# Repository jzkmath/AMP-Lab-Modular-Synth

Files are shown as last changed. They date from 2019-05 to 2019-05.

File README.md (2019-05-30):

# AMP Lab Modular Synth
This is a fully modular eurorack synthesizer project, where I design all the circuits myself, or do designs based off of existing modules.

All PCBs will be designed in KiCAD so that the entire project can be made open source and used by anyone interested. 

## Important Links:
[AMP Lab Project Page](https://sites.google.com/a/vt.edu/amp_lab/projects/modular-eurorack-synth)

[YuSynth](http://yusynth.net/Modular/modular.html) - Basis for some of the designs

[Moog Werkstatt](https://www.moogmusic.com/products/werkstatt-01) - Basis for some of the designs

## VCO
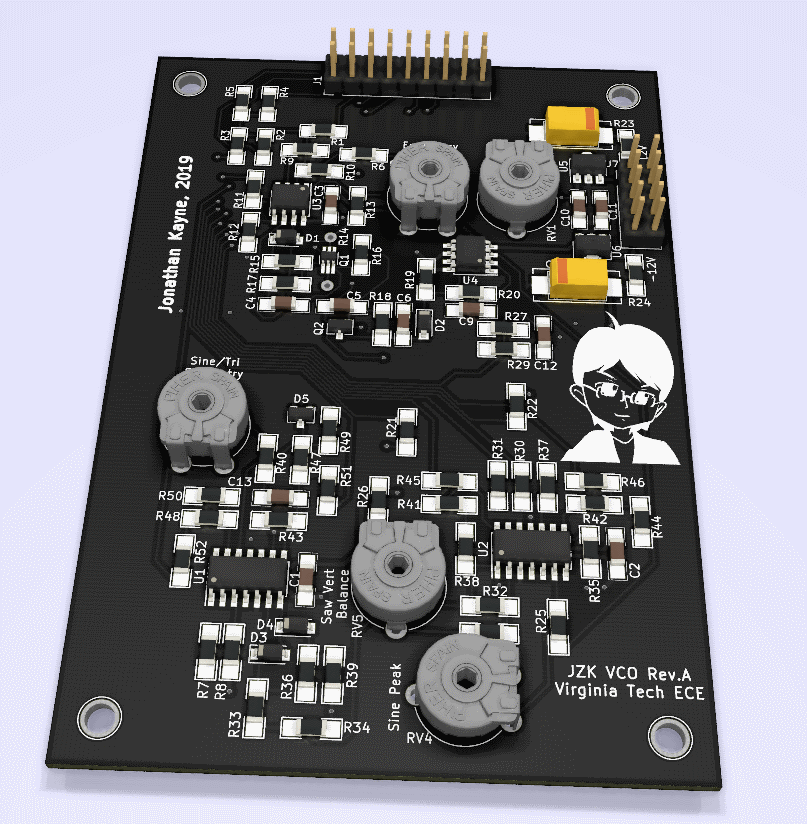
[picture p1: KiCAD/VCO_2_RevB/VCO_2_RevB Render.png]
VCO Render

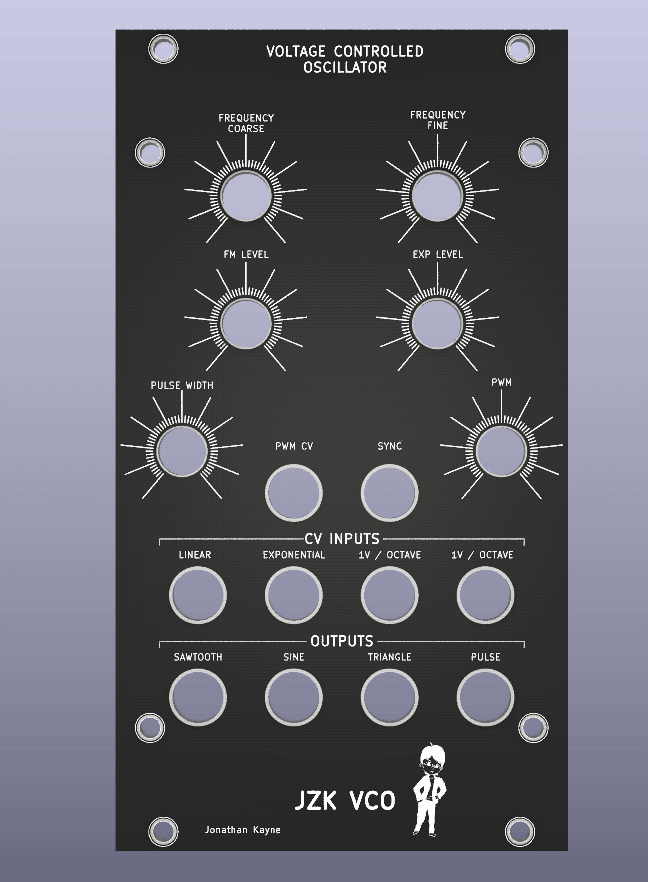
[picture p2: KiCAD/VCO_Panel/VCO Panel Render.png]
VCO Panel


## VCF
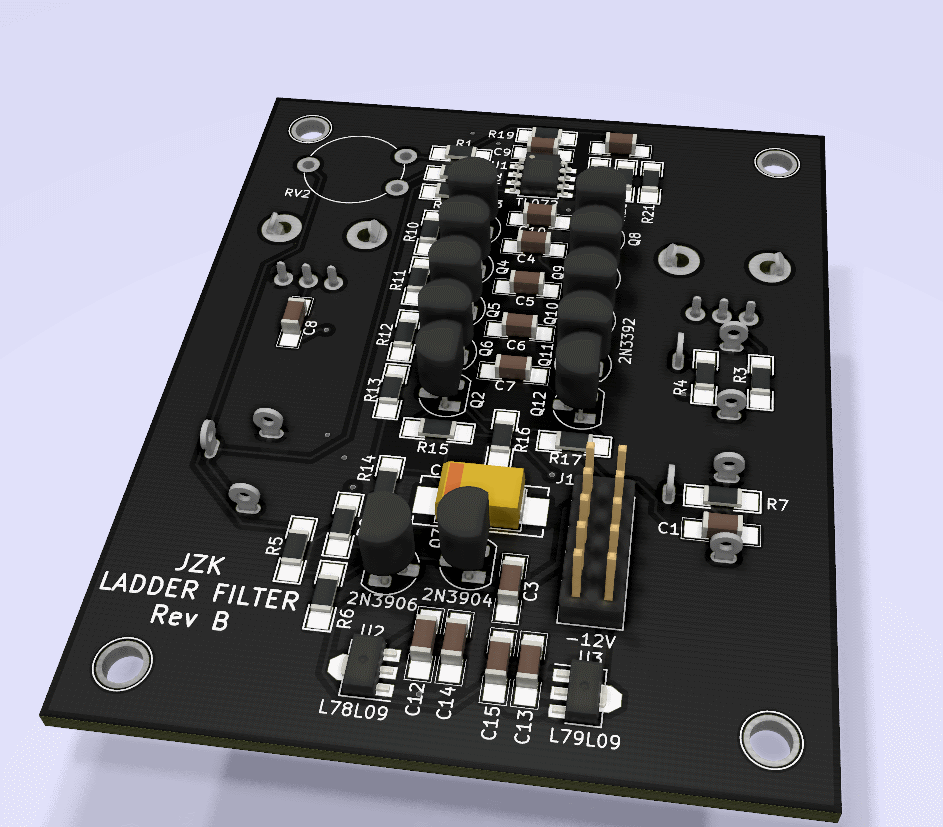
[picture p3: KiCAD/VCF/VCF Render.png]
VCF Render

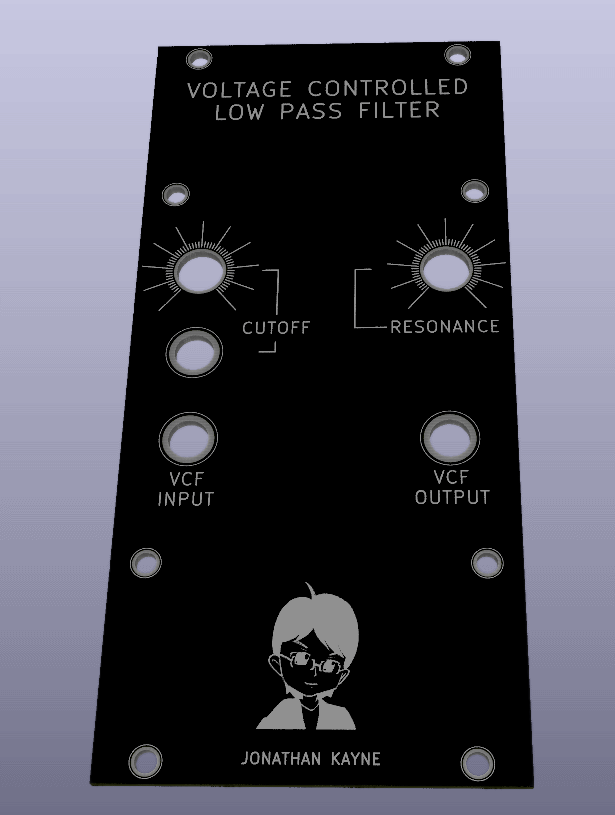
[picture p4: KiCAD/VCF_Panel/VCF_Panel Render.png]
VCF Panel


## EG
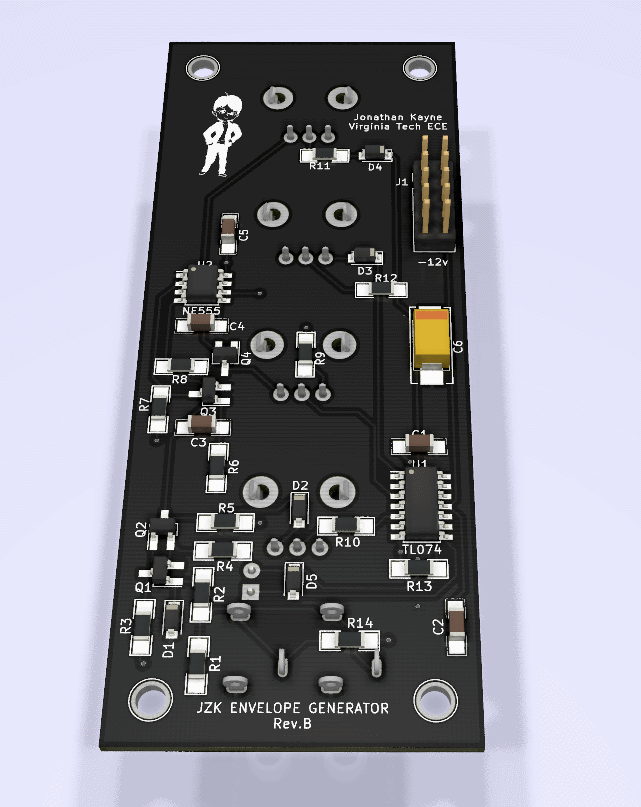
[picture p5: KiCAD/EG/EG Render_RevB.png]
EG Render

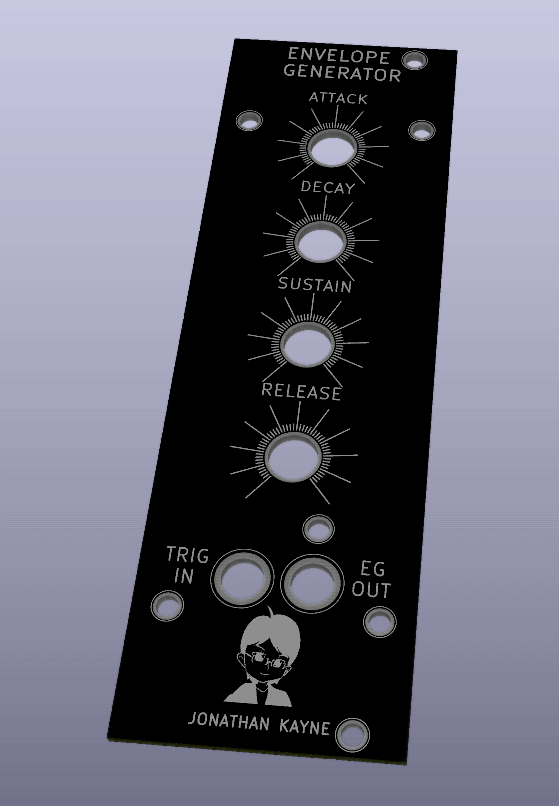
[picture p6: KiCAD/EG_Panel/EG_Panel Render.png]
EG Panel


## VCA
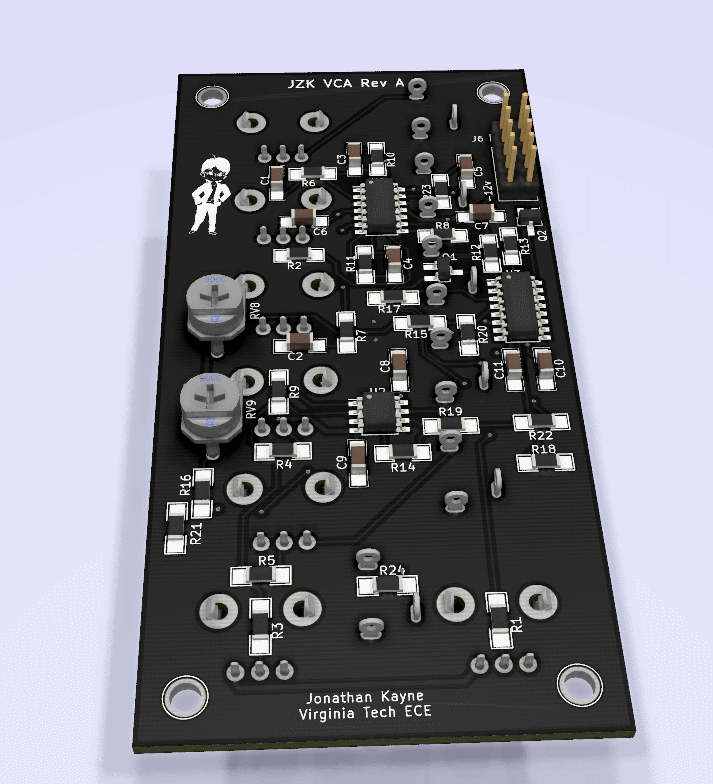
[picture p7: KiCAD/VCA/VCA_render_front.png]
VCA Render

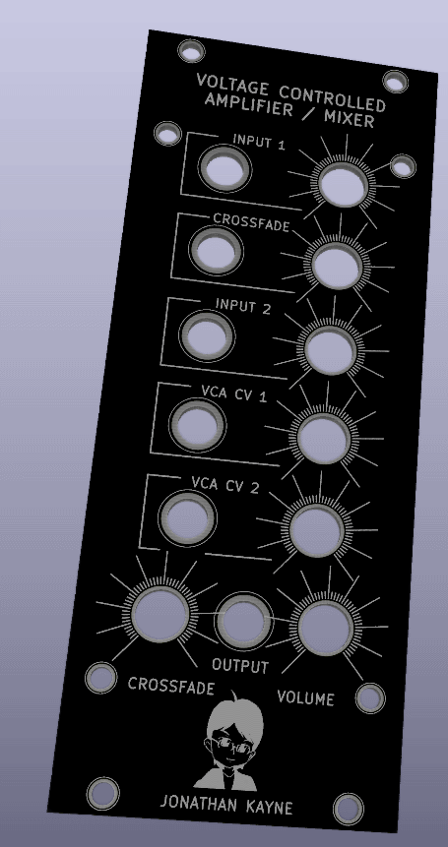
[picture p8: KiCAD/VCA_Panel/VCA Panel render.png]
VCA Panel


## MIDI Controller
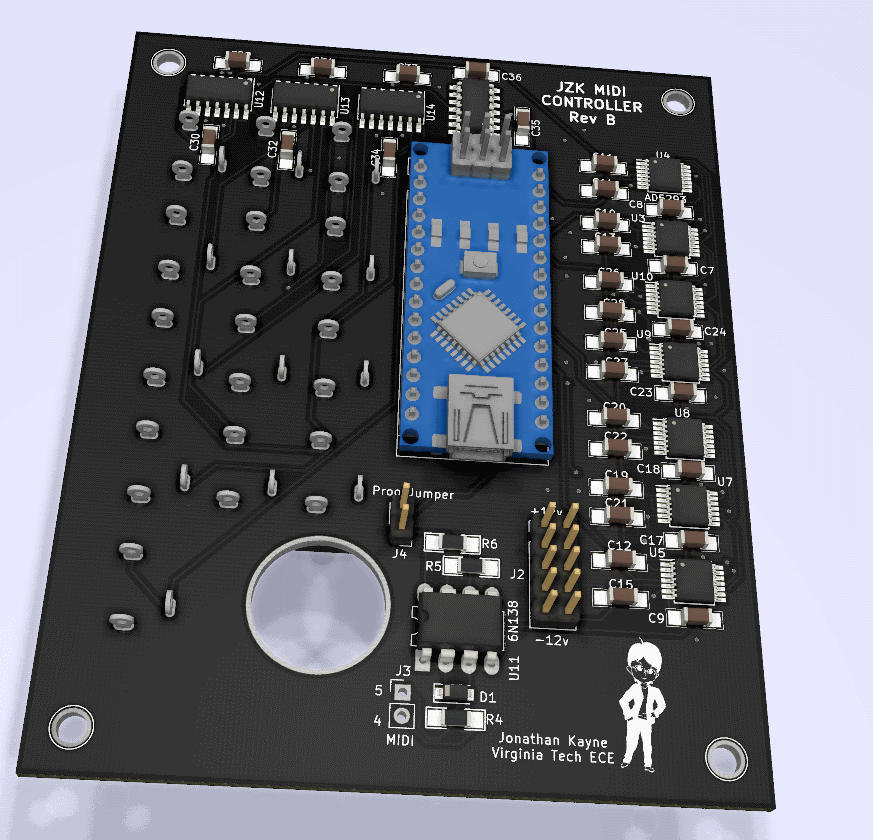
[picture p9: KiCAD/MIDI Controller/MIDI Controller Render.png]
MIDI Render

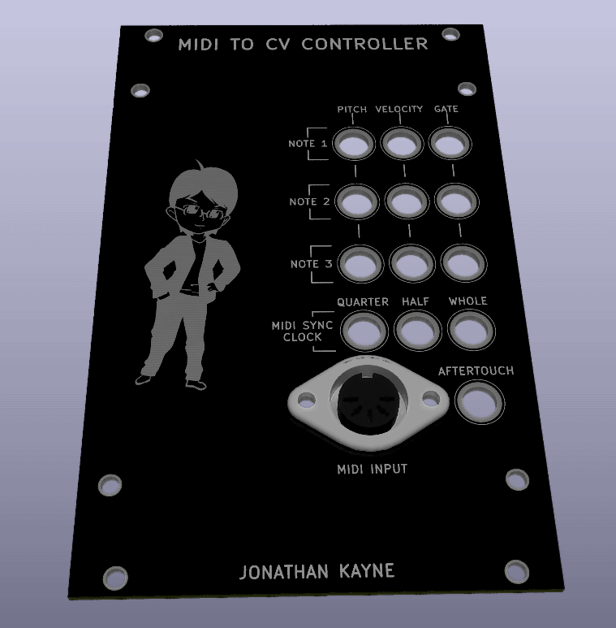
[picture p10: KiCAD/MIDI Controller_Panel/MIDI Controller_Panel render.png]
MIDI Panel


## Power Supply
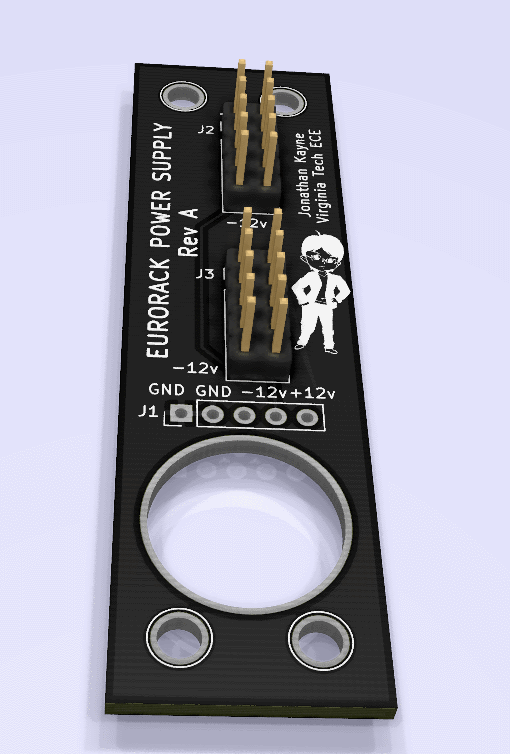
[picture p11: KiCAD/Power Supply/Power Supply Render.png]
PSU Render

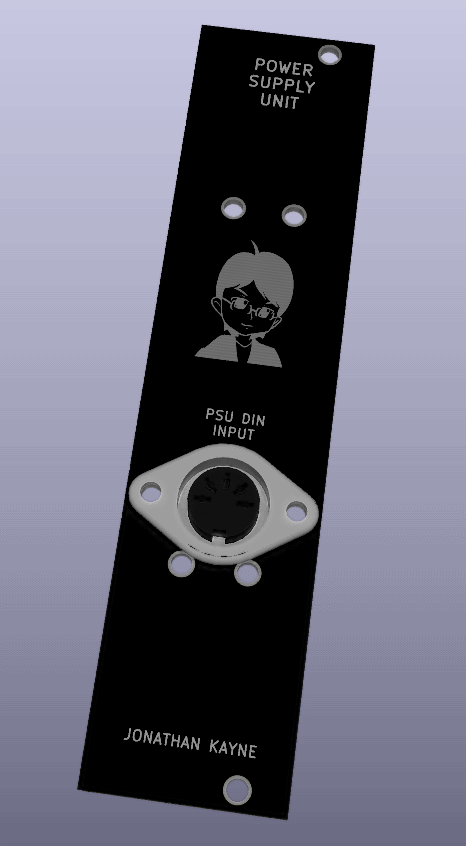
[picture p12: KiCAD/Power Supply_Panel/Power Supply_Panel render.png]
PSU Panel


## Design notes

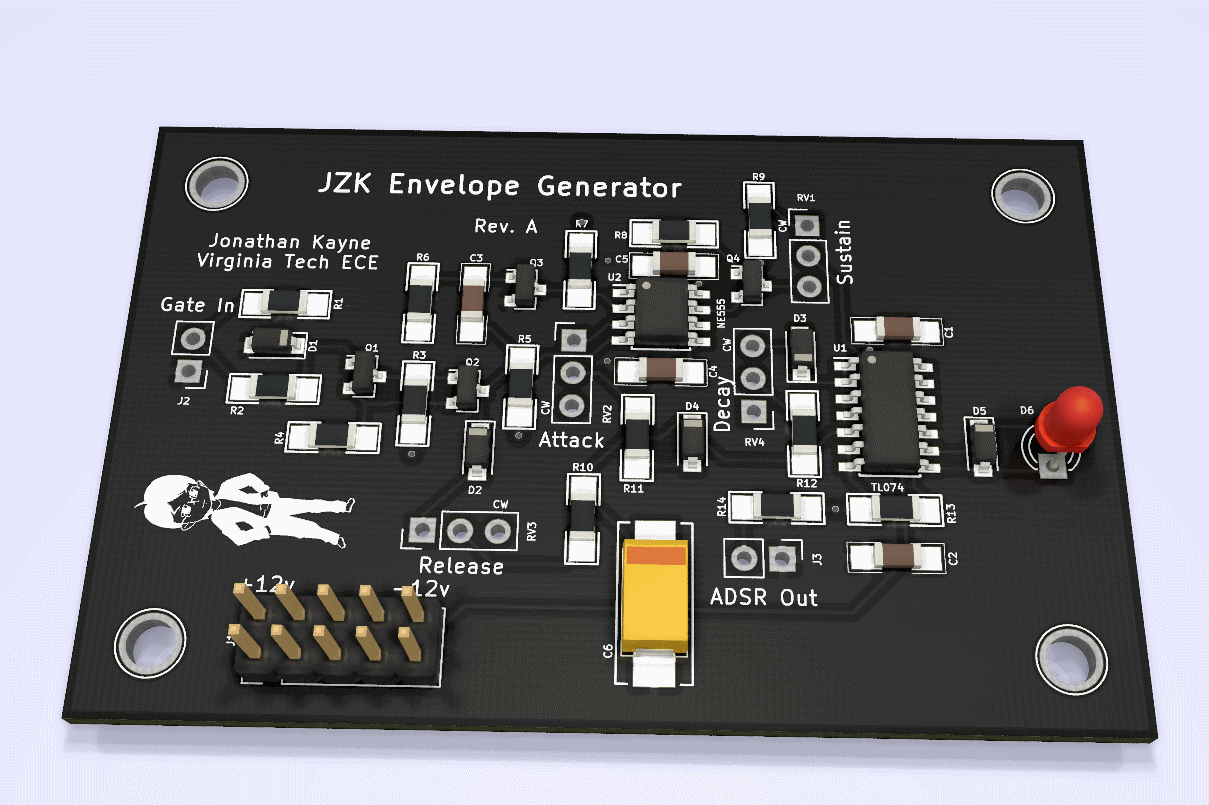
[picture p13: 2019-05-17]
KiCAD/EG/EG Render.png

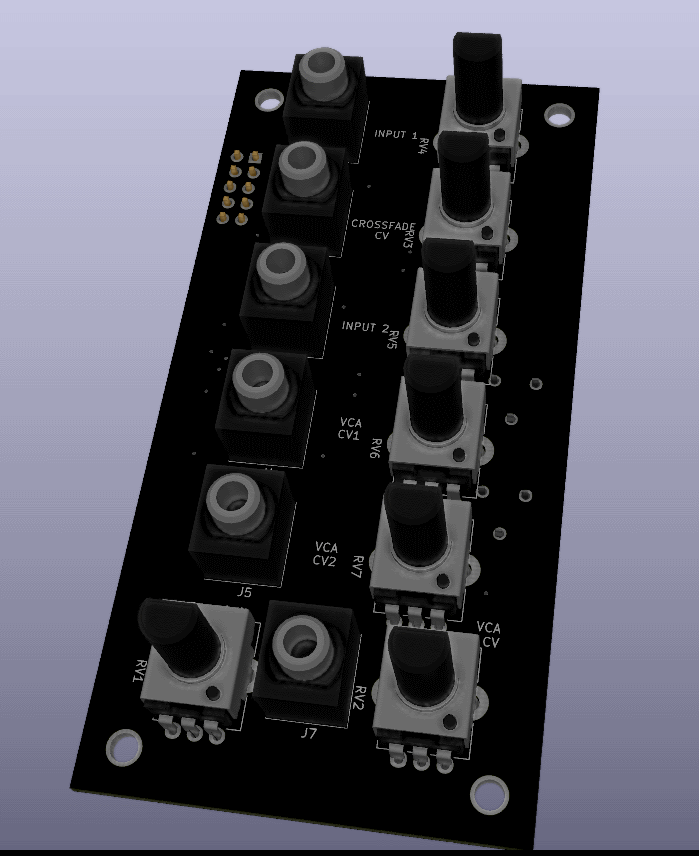
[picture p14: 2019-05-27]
KiCAD/VCA/VCA_render_back.png

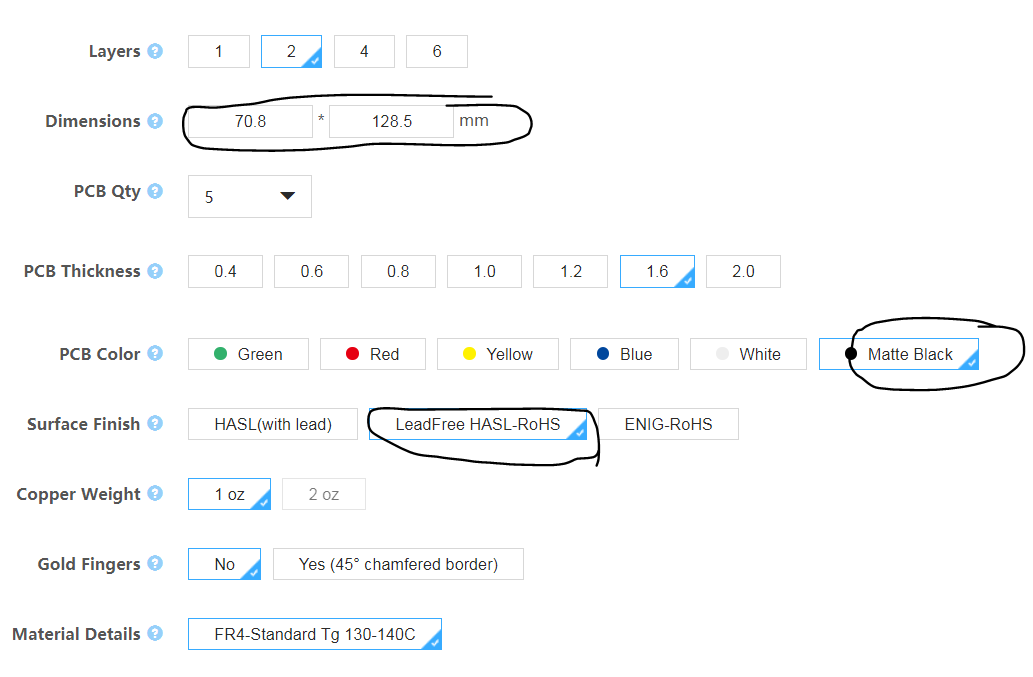
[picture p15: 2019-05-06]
KiCAD/VCO_Panel/Gerber/PCB Quote.PNG

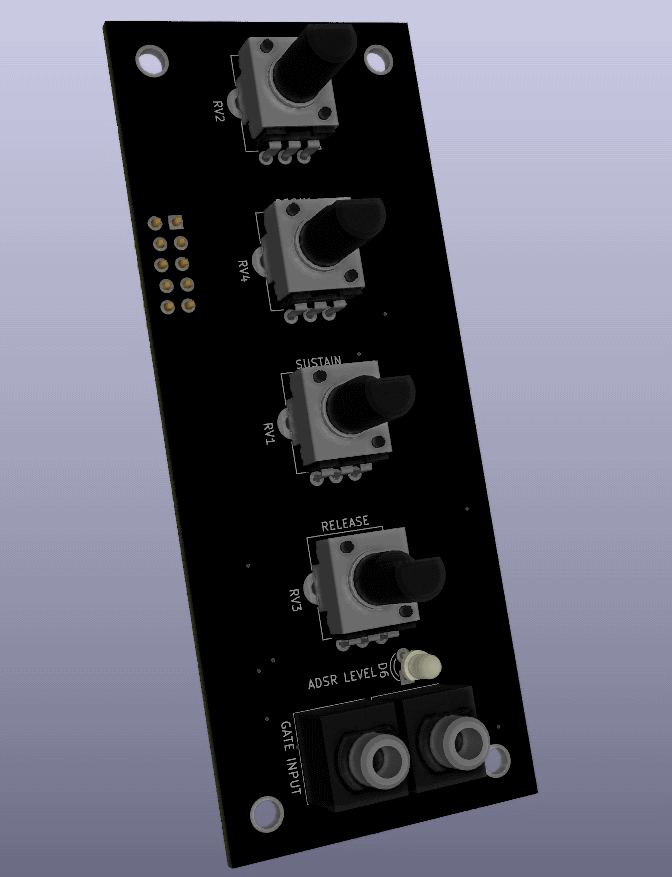
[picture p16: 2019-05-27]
KiCAD/EG/EG Render_RevB_Bottom.png

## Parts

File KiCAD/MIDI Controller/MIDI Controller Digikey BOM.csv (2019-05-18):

Manufacturer Part Number | Manufacturer | Digi-Key Part Number | Customer Reference | Reference Designator | Packaging | Part Status | Quantity | Unit Price | Extended Price | Quantity Available | Mfg Std Lead Time | Description | RoHS Status | Lead Free Status | REACH Status | US Tariff Status
AWSCR-16.00MTD-T | Abracon LLC | 535-9362-1-ND |  |  | Cut Tape (CT) | Active | 5 | 0.41000 | $2.05 | 19006 | 12 Weeks | CER RES 16.0000MHZ 22PF SMD | RoHS Compliant | Contains lead | REACH Affected | Tariff Applied
ATMEGA328P-AUR | Microchip Technology | ATMEGA328P-AURCT-ND |  |  | Cut Tape (CT) | Active | 1 | 2.14000 | $2.14 | 43519 | 7 Weeks | IC MCU 8BIT 32KB FLASH 32TQFP | RoHS Compliant | Lead free | REACH Unaffected
VJ1206Y104KXACW1BC | Vishay Vitramon | 720-1540-1-ND |  |  | Cut Tape (CT) | Active | 30 | 0.23700 | $7.11 | 3905 | 14 Weeks | CAP CER 0.1UF 50V X7R 1206 | RoHS Compliant | Lead free | Not Available | Tariff Eligible
4832.2211 | Schurter Inc. | 486-3418-ND |  |  | Bulk | Active | 13 | 1.50000 | $19.50 | 144 | 23 Weeks | CONN JACK MONO 3.5MM PNL MNT | RoHS Compliant | Lead free | REACH Unaffected
67997-410HLF | Amphenol ICC (FCI) | 609-3243-ND |  |  | Bag | Active | 1 | 0.28000 | $0.28 | 45630 | 7 Weeks | CONN HEADER VERT 10POS 2.54MM | RoHS Compliant | Lead free | Not Available | Tariff Applied
TL074CDR | Texas Instruments | 296-1283-1-ND |  |  | Cut Tape (CT) | Active | 5 | 0.60000 | $3.00 | 70322 | 12 Weeks | IC OPAMP JFET 3MHZ 14SOIC | RoHS Compliant | Lead free | REACH Unaffected
RC1206JR-071KL | Yageo | 311-1.0KERCT-ND |  |  | Cut Tape (CT) | Active | 5 | 0.10000 | $0.50 | 4162550 | 16 Weeks | RES SMD 1K OHM 5% 1/4W 1206 | RoHS Compliant | Lead free | REACH Unaffected | Tariff Applied
CRGCQ1206J4K7 | TE Connectivity Passive Product | A130181CT-ND |  |  | Cut Tape (CT) | Active | 5 | 0.10000 | $0.50 | 101159 | 28 Weeks | CRGCQ 1206 4K7 5% | RoHS Compliant | Lead free | Not Available
RC1206FR-07220RL | Yageo | 311-220FRCT-ND |  |  | Cut Tape (CT) | Active | 5 | 0.10000 | $0.50 | 912819 | 16 Weeks | RES SMD 220 OHM 1% 1/4W 1206 | RoHS Compliant | Lead free | REACH Unaffected | Tariff Eligible
C1206C105K4RACTU | KEMET | 399-1254-1-ND |  |  | Cut Tape (CT) | Active | 10 | 0.15600 | $1.56 | 286401 | 27 Weeks | CAP CER 1UF 16V X7R 1206 | RoHS Compliant | Lead free | REACH Unaffected
C1206C475Z4VACTU | KEMET | 399-1262-1-ND |  |  | Cut Tape (CT) | Active | 5 | 0.27000 | $1.35 | 127000 | 24 Weeks | CAP CER 4.7UF 16V Y5V 1206 | RoHS Compliant | Lead free | REACH Unaffected
1N914 | ON Semiconductor | 1N914FS-ND |  |  | Bulk | Active | 1 | 0.10000 | $0.10 | 48089 | 17 Weeks | DIODE GEN PURP 100V 200MA DO35 | RoHS Compliant | Lead free | REACH Unaffected | Tariff Applied
2040002-1 | TE Connectivity AMP Connectors | A108263CT-ND |  |  | Cut Tape (CT) | Active | 1 | 2.40000 | $2.40 | 8506 | 5 Weeks | CONN RCPT USB2.0 MICRO B SMD R/A | RoHS Compliant | Lead free | Not Available | Tariff Applied
FT232RL-REEL | FTDI, Future Technology Devices International Ltd | 768-1007-1-ND |  |  | Cut Tape (CT) | Active | 1 | 4.50000 | $4.50 | 126000 | 10 Weeks | IC USB FS SERIAL UART 28-SSOP | RoHS Compliant | Lead free | REACH Unaffected
AD5293BRUZ-100-RL7 | Analog Devices Inc. | AD5293BRUZ-100-RL7CT-ND |  |  | Cut Tape (CT) | Active | 10 | 6.21800 | $62.18 | 1884 | 7 Weeks | IC DGTL POT 1024POS 100K 14TSSOP | RoHS Compliant | Lead free | REACH Unaffected
LM1117MP-5.0/NOPB | Texas Instruments | LM1117MP-5.0/NOPBCT-ND |  |  | Cut Tape (CT) | Active | 5 | 1.14000 | $5.70 | 25028 | 6 Weeks | IC REG LINEAR 5V 800MA SOT223 | RoHS Compliant | Lead free | REACH Unaffected
6N138 | Lite-On Inc. | 160-1795-ND |  |  | Tube | Active | 1 | 0.81000 | $0.81 | 4094 | 10 Weeks | OPTOISO 5KV DARL W/BASE 8DIP | RoHS Compliant | Lead free | Not Available
61300211121 | Wurth Electronics Inc. | 732-5315-ND |  |  | Bag | Active | 1 | 0.13000 | $0.13 | 125946 | 14 Weeks | CONN HEADER VERT 2POS 2.54MM | RoHS Compliant | Lead free | REACH Unaffected
QPC02SXGN-RC | Sullins Connector Solutions | S9337-ND |  |  | Bag | Active | 1 | 0.10000 | $0.10 | 389104 | 5 Weeks | CONN JUMPER SHORTING .100" GOLD | RoHS Compliant | Lead free | REACH Unaffected
SD-50SN | CUI Inc. | CP-1250-ND |  |  | Bag | Active | 1 | 3.17000 | $3.17 | 3868 | 11 Weeks | CONN RCPT FMALE DIN 5POS SOLDER | RoHS Compliant | Lead free | Not Available | Tariff Applied

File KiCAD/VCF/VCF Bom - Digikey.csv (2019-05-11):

Manufacturer Part Number | Manufacturer | Digi-Key Part Number | Customer Reference | Reference Designator | Packaging | Part Status | Quantity | Unit Price | Extended Price | Quantity Available | Mfg Std Lead Time | Description | RoHS Status | Lead Free Status | REACH Status | US Tariff Status
T491X107M025AT | KEMET | 399-9749-1-ND |  |  | Cut Tape (CT) | Active | 5 | 2.71000 | $13.55 | 33073 | 12 Weeks | CAP TANT 100UF 20% 25V 2917 | RoHS Compliant | Lead free | REACH Unaffected
2N3392 | Central Semiconductor Corp | 2N3392CS-ND |  |  | Bulk | Active | 10 | 0.66800 | $6.68 | 5219 | 20 Weeks | TRANS NPN 25V TO-92 | RoHS Compliant | Lead free | REACH Unaffected | Tariff Applied
TL072CDR | Texas Instruments | 296-1282-1-ND |  |  | Cut Tape (CT) | Active | 5 | 0.62000 | $3.10 | 60071 | 6 Weeks | IC OPAMP JFET 3MHZ 8SOIC | RoHS Compliant | Lead free | REACH Unaffected
CL31B104KBCNNNC | Samsung Electro-Mechanics | 1276-1017-1-ND |  |  | Cut Tape (CT) | Active | 10 | 0.08800 | $0.88 | 21218 | Not Available | CAP CER 0.1UF 50V X7R 1206 | RoHS Compliant | Lead free | REACH Unaffected
67997-410HLF | Amphenol ICC (FCI) | 609-3243-ND |  |  | Bag | Active | 1 | 0.28000 | $0.28 | 46149 | 7 Weeks | CONN HEADER VERT 10POS 2.54MM | RoHS Compliant | Lead free | Not Available | Tariff Applied
4832.2211 | Schurter Inc. | 486-3418-ND |  |  | Bulk | Active | 3 | 1.50000 | $4.50 | 244 | 23 Weeks | CONN JACK MONO 3.5MM PNL MNT | RoHS Compliant | Lead free | REACH Unaffected
CRGCQ1206F100K | TE Connectivity Passive Product | A129834CT-ND |  |  | Cut Tape (CT) | Active | 5 | 0.10000 | $0.50 | 105746 | 28 Weeks | CRGCQ 1206 100K 1% | RoHS Compliant | Lead free | Not Available
PT10MV10-103A2020-S | Amphenol Piher Sensing Systems | 1993-1104-ND |  |  | Bulk | Active | 1 | 0.46000 | $0.46 | 6282 | 6 Weeks | POT 10K OHM LINEAR | RoHS Compliant | Lead free | Not Available
P160KNP-0EC15B25K | TT Electronics/BI | 987-1726-ND |  |  | Tray | Active | 2 | 0.79000 | $1.58 | 663 | 10 Weeks | POT 25K OHM 1/5W PLASTIC LINEAR | RoHS Compliant | Lead free | REACH Unaffected | Tariff Eligible
RMCF1206JT33K0 | Stackpole Electronics Inc | RMCF1206JT33K0CT-ND |  |  | Cut Tape (CT) | Active | 5 | 0.10000 | $0.50 | 49098 | 17 Weeks | RES 33K OHM 5% 1/4W 1206 | RoHS Compliant | Lead free | REACH Unaffected | Tariff Applied
RNCP1206FTD4K99 | Stackpole Electronics Inc | RNCP1206FTD4K99CT-ND |  |  | Cut Tape (CT) | Active | 5 | 0.10000 | $0.50 | 87951 | 18 Weeks | RES 4.99K OHM 1% 1/2W 1206 | RoHS Compliant | Lead free | REACH Unaffected
RNCP1206FTD68K1 | Stackpole Electronics Inc | RNCP1206FTD68K1CT-ND |  |  | Cut Tape (CT) | Active | 5 | 0.10000 | $0.50 | 135983 | 18 Weeks | RES 68.1K OHM 1% 1/2W 1206 | RoHS Compliant | Lead free | REACH Unaffected
RNCP1206FTD1K00 | Stackpole Electronics Inc | RNCP1206FTD1K00CT-ND |  |  | Cut Tape (CT) | Active | 10 | 0.09300 | $0.93 | 650800 | 18 Weeks | RES 1K OHM 1% 1/2W 1206 | RoHS Compliant | Lead free | REACH Unaffected
CRGCQ1206F12K | TE Connectivity Passive Product | A129823CT-ND |  |  | Cut Tape (CT) | Active | 5 | 0.10000 | $0.50 | 30562 | 28 Weeks | CRGCQ 1206 12K 1% | RoHS Compliant | Lead free | Not Available
RC1206FR-072K74L | Yageo | 311-2.74KFRCT-ND |  |  | Cut Tape (CT) | Active | 5 | 0.10000 | $0.50 | 97937 | 16 Weeks | RES SMD 2.74K OHM 1% 1/4W 1206 | RoHS Compliant | Lead free | REACH Unaffected | Tariff Applied
RNCP1206FTD100R | Stackpole Electronics Inc | RNCP1206FTD100RCT-ND |  |  | Cut Tape (CT) | Active | 5 | 0.10000 | $0.50 | 824311 | 18 Weeks | RES 100 OHM 1% 1/2W 1206 | RoHS Compliant | Lead free | REACH Unaffected
RNCP1206FTD6K81 | Stackpole Electronics Inc | RNCP1206FTD6K81CT-ND |  |  | Cut Tape (CT) | Active | 5 | 0.10000 | $0.50 | 15785 | 18 Weeks | RES 6.81K OHM 1% 1/2W 1206 | RoHS Compliant | Lead free | REACH Unaffected
CL31B225KAHNNNE | Samsung Electro-Mechanics | 1276-1072-1-ND |  |  | Cut Tape (CT) | Active | 5 | 0.22000 | $1.10 | 419041 | Not Available | CAP CER 2.2UF 25V X7R 1206 | RoHS Compliant | Lead free | REACH Unaffected

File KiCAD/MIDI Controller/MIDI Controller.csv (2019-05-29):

Source: | C:\Users\Jonathan Kayne\Documents\KiCAD\Modular Synth\MIDI Controller\MIDI Controller.sch
Date: | 05/26/19 18:08:59
Tool: | Eeschema (5.1.0)-1
Generator: | C:\Program Files\KiCad\bin\scripting\plugins/bom_csv_grouped_by_value.py
Component Count: | 62
Individual Components:
Item | Qty | Reference(s) | Value | LibPart | Footprint | Datasheet | Digikey Link | Digikey PN | Field4 | Field5 | Field6 | Field7 | Field8 | Field9 | Unit Price
 |  | A1 | Arduino_Nano_v3.x | MCU_Module:Arduino_Nano_v3.x | Module:Arduino_Nano | http://www.mouser.com/pdfdocs/Gravitech_Arduino_Nano3_0.pdf | https://smile.amazon.com/dp/B00NLAMS9C | B00NLAMS9C |  |  |  |  |  |  | 8.99
 |  | C7 | 1uF | Device:C | Synth:C_1206 | ~ | https://www.digikey.com/short/p4nrpn | 399-1254-1-ND |  |  |  |  |  |  | 0.23
 |  | C8 | 1uF | Device:C | Synth:C_1206 | ~ | https://www.digikey.com/short/p4nrpn | 399-1254-1-ND |  |  |  |  |  |  | 0.23
 |  | C9 | 1uF | Device:C | Synth:C_1206 | ~ | https://www.digikey.com/short/p4nrpn | 399-1254-1-ND |  |  |  |  |  |  | 0.23
 |  | C10 | 0.1uF | Device:C | Synth:C_1206 | ~ | https://www.digikey.com/short/p4nr3m | 720-1540-1-ND |  |  |  |  |  |  | 0.237
 |  | C11 | 0.1uF | Device:C | Synth:C_1206 | ~ | https://www.digikey.com/short/p4nr3m | 720-1540-1-ND |  |  |  |  |  |  | 0.237
 |  | C12 | 0.1uF | Device:C | Synth:C_1206 | ~ | https://www.digikey.com/short/p4nr3m | 720-1540-1-ND |  |  |  |  |  |  | 0.237
 |  | C13 | 0.1uF | Device:C | Synth:C_1206 | ~ | https://www.digikey.com/short/p4nr3m | 720-1540-1-ND |  |  |  |  |  |  | 0.237
 |  | C14 | 0.1uF | Device:C | Synth:C_1206 | ~ | https://www.digikey.com/short/p4nr3m | 720-1540-1-ND |  |  |  |  |  |  | 0.237
 |  | C15 | 0.1uF | Device:C | Synth:C_1206 | ~ | https://www.digikey.com/short/p4nr3m | 720-1540-1-ND |  |  |  |  |  |  | 0.237
 |  | C17 | 1uF | Device:C | Synth:C_1206 | ~ | https://www.digikey.com/short/p4nrpn | 399-1254-1-ND |  |  |  |  |  |  | 0.23
 |  | C18 | 1uF | Device:C | Synth:C_1206 | ~ | https://www.digikey.com/short/p4nrpn | 399-1254-1-ND |  |  |  |  |  |  | 0.23
 |  | C19 | 0.1uF | Device:C | Synth:C_1206 | ~ | https://www.digikey.com/short/p4nr3m | 720-1540-1-ND |  |  |  |  |  |  | 0.237
 |  | C20 | 0.1uF | Device:C | Synth:C_1206 | ~ | https://www.digikey.com/short/p4nr3m | 720-1540-1-ND |  |  |  |  |  |  | 0.237
 |  | C21 | 0.1uF | Device:C | Synth:C_1206 | ~ | https://www.digikey.com/short/p4nr3m | 720-1540-1-ND |  |  |  |  |  |  | 0.237
 |  | C22 | 0.1uF | Device:C | Synth:C_1206 | ~ | https://www.digikey.com/short/p4nr3m | 720-1540-1-ND |  |  |  |  |  |  | 0.237
 |  | C23 | 1uF | Device:C | Synth:C_1206 | ~ | https://www.digikey.com/short/p4nrpn | 399-1254-1-ND |  |  |  |  |  |  | 0.23
 |  | C24 | 1uF | Device:C | Synth:C_1206 | ~ | https://www.digikey.com/short/p4nrpn | 399-1254-1-ND |  |  |  |  |  |  | 0.23
 |  | C25 | 0.1uF | Device:C | Synth:C_1206 | ~ | https://www.digikey.com/short/p4nr3m | 720-1540-1-ND |  |  |  |  |  |  | 0.237
 |  | C26 | 0.1uF | Device:C | Synth:C_1206 | ~ | https://www.digikey.com/short/p4nr3m | 720-1540-1-ND |  |  |  |  |  |  | 0.237
 |  | C27 | 0.1uF | Device:C | Synth:C_1206 | ~ | https://www.digikey.com/short/p4nr3m | 720-1540-1-ND |  |  |  |  |  |  | 0.237
 |  | C28 | 0.1uF | Device:C | Synth:C_1206 | ~ | https://www.digikey.com/short/p4nr3m | 720-1540-1-ND |  |  |  |  |  |  | 0.237
 |  | C29 | 0.1uF | Device:C | Synth:C_1206 | ~ | https://www.digikey.com/short/p4nr3m | 720-1540-1-ND |  |  |  |  |  |  | 0.237
 |  | C30 | 0.1uF | Device:C | Synth:C_1206 | ~ | https://www.digikey.com/short/p4nr3m | 720-1540-1-ND |  |  |  |  |  |  | 0.237
 |  | C31 | 0.1uF | Device:C | Synth:C_1206 | ~ | https://www.digikey.com/short/p4nr3m | 720-1540-1-ND |  |  |  |  |  |  | 0.237
 |  | C32 | 0.1uF | Device:C | Synth:C_1206 | ~ | https://www.digikey.com/short/p4nr3m | 720-1540-1-ND |  |  |  |  |  |  | 0.237
 |  | C33 | 0.1uF | Device:C | Synth:C_1206 | ~ | https://www.digikey.com/short/p4nr3m | 720-1540-1-ND |  |  |  |  |  |  | 0.237
 |  | C34 | 0.1uF | Device:C | Synth:C_1206 | ~ | https://www.digikey.com/short/p4nr3m | 720-1540-1-ND |  |  |  |  |  |  | 0.237
 |  | C35 | 0.1uF | Device:C | Synth:C_1206 | ~ | https://www.digikey.com/short/p4nr3m | 720-1540-1-ND |  |  |  |  |  |  | 0.237
 |  | C36 | 0.1uF | Device:C | Synth:C_1206 | ~ | https://www.digikey.com/short/p4nr3m | 720-1540-1-ND |  |  |  |  |  |  | 0.237
 |  | D1 | 1N4148W | Device:D | Synth:D_SOD-123 | ~ | https://www.digikey.com/short/p4nrz9 | 1N4148WTPMSCT-ND |  |  |  |  |  |  | 0.131
 |  | J2 | Power | Connector_Generic:Conn_02x05_Odd_Even | Synth:PinHeader_2x05_P2.54mm_Vertical_Zigzag | ~ | https://www.digikey.com/short/p4nr84 | 609-3243-ND |  |  |  |  |  |  | 0.27
 |  | J3 | MIDI | Connector:DIN-5_180degree | Connector_PinHeader_2.54mm:PinHeader_1x02_P2.54mm_Vertical | http://www.mouser.com/ds/2/18/40_c091_abd_e-75918.pdf | https://www.digikey.com/short/p4nrpz | CP-1250-ND |  |  |  |  |  |  | 2.99
 |  | J4 | Prog Jumper | Connector_Generic:Conn_01x02 | Connector_PinHeader_2.54mm:PinHeader_1x02_P2.54mm_Vertical | ~ | https://www.digikey.com/short/p4nrjv | 732-5315-ND |  |  |  |  |  |  | 0.13
 |  | J5 | 4832 | Synth:MJ-3502 | Synth:Schurter_4832_Jack | https://www.digikey.com/product-detail/en/cui-inc/MJ-3502/CP-3502MJ-ND/281321 | https://www.digikey.com/short/p4nrqw | 486-3418-ND | CP-3502MJ-ND | None | MJ-3502 | https://www.cui.com/product/interconnect/connectors/audio-connectors/jacks/mj-3502 | 3.5 mm, Mono, Right Angle, Through Hole, Threaded Bushing, Audio Jack Connector | CUI Inc. | 1.50
 |  | J6 | 4832 | Synth:MJ-3502 | Synth:Schurter_4832_Jack | https://www.digikey.com/product-detail/en/cui-inc/MJ-3502/CP-3502MJ-ND/281321 | https://www.digikey.com/short/p4nrqw | 486-3418-ND | CP-3502MJ-ND | None | MJ-3502 | https://www.cui.com/product/interconnect/connectors/audio-connectors/jacks/mj-3502 | 3.5 mm, Mono, Right Angle, Through Hole, Threaded Bushing, Audio Jack Connector | CUI Inc. | 1.50
 |  | J7 | 4832 | Synth:MJ-3502 | Synth:Schurter_4832_Jack | https://www.digikey.com/product-detail/en/cui-inc/MJ-3502/CP-3502MJ-ND/281321 | https://www.digikey.com/short/p4nrqw | 486-3418-ND | CP-3502MJ-ND | None | MJ-3502 | https://www.cui.com/product/interconnect/connectors/audio-connectors/jacks/mj-3502 | 3.5 mm, Mono, Right Angle, Through Hole, Threaded Bushing, Audio Jack Connector | CUI Inc. | 1.50
 |  | J8 | 4832 | Synth:MJ-3502 | Synth:Schurter_4832_Jack | https://www.digikey.com/product-detail/en/cui-inc/MJ-3502/CP-3502MJ-ND/281321 | https://www.digikey.com/short/p4nrqw | 486-3418-ND | CP-3502MJ-ND | None | MJ-3502 | https://www.cui.com/product/interconnect/connectors/audio-connectors/jacks/mj-3502 | 3.5 mm, Mono, Right Angle, Through Hole, Threaded Bushing, Audio Jack Connector | CUI Inc. | 1.50
 |  | J9 | 4832 | Synth:MJ-3502 | Synth:Schurter_4832_Jack | https://www.digikey.com/product-detail/en/cui-inc/MJ-3502/CP-3502MJ-ND/281321 | https://www.digikey.com/short/p4nrqw | 486-3418-ND | CP-3502MJ-ND | None | MJ-3502 | https://www.cui.com/product/interconnect/connectors/audio-connectors/jacks/mj-3502 | 3.5 mm, Mono, Right Angle, Through Hole, Threaded Bushing, Audio Jack Connector | CUI Inc. | 1.50
 |  | J10 | 4832 | Synth:MJ-3502 | Synth:Schurter_4832_Jack | https://www.digikey.com/product-detail/en/cui-inc/MJ-3502/CP-3502MJ-ND/281321 | https://www.digikey.com/short/p4nrqw | 486-3418-ND | CP-3502MJ-ND | None | MJ-3502 | https://www.cui.com/product/interconnect/connectors/audio-connectors/jacks/mj-3502 | 3.5 mm, Mono, Right Angle, Through Hole, Threaded Bushing, Audio Jack Connector | CUI Inc. | 1.50
 |  | J11 | 4832 | Synth:MJ-3502 | Synth:Schurter_4832_Jack | https://www.digikey.com/product-detail/en/cui-inc/MJ-3502/CP-3502MJ-ND/281321 | https://www.digikey.com/short/p4nrqw | 486-3418-ND | CP-3502MJ-ND | None | MJ-3502 | https://www.cui.com/product/interconnect/connectors/audio-connectors/jacks/mj-3502 | 3.5 mm, Mono, Right Angle, Through Hole, Threaded Bushing, Audio Jack Connector | CUI Inc. | 1.50
 |  | J12 | 4832 | Synth:MJ-3502 | Synth:Schurter_4832_Jack | https://www.digikey.com/product-detail/en/cui-inc/MJ-3502/CP-3502MJ-ND/281321 | https://www.digikey.com/short/p4nrqw | 486-3418-ND | CP-3502MJ-ND | None | MJ-3502 | https://www.cui.com/product/interconnect/connectors/audio-connectors/jacks/mj-3502 | 3.5 mm, Mono, Right Angle, Through Hole, Threaded Bushing, Audio Jack Connector | CUI Inc. | 1.50
 |  | J13 | 4832 | Synth:MJ-3502 | Synth:Schurter_4832_Jack | https://www.digikey.com/product-detail/en/cui-inc/MJ-3502/CP-3502MJ-ND/281321 | https://www.digikey.com/short/p4nrqw | 486-3418-ND | CP-3502MJ-ND | None | MJ-3502 | https://www.cui.com/product/interconnect/connectors/audio-connectors/jacks/mj-3502 | 3.5 mm, Mono, Right Angle, Through Hole, Threaded Bushing, Audio Jack Connector | CUI Inc. | 1.50
 |  | J14 | 4832 | Synth:MJ-3502 | Synth:Schurter_4832_Jack | https://www.digikey.com/product-detail/en/cui-inc/MJ-3502/CP-3502MJ-ND/281321 | https://www.digikey.com/short/p4nrqw | 486-3418-ND | CP-3502MJ-ND | None | MJ-3502 | https://www.cui.com/product/interconnect/connectors/audio-connectors/jacks/mj-3502 | 3.5 mm, Mono, Right Angle, Through Hole, Threaded Bushing, Audio Jack Connector | CUI Inc. | 1.50
 |  | J15 | 4832 | Synth:MJ-3502 | Synth:Schurter_4832_Jack | https://www.digikey.com/product-detail/en/cui-inc/MJ-3502/CP-3502MJ-ND/281321 | https://www.digikey.com/short/p4nrqw | 486-3418-ND | CP-3502MJ-ND | None | MJ-3502 | https://www.cui.com/product/interconnect/connectors/audio-connectors/jacks/mj-3502 | 3.5 mm, Mono, Right Angle, Through Hole, Threaded Bushing, Audio Jack Connector | CUI Inc. | 1.50
 |  | J16 | 4832 | Synth:MJ-3502 | Synth:Schurter_4832_Jack | https://www.digikey.com/product-detail/en/cui-inc/MJ-3502/CP-3502MJ-ND/281321 | https://www.digikey.com/short/p4nrqw | 486-3418-ND | CP-3502MJ-ND | None | MJ-3502 | https://www.cui.com/product/interconnect/connectors/audio-connectors/jacks/mj-3502 | 3.5 mm, Mono, Right Angle, Through Hole, Threaded Bushing, Audio Jack Connector | CUI Inc. | 1.50
 |  | J17 | 4832 | Synth:MJ-3502 | Synth:Schurter_4832_Jack | https://www.digikey.com/product-detail/en/cui-inc/MJ-3502/CP-3502MJ-ND/281321 | https://www.digikey.com/short/p4nrqw | 486-3418-ND | CP-3502MJ-ND | None | MJ-3502 | https://www.cui.com/product/interconnect/connectors/audio-connectors/jacks/mj-3502 | 3.5 mm, Mono, Right Angle, Through Hole, Threaded Bushing, Audio Jack Connector | CUI Inc. | 1.50
 |  | R4 | 220 | Device:R | Synth:R_1206 | ~ | https://www.digikey.com/short/p4nrjp | 311-220FRCT-ND |  |  |  |  |  |  | 0.10
 |  | R5 | 4.7k | Device:R | Synth:R_1206 | ~ | https://www.digikey.com/short/p4nr81 | A130181CT-ND |  |  |  |  |  |  | 0.10
 |  | R6 | 220 | Device:R | Synth:R_1206 | ~ | https://www.digikey.com/short/p4nrjp | 311-220FRCT-ND |  |  |  |  |  |  | 0.10
 |  | U3 | AD5293 | Potentiometer_Digital:AD5293 | Package_SO:TSSOP-14_4.4x5mm_P0.65mm | https://www.analog.com/media/en/technical-documentation/data-sheets/AD5293.pdf | https://www.digikey.com/short/pzd8zr | AD5293BRUZ-100-RL7CT-ND |  |  |  |  |  |  | 6.88
 |  | U4 | AD5293 | Potentiometer_Digital:AD5293 | Package_SO:TSSOP-14_4.4x5mm_P0.65mm | https://www.analog.com/media/en/technical-documentation/data-sheets/AD5293.pdf | https://www.digikey.com/short/pzd8zr | AD5293BRUZ-100-RL7CT-ND |  |  |  |  |  |  | 6.88
 |  | U5 | AD5293 | Potentiometer_Digital:AD5293 | Package_SO:TSSOP-14_4.4x5mm_P0.65mm | https://www.analog.com/media/en/technical-documentation/data-sheets/AD5293.pdf | https://www.digikey.com/short/pzd8zr | AD5293BRUZ-100-RL7CT-ND |  |  |  |  |  |  | 6.88
 |  | U7 | AD5293 | Potentiometer_Digital:AD5293 | Package_SO:TSSOP-14_4.4x5mm_P0.65mm | https://www.analog.com/media/en/technical-documentation/data-sheets/AD5293.pdf | https://www.digikey.com/short/pzd8zr | AD5293BRUZ-100-RL7CT-ND |  |  |  |  |  |  | 6.88
 |  | U8 | AD5293 | Potentiometer_Digital:AD5293 | Package_SO:TSSOP-14_4.4x5mm_P0.65mm | https://www.analog.com/media/en/technical-documentation/data-sheets/AD5293.pdf | https://www.digikey.com/short/pzd8zr | AD5293BRUZ-100-RL7CT-ND |  |  |  |  |  |  | 6.88
 |  | U9 | AD5293 | Potentiometer_Digital:AD5293 | Package_SO:TSSOP-14_4.4x5mm_P0.65mm | https://www.analog.com/media/en/technical-documentation/data-sheets/AD5293.pdf | https://www.digikey.com/short/pzd8zr | AD5293BRUZ-100-RL7CT-ND |  |  |  |  |  |  | 6.88
 |  | U10 | AD5293 | Potentiometer_Digital:AD5293 | Package_SO:TSSOP-14_4.4x5mm_P0.65mm | https://www.analog.com/media/en/technical-documentation/data-sheets/AD5293.pdf | https://www.digikey.com/short/pzd8zr | AD5293BRUZ-100-RL7CT-ND |  |  |  |  |  |  | 6.88
 |  | U11 | 6N138 | Isolator:6N138 | Package_DIP:DIP-8_W7.62mm_LongPads | http://www.onsemi.com/pub/Collateral/HCPL2731-D.pdf | https://www.digikey.com/short/p4nrj5 | 160-1795-ND |  |  |  |  |  |  | 0.81
 |  | U12 | TL074 | Amplifier_Operational:TL074 | Package_SO:SOIC-14_3.9x8.7mm_P1.27mm | http://www.ti.com/lit/ds/symlink/tl071.pdf | https://www.digikey.com/short/p4nr82 | 296-1283-1-ND |  |  |  |  |  |  | 0.60
 |  | U13 | TL074 | Amplifier_Operational:TL074 | Package_SO:SOIC-14_3.9x8.7mm_P1.27mm | http://www.ti.com/lit/ds/symlink/tl071.pdf | https://www.digikey.com/short/p4nr82 | 296-1283-1-ND |  |  |  |  |  |  | 0.60
 |  | U14 | TL074 | Amplifier_Operational:TL074 | Package_SO:SOIC-14_3.9x8.7mm_P1.27mm | http://www.ti.com/lit/ds/symlink/tl071.pdf | https://www.digikey.com/short/p4nr82 | 296-1283-1-ND |  |  |  |  |  |  | 0.60
 |  | U15 | TL074 | Amplifier_Operational:TL074 | Package_SO:SOIC-14_3.9x8.7mm_P1.27mm | http://www.ti.com/lit/ds/symlink/tl071.pdf | https://www.digikey.com/short/p4nr82 | 296-1283-1-ND |  |  |  |  |  |  | 0.60
Collated Components:
Item | Qty | Reference(s) | Value | LibPart | Footprint | Datasheet | Digikey Link | Digikey PN | Field4 | Field5 | Field6 | Field7 | Field8 | Field9 | Unit Price
1 | 1 | A1 | Arduino_Nano_v3.x | MCU_Module:Arduino_Nano_v3.x | Module:Arduino_Nano | http://www.mouser.com/pdfdocs/Gravitech_Arduino_Nano3_0.pdf | https://smile.amazon.com/dp/B00NLAMS9C | B00NLAMS9C |  |  |  |  |  |  | 8.99
2 | 7 | C7, C8, C9, C17, C18, C23, C24 | 1uF | Device:C | Synth:C_1206 | ~ | https://www.digikey.com/short/p4nrpn | 399-1254-1-ND |  |  |  |  |  |  | 0.23
3 | 22 | C10, C11, C12, C13, C14, C15, C19, C20, C21, C22, C25, C26, C27, C28, C29, C30, C31, C32, C33, C34, C35, C36 | 0.1uF | Device:C | Synth:C_1206 | ~ | https://www.digikey.com/short/p4nr3m | 720-1540-1-ND |  |  |  |  |  |  | 0.237
4 | 1 | D1 | 1N4148W | Device:D | Synth:D_SOD-123 | ~ | https://www.digikey.com/short/p4nrz9 | 1N4148WTPMSCT-ND |  |  |  |  |  |  | 0.131
5 | 1 | J2 | Power | Connector_Generic:Conn_02x05_Odd_Even | Synth:PinHeader_2x05_P2.54mm_Vertical_Zigzag | ~ | https://www.digikey.com/short/p4nr84 | 609-3243-ND |  |  |  |  |  |  | 0.27
6 | 1 | J3 | MIDI | Connector:DIN-5_180degree | Connector_PinHeader_2.54mm:PinHeader_1x02_P2.54mm_Vertical | http://www.mouser.com/ds/2/18/40_c091_abd_e-75918.pdf | https://www.digikey.com/short/p4nrpz | CP-1250-ND |  |  |  |  |  |  | 2.99
7 | 1 | J4 | Prog Jumper | Connector_Generic:Conn_01x02 | Connector_PinHeader_2.54mm:PinHeader_1x02_P2.54mm_Vertical | ~ | https://www.digikey.com/short/p4nrjv | 732-5315-ND |  |  |  |  |  |  | 0.13
8 | 13 | J5, J6, J7, J8, J9, J10, J11, J12, J13, J14, J15, J16, J17 | 4832 | Synth:MJ-3502 | Synth:Schurter_4832_Jack | https://www.digikey.com/product-detail/en/cui-inc/MJ-3502/CP-3502MJ-ND/281321 | https://www.digikey.com/short/p4nrqw | 486-3418-ND | CP-3502MJ-ND | None | MJ-3502 | https://www.cui.com/product/interconnect/connectors/audio-connectors/jacks/mj-3502 | 3.5 mm, Mono, Right Angle, Through Hole, Threaded Bushing, Audio Jack Connector | CUI Inc. | 1.50
9 | 2 | R4, R6 | 220 | Device:R | Synth:R_1206 | ~ | https://www.digikey.com/short/p4nrjp | 311-220FRCT-ND |  |  |  |  |  |  | 0.10
10 | 1 | R5 | 4.7k | Device:R | Synth:R_1206 | ~ | https://www.digikey.com/short/p4nr81 | A130181CT-ND |  |  |  |  |  |  | 0.10
11 | 7 | U3, U4, U5, U7, U8, U9, U10 | AD5293 | Potentiometer_Digital:AD5293 | Package_SO:TSSOP-14_4.4x5mm_P0.65mm | https://www.analog.com/media/en/technical-documentation/data-sheets/AD5293.pdf | https://www.digikey.com/short/pzd8zr | AD5293BRUZ-100-RL7CT-ND |  |  |  |  |  |  | 6.88
12 | 1 | U11 | 6N138 | Isolator:6N138 | Package_DIP:DIP-8_W7.62mm_LongPads | http://www.onsemi.com/pub/Collateral/HCPL2731-D.pdf | https://www.digikey.com/short/p4nrj5 | 160-1795-ND |  |  |  |  |  |  | 0.81
13 | 4 | U12, U13, U14, U15 | TL074 | Amplifier_Operational:TL074 | Package_SO:SOIC-14_3.9x8.7mm_P1.27mm | http://www.ti.com/lit/ds/symlink/tl071.pdf | https://www.digikey.com/short/p4nr82 | 296-1283-1-ND |  |  |  |  |  |  | 0.60

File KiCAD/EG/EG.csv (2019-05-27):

Source: | C:\Users\Jonathan Kayne\Documents\KiCAD\Modular Synth\EG\EG.sch
Date: | 05/26/19 18:08:24
Tool: | Eeschema (5.1.0)-1
Generator: | C:\Program Files\KiCad\bin\scripting\plugins/bom_csv_grouped_by_value.py
Component Count: | 43
Individual Components:
Item | Qty | Reference(s) | Value | LibPart | Footprint | Datasheet | Digikey Link | Digikey PN | Field4 | Field5 | Field6 | Field7 | Field8 | Field9 | Unit Price
 |  | C1 | 0.1uF | Device:C | Synth:C_1206 | ~ | https://www.digikey.com/short/p4nr3m | 720-1540-1-ND |  |  |  |  |  |  | 0.237
 |  | C2 | 0.1uF | Device:C | Synth:C_1206 | ~ | https://www.digikey.com/short/p4nr3m | 720-1540-1-ND |  |  |  |  |  |  | 0.237
 |  | C3 | 10nF | Device:C | Synth:C_1206 | ~ | https://www.digikey.com/short/p4nf4h | 311-1174-1-ND |  |  |  |  |  |  | 0.25
 |  | C4 | 10nF | Device:C | Synth:C_1206 | ~ | https://www.digikey.com/short/p4nf4h | 311-1174-1-ND |  |  |  |  |  |  | 0.25
 |  | C5 | 0.1uF | Device:C | Synth:C_1206 | ~ | https://www.digikey.com/short/p4nr3m | 720-1540-1-ND |  |  |  |  |  |  | 0.237
 |  | C6 | 10uF | Device:CP1 | Synth:CP_Tantalum_7343 | ~ | https://www.digikey.com/short/p4nf4z | 718-1046-1-ND |  |  |  |  |  |  | 0.70
 |  | CN1 | M3_Screw | Synth:M3_Screw | Synth:M3_Screw_Hole |  | N/A | N/A |  |  |  |  |  |  | 0.00
 |  | CN2 | M3_Screw | Synth:M3_Screw | Synth:M3_Screw_Hole |  | N/A | N/A |  |  |  |  |  |  | 0.00
 |  | CN3 | M3_Screw | Synth:M3_Screw | Synth:M3_Screw_Hole |  | N/A | N/A |  |  |  |  |  |  | 0.00
 |  | CN4 | M3_Screw | Synth:M3_Screw | Synth:M3_Screw_Hole |  | N/A | N/A |  |  |  |  |  |  | 0.00
 |  | D1 | 1N4148W | Diode:1N4148W | Synth:D_SOD-123 | https://www.vishay.com/docs/85748/1n4148w.pdf | https://www.digikey.com/short/p4nrm2 | 1N4148WTPMSCT-ND |  |  |  |  |  |  | 0.14
 |  | D2 | 1N4148W | Diode:1N4148W | Synth:D_SOD-123 | https://www.vishay.com/docs/85748/1n4148w.pdf | https://www.digikey.com/short/p4nrm2 | 1N4148WTPMSCT-ND |  |  |  |  |  |  | 0.14
 |  | D3 | 1N4148W | Diode:1N4148W | Synth:D_SOD-123 | https://www.vishay.com/docs/85748/1n4148w.pdf | https://www.digikey.com/short/p4nrm2 | 1N4148WTPMSCT-ND |  |  |  |  |  |  | 0.14
 |  | D4 | 1N4148W | Diode:1N4148W | Synth:D_SOD-123 | https://www.vishay.com/docs/85748/1n4148w.pdf | https://www.digikey.com/short/p4nrm2 | 1N4148WTPMSCT-ND |  |  |  |  |  |  | 0.14
 |  | D5 | 1N4148W | Diode:1N4148W | Synth:D_SOD-123 | https://www.vishay.com/docs/85748/1n4148w.pdf | https://www.digikey.com/short/p4nrm2 | 1N4148WTPMSCT-ND |  |  |  |  |  |  | 0.14
 |  | D6 | LED | Device:LED | Synth:LED_D3.0mm_Clear | ~ | N/A | N/A |  |  |  |  |  |  | 0.00
 |  | J1 | Power | Connector_Generic:Conn_02x05_Odd_Even | Synth:PinHeader_2x05_P2.54mm_Vertical_Zigzag | ~ | https://www.digikey.com/short/p4nr5h | 609-3243-ND |  |  |  |  |  |  | 0.27
 |  | J2 | 4832 | Synth:MJ-3502 | Synth:Schurter_4832_Jack | https://www.digikey.com/product-detail/en/cui-inc/MJ-3502/CP-3502MJ-ND/281321 | https://www.digikey.com/short/p4nr1r | 486-3418-ND | CP-3502MJ-ND | None | MJ-3502 | https://www.cui.com/product/interconnect/connectors/audio-connectors/jacks/mj-3502 | 3.5 mm, Mono, Right Angle, Through Hole, Threaded Bushing, Audio Jack Connector | CUI Inc. | 1.50
 |  | J3 | 4832 | Synth:MJ-3502 | Synth:Schurter_4832_Jack | https://www.digikey.com/product-detail/en/cui-inc/MJ-3502/CP-3502MJ-ND/281321 | https://www.digikey.com/short/p4nr1r | 486-3418-ND | CP-3502MJ-ND | None | MJ-3502 | https://www.cui.com/product/interconnect/connectors/audio-connectors/jacks/mj-3502 | 3.5 mm, Mono, Right Angle, Through Hole, Threaded Bushing, Audio Jack Connector | CUI Inc. | 1.50
 |  | Q1 | BC847 | Transistor_BJT:BC847 | TO_SOT_Packages_SMD:SOT-23_Handsoldering | http://www.infineon.com/dgdl/Infineon-BC847SERIES_BC848SERIES_BC849SERIES_BC850SERIES-DS-v01_01-en.pdf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 | https://www.digikey.com/short/p4nf4c | BC847CLT1GOSCT-ND |  |  |  |  |  |  | 0.14
 |  | Q2 | BC847 | Transistor_BJT:BC847 | TO_SOT_Packages_SMD:SOT-23_Handsoldering | http://www.infineon.com/dgdl/Infineon-BC847SERIES_BC848SERIES_BC849SERIES_BC850SERIES-DS-v01_01-en.pdf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 | https://www.digikey.com/short/p4nf4c | BC847CLT1GOSCT-ND |  |  |  |  |  |  | 0.14
 |  | Q3 | BC847 | Transistor_BJT:BC847 | TO_SOT_Packages_SMD:SOT-23_Handsoldering | http://www.infineon.com/dgdl/Infineon-BC847SERIES_BC848SERIES_BC849SERIES_BC850SERIES-DS-v01_01-en.pdf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 | https://www.digikey.com/short/p4nf4c | BC847CLT1GOSCT-ND |  |  |  |  |  |  | 0.14
 |  | Q4 | 2N7002 | Transistor_FET:2N7002 | TO_SOT_Packages_SMD:SOT-23_Handsoldering | https://www.fairchildsemi.com/datasheets/2N/2N7002.pdf | https://www.digikey.com/short/p4nf48 | 2N7002NCT-ND |  |  |  |  |  |  | 0.39
 |  | R1 | 1.2M | Device:R | Synth:R_1206 | ~ | https://www.digikey.com/short/p4nf4f | 311-1.20MFRCT-ND |  |  |  |  |  |  | 0.10
 |  | R2 | 1M | Device:R | Synth:R_1206 | ~ | https://www.digikey.com/short/p4nrn7 | RMCF1206JT1M00CT-ND |  |  |  |  |  |  | 0.10
 |  | R3 | 22k | Device:R | Synth:R_1206 | ~ | https://www.digikey.com/short/p4nr22 | A130554CT-ND |  |  |  |  |  |  | 0.33
 |  | R4 | 10 | Device:R | Synth:R_1206 | ~ | https://www.digikey.com/short/p4nrn9 | P10ALCT-ND |  |  |  |  |  |  | 0.17
 |  | R5 | 22k | Device:R | Synth:R_1206 | ~ | https://www.digikey.com/short/p4nr22 | A130554CT-ND |  |  |  |  |  |  | 0.33
 |  | R6 | 22k | Device:R | Synth:R_1206 | ~ | https://www.digikey.com/short/p4nr22 | A130554CT-ND |  |  |  |  |  |  | 0.33
 |  | R7 | 22k | Device:R | Synth:R_1206 | ~ | https://www.digikey.com/short/p4nr22 | A130554CT-ND |  |  |  |  |  |  | 0.33
 |  | R8 | 1M | Device:R | Synth:R_1206 | ~ | https://www.digikey.com/short/p4nrn7 | RMCF1206JT1M00CT-ND |  |  |  |  |  |  | 0.10
 |  | R9 | 4.7k | Device:R | Synth:R_1206 | ~ | https://www.digikey.com/short/p4nr81 | A130181CT-ND |  |  |  |  |  |  | 0.10
 |  | R10 | 100 | Device:R | Synth:R_1206 | ~ | https://www.digikey.com/short/p4nf40 | RNCP1206FTD100RCT-ND |  |  |  |  |  |  | 0.10
 |  | R11 | 100 | Device:R | Synth:R_1206 | ~ | https://www.digikey.com/short/p4nf40 | RNCP1206FTD100RCT-ND |  |  |  |  |  |  | 0.10
 |  | R12 | 100 | Device:R | Synth:R_1206 | ~ | https://www.digikey.com/short/p4nf40 | RNCP1206FTD100RCT-ND |  |  |  |  |  |  | 0.10
 |  | R13 | 1k | Device:R | Synth:R_1206 | ~ | https://www.digikey.com/short/p4nrdz | 311-1.0KERCT-ND |  |  |  |  |  |  | 0.10
 |  | R14 | 1k | Device:R | Synth:R_1206 | ~ | https://www.digikey.com/short/p4nrdz | 311-1.0KERCT-ND |  |  |  |  |  |  | 0.10
 |  | RV1 | 25k | Device:R_POT | Synth:Potentiometer_Bourns_PTV09A-1_Single_Vertical | ~ | https://www.digikey.com/short/p4nfq1 | PTV09A-4020F-B203-ND |  |  |  |  |  |  | 0.83
 |  | RV2 | 1M Log | Device:R_POT | Synth:Potentiometer_Bourns_PTV09A-1_Single_Vertical | ~ | https://www.digikey.com/short/p4nfhw | PTV09A-4020F-A504-ND |  |  |  |  |  |  | 0.83
 |  | RV3 | 1M Log | Device:R_POT | Synth:Potentiometer_Bourns_PTV09A-1_Single_Vertical | ~ | https://www.digikey.com/short/p4nfhw | PTV09A-4020F-A504-ND |  |  |  |  |  |  | 0.83
 |  | RV4 | 1M Log | Device:R_POT | Synth:Potentiometer_Bourns_PTV09A-1_Single_Vertical | ~ | https://www.digikey.com/short/p4nfhw | PTV09A-4020F-A504-ND |  |  |  |  |  |  | 0.83
 |  | U1 | TL074 | Amplifier_Operational:TL074 | Package_SO:SOIC-14_3.9x8.7mm_P1.27mm | http://www.ti.com/lit/ds/symlink/tl071.pdf | https://www.digikey.com/short/p4nrh2 | 296-1283-1-ND |  |  |  |  |  |  | 0.60
 |  | U2 | NE555 | Timer:NE555 | Package_SO:SOIC-8_3.9x4.9mm_P1.27mm | http://www.ti.com/lit/ds/symlink/ne555.pdf | https://www.digikey.com/short/p4nfzd | 296-6501-1-ND |  |  |  |  |  |  | 0.48
Collated Components:
Item | Qty | Reference(s) | Value | LibPart | Footprint | Datasheet | Digikey Link | Digikey PN | Field4 | Field5 | Field6 | Field7 | Field8 | Field9 | Unit Price
1 | 3 | C1, C2, C5 | 0.1uF | Device:C | Synth:C_1206 | ~ | https://www.digikey.com/short/p4nr3m | 720-1540-1-ND |  |  |  |  |  |  | 0.237
2 | 2 | C3, C4 | 10nF | Device:C | Synth:C_1206 | ~ | https://www.digikey.com/short/p4nf4h | 311-1174-1-ND |  |  |  |  |  |  | 0.25
3 | 1 | C6 | 10uF | Device:CP1 | Synth:CP_Tantalum_7343 | ~ | https://www.digikey.com/short/p4nf4z | 718-1046-1-ND |  |  |  |  |  |  | 0.70
4 | 4 | CN1, CN2, CN3, CN4 | M3_Screw | Synth:M3_Screw | Synth:M3_Screw_Hole |  | N/A | N/A |  |  |  |  |  |  | 0.00
5 | 5 | D1, D2, D3, D4, D5 | 1N4148W | Diode:1N4148W | Synth:D_SOD-123 | https://www.vishay.com/docs/85748/1n4148w.pdf | https://www.digikey.com/short/p4nrm2 | 1N4148WTPMSCT-ND |  |  |  |  |  |  | 0.14
6 | 1 | D6 | LED | Device:LED | Synth:LED_D3.0mm_Clear | ~ | N/A | N/A |  |  |  |  |  |  | 0.00
7 | 1 | J1 | Power | Connector_Generic:Conn_02x05_Odd_Even | Synth:PinHeader_2x05_P2.54mm_Vertical_Zigzag | ~ | https://www.digikey.com/short/p4nr5h | 609-3243-ND |  |  |  |  |  |  | 0.27
8 | 2 | J2, J3 | 4832 | Synth:MJ-3502 | Synth:Schurter_4832_Jack | https://www.digikey.com/product-detail/en/cui-inc/MJ-3502/CP-3502MJ-ND/281321 | https://www.digikey.com/short/p4nr1r | 486-3418-ND | CP-3502MJ-ND | None | MJ-3502 | https://www.cui.com/product/interconnect/connectors/audio-connectors/jacks/mj-3502 | 3.5 mm, Mono, Right Angle, Through Hole, Threaded Bushing, Audio Jack Connector | CUI Inc. | 1.50
9 | 3 | Q1, Q2, Q3 | BC847 | Transistor_BJT:BC847 | TO_SOT_Packages_SMD:SOT-23_Handsoldering | http://www.infineon.com/dgdl/Infineon-BC847SERIES_BC848SERIES_BC849SERIES_BC850SERIES-DS-v01_01-en.pdf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 | https://www.digikey.com/short/p4nf4c | BC847CLT1GOSCT-ND |  |  |  |  |  |  | 0.14
10 | 1 | Q4 | 2N7002 | Transistor_FET:2N7002 | TO_SOT_Packages_SMD:SOT-23_Handsoldering | https://www.fairchildsemi.com/datasheets/2N/2N7002.pdf | https://www.digikey.com/short/p4nf48 | 2N7002NCT-ND |  |  |  |  |  |  | 0.39
11 | 1 | R1 | 1.2M | Device:R | Synth:R_1206 | ~ | https://www.digikey.com/short/p4nf4f | 311-1.20MFRCT-ND |  |  |  |  |  |  | 0.10
12 | 2 | R2, R8 | 1M | Device:R | Synth:R_1206 | ~ | https://www.digikey.com/short/p4nrn7 | RMCF1206JT1M00CT-ND |  |  |  |  |  |  | 0.10
13 | 4 | R3, R5, R6, R7 | 22k | Device:R | Synth:R_1206 | ~ | https://www.digikey.com/short/p4nr22 | A130554CT-ND |  |  |  |  |  |  | 0.33
14 | 1 | R4 | 10 | Device:R | Synth:R_1206 | ~ | https://www.digikey.com/short/p4nrn9 | P10ALCT-ND |  |  |  |  |  |  | 0.17
15 | 1 | R9 | 4.7k | Device:R | Synth:R_1206 | ~ | https://www.digikey.com/short/p4nr81 | A130181CT-ND |  |  |  |  |  |  | 0.10
16 | 3 | R10, R11, R12 | 100 | Device:R | Synth:R_1206 | ~ | https://www.digikey.com/short/p4nf40 | RNCP1206FTD100RCT-ND |  |  |  |  |  |  | 0.10
17 | 2 | R13, R14 | 1k | Device:R | Synth:R_1206 | ~ | https://www.digikey.com/short/p4nrdz | 311-1.0KERCT-ND |  |  |  |  |  |  | 0.10
18 | 1 | RV1 | 25k | Device:R_POT | Synth:Potentiometer_Bourns_PTV09A-1_Single_Vertical | ~ | https://www.digikey.com/short/p4nfq1 | PTV09A-4020F-B203-ND |  |  |  |  |  |  | 0.83
19 | 3 | RV2, RV3, RV4 | 1M Log | Device:R_POT | Synth:Potentiometer_Bourns_PTV09A-1_Single_Vertical | ~ | https://www.digikey.com/short/p4nfhw | PTV09A-4020F-A504-ND |  |  |  |  |  |  | 0.83
20 | 1 | U1 | TL074 | Amplifier_Operational:TL074 | Package_SO:SOIC-14_3.9x8.7mm_P1.27mm | http://www.ti.com/lit/ds/symlink/tl071.pdf | https://www.digikey.com/short/p4nrh2 | 296-1283-1-ND |  |  |  |  |  |  | 0.60
21 | 1 | U2 | NE555 | Timer:NE555 | Package_SO:SOIC-8_3.9x4.9mm_P1.27mm | http://www.ti.com/lit/ds/symlink/ne555.pdf | https://www.digikey.com/short/p4nfzd | 296-6501-1-ND |  |  |  |  |  |  | 0.48

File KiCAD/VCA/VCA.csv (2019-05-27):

Source: | C:\Users\Jonathan Kayne\Documents\KiCAD\Modular Synth\VCA\VCA.sch
Date: | 5/27/2019 4:07:56 PM
Tool: | Eeschema (5.1.0)-1
Generator: | C:\Program Files\KiCad\bin\scripting\plugins/bom_csv_grouped_by_value.py
Component Count: | 60
Individual Components:
Item | Qty | Reference(s) | Value | LibPart | Footprint | Datasheet | Digikey Link | Digikey PN | Unit Price
 |  | C1 | 0.22uF | Device:C | Synth:C_1206 | ~ | https://www.digikey.com/short/p4d2tf | 445-2283-1-ND | 0.28
 |  | C2 | 0.22uF | Device:C | Synth:C_1206 | ~ | https://www.digikey.com/short/p4d2tf | 445-2283-1-ND | 0.28
 |  | C3 | 10pF | Device:C | Synth:C_1206 | ~ | https://www.digikey.com/short/p4nrfm | 311-1150-1-ND | 0.23
 |  | C4 | 10pF | Device:C | Synth:C_1206 | ~ | https://www.digikey.com/short/p4nrfm | 311-1150-1-ND | 0.23
 |  | C5 | 10pF | Device:C | Synth:C_1206 | ~ | https://www.digikey.com/short/p4nrfm | 311-1150-1-ND | 0.23
 |  | C6 | 0.1uF | Device:C | Synth:C_1206 | ~ | https://www.digikey.com/short/p4nr3m | 720-1540-1-ND | 0.237
 |  | C7 | 0.1uF | Device:C | Synth:C_1206 | ~ | https://www.digikey.com/short/p4nr3m | 720-1540-1-ND | 0.237
 |  | C8 | 0.1uF | Device:C | Synth:C_1206 | ~ | https://www.digikey.com/short/p4nr3m | 720-1540-1-ND | 0.237
 |  | C9 | 0.1uF | Device:C | Synth:C_1206 | ~ | https://www.digikey.com/short/p4nr3m | 720-1540-1-ND | 0.237
 |  | C10 | 0.1uF | Device:C | Synth:C_1206 | ~ | https://www.digikey.com/short/p4nr3m | 720-1540-1-ND | 0.237
 |  | C11 | 0.1uF | Device:C | Synth:C_1206 | ~ | https://www.digikey.com/short/p4nr3m | 720-1540-1-ND | 0.237
 |  | CN1 | M3_Screw | Synth:M3_Screw | Synth:M3_Screw_Hole |  | N/A | N/A | 0.00
 |  | CN2 | M3_Screw | Synth:M3_Screw | Synth:M3_Screw_Hole |  | N/A | N/A | 0.00
 |  | CN3 | M3_Screw | Synth:M3_Screw | Synth:M3_Screw_Hole |  | N/A | N/A | 0.00
 |  | CN4 | M3_Screw | Synth:M3_Screw | Synth:M3_Screw_Hole |  | N/A | N/A | 0.00
 |  | J1 | Schurter_4832_Jack | Synth:Schurter_4832_Jack | Synth:Schurter_4832_Jack | https://us.schurter.com/bundles/snceschurter/epim/_ProdPool_/newDS/en/typ_4832.2211.pdf | https://www.digikey.com/short/p4drjq | 486-3418-ND | 1.50
 |  | J2 | Schurter_4832_Jack | Synth:Schurter_4832_Jack | Synth:Schurter_4832_Jack | https://us.schurter.com/bundles/snceschurter/epim/_ProdPool_/newDS/en/typ_4832.2211.pdf | https://www.digikey.com/short/p4drjq | 486-3418-ND | 1.50
 |  | J3 | Schurter_4832_Jack | Synth:Schurter_4832_Jack | Synth:Schurter_4832_Jack | https://us.schurter.com/bundles/snceschurter/epim/_ProdPool_/newDS/en/typ_4832.2211.pdf | https://www.digikey.com/short/p4drjq | 486-3418-ND | 1.50
 |  | J4 | Schurter_4832_Jack | Synth:Schurter_4832_Jack | Synth:Schurter_4832_Jack | https://us.schurter.com/bundles/snceschurter/epim/_ProdPool_/newDS/en/typ_4832.2211.pdf | https://www.digikey.com/short/p4drjq | 486-3418-ND | 1.50
 |  | J5 | Schurter_4832_Jack | Synth:Schurter_4832_Jack | Synth:Schurter_4832_Jack | https://us.schurter.com/bundles/snceschurter/epim/_ProdPool_/newDS/en/typ_4832.2211.pdf | https://www.digikey.com/short/p4drjq | 486-3418-ND | 1.50
 |  | J6 | Power | Connector_Generic:Conn_02x05_Odd_Even | Synth:PinHeader_2x05_P2.54mm_Vertical_Zigzag | ~ | https://www.digikey.com/short/p4nr5h | 609-3243-ND | 0.27
 |  | J7 | Schurter_4832_Jack | Synth:Schurter_4832_Jack | Synth:Schurter_4832_Jack | https://us.schurter.com/bundles/snceschurter/epim/_ProdPool_/newDS/en/typ_4832.2211.pdf | https://www.digikey.com/short/p4drjq | 486-3418-ND | 1.50
 |  | Q1 | MMBT3906 | Transistor_BJT:MMBT3906 | TO_SOT_Packages_SMD:SOT-23_Handsoldering | https://www.fairchildsemi.com/datasheets/2N/2N3906.pdf | https://www.digikey.com/short/p4d2t1 | MMBT3906LT1GOSCT-ND | 0.15
 |  | Q2 | MMBT3906 | Transistor_BJT:MMBT3906 | TO_SOT_Packages_SMD:SOT-23_Handsoldering | https://www.fairchildsemi.com/datasheets/2N/2N3906.pdf | https://www.digikey.com/short/p4d2t1 | MMBT3906LT1GOSCT-ND | 0.15
 |  | R1 | 270k | Device:R | Synth:R_1206 | ~ | https://www.digikey.com/short/p4d23b | A129839CT-ND | 0.10
 |  | R2 | 100k | Device:R | Synth:R_1206 | ~ | https://www.digikey.com/short/p4nr28 | A129834CT-ND | 0.07
 |  | R3 | 330k | Device:R | Synth:R_1206 | ~ | https://www.digikey.com/short/p4d23d | P330KBCCT-ND | 0.66
 |  | R4 | 100k | Device:R | Synth:R_1206 | ~ | https://www.digikey.com/short/p4nr28 | A129834CT-ND | 0.07
 |  | R5 | 100k | Device:R | Synth:R_1206 | ~ | https://www.digikey.com/short/p4nr28 | A129834CT-ND | 0.07
 |  | R6 | 100k | Device:R | Synth:R_1206 | ~ | https://www.digikey.com/short/p4nr28 | A129834CT-ND | 0.07
 |  | R7 | 100k | Device:R | Synth:R_1206 | ~ | https://www.digikey.com/short/p4nr28 | A129834CT-ND | 0.07
 |  | R8 | 4.7k | Device:R | Synth:R_1206 | ~ | https://www.digikey.com/short/p4nr81 | A130181CT-ND | 0.10
 |  | R9 | 270k | Device:R | Synth:R_1206 | ~ | https://www.digikey.com/short/p4d23b | A129839CT-ND | 0.10
 |  | R10 | 100k | Device:R | Synth:R_1206 | ~ | https://www.digikey.com/short/p4nr28 | A129834CT-ND | 0.07
 |  | R11 | 100k | Device:R | Synth:R_1206 | ~ | https://www.digikey.com/short/p4nr28 | A129834CT-ND | 0.07
 |  | R12 | 100k | Device:R | Synth:R_1206 | ~ | https://www.digikey.com/short/p4nr28 | A129834CT-ND | 0.07
 |  | R13 | 100k | Device:R | Synth:R_1206 | ~ | https://www.digikey.com/short/p4nr28 | A129834CT-ND | 0.07
 |  | R14 | 10k | Device:R | Synth:R_1206 | ~ | https://www.digikey.com/short/p4nrn3 | RMCF1206JT10K0CT-ND | 0.1
 |  | R15 | 100k | Device:R | Synth:R_1206 | ~ | https://www.digikey.com/short/p4nr28 | A129834CT-ND | 0.07
 |  | R16 | 100k | Device:R | Synth:R_1206 | ~ | https://www.digikey.com/short/p4nr28 | A129834CT-ND | 0.07
 |  | R17 | 220 | Device:R | Synth:R_1206 | ~ | https://www.digikey.com/short/p4nrjp | 311-220FRCT-ND | 0.1
 |  | R18 | 220 | Device:R | Synth:R_1206 | ~ | https://www.digikey.com/short/p4nrjp | 311-220FRCT-ND | 0.1
 |  | R19 | 10k | Device:R | Synth:R_1206 | ~ | https://www.digikey.com/short/p4nrn3 | RMCF1206JT10K0CT-ND | 0.1
 |  | R20 | 220 | Device:R | Synth:R_1206 | ~ | https://www.digikey.com/short/p4nrjp | 311-220FRCT-ND | 0.1
 |  | R21 | 220 | Device:R | Synth:R_1206 | ~ | https://www.digikey.com/short/p4nrjp | 311-220FRCT-ND | 0.1
 |  | R22 | 22k | Device:R | Synth:R_1206 | ~ | https://www.digikey.com/short/p4nr22 | A130554CT-ND | 0.33
 |  | R23 | 100k | Device:R | Synth:R_1206 | ~ | https://www.digikey.com/short/p4nr28 | A129834CT-ND | 0.07
 |  | R24 | 1k | Device:R | Synth:R_1206 | ~ | https://www.digikey.com/short/p4nrdz | 311-1.0KERCT-ND | 0.10
 |  | RV1 | 100k | Device:R_POT | Synth:Potentiometer_Bourns_PTV09A-1_Single_Vertical | ~ | https://www.digikey.com/short/p4d2q4 | PTV09A-4020F-B104-ND | 0.83
 |  | RV2 | 100k | Device:R_POT | Synth:Potentiometer_Bourns_PTV09A-1_Single_Vertical | ~ | https://www.digikey.com/short/p4d2q4 | PTV09A-4020F-B104-ND | 0.83
 |  | RV3 | 100k | Device:R_POT | Synth:Potentiometer_Bourns_PTV09A-1_Single_Vertical | ~ | https://www.digikey.com/short/p4d2q4 | PTV09A-4020F-B104-ND | 0.83
 |  | RV4 | 100k | Device:R_POT | Synth:Potentiometer_Bourns_PTV09A-1_Single_Vertical | ~ | https://www.digikey.com/short/p4d2q4 | PTV09A-4020F-B104-ND | 0.83
 |  | RV5 | 100k | Device:R_POT | Synth:Potentiometer_Bourns_PTV09A-1_Single_Vertical | ~ | https://www.digikey.com/short/p4d2q4 | PTV09A-4020F-B104-ND | 0.83
 |  | RV6 | 100k | Device:R_POT | Synth:Potentiometer_Bourns_PTV09A-1_Single_Vertical | ~ | https://www.digikey.com/short/p4d2q4 | PTV09A-4020F-B104-ND | 0.83
 |  | RV7 | 100k | Device:R_POT | Synth:Potentiometer_Bourns_PTV09A-1_Single_Vertical | ~ | https://www.digikey.com/short/p4d2q4 | PTV09A-4020F-B104-ND | 0.83
 |  | RV8 | 100k | Device:R_POT | Synth:Trimpot_Bourns_3306F | ~ | https://www.digikey.com/short/p4dnq9 | 3306F-104-ND | 0.43
 |  | RV9 | 100k | Device:R_POT | Synth:Trimpot_Bourns_3306F | ~ | https://www.digikey.com/short/p4dnq9 | 3306F-104-ND | 0.43
 |  | U1 | TL074 | Amplifier_Operational:TL074 | Package_SO:SOIC-14_3.9x8.7mm_P1.27mm | http://www.ti.com/lit/ds/symlink/tl071.pdf | https://www.digikey.com/short/p4nrh2 | 296-1283-1-ND | 0.60
 |  | U2 | TL072 | Amplifier_Operational:TL072 | Package_SO:SOIC-8_3.9x4.9mm_P1.27mm | http://www.ti.com/lit/ds/symlink/tl071.pdf | https://www.digikey.com/short/p4nf7q | 296-1282-1-ND | 0.62
 |  | U3 | LM13700 | Amplifier_Operational:LM13700 | Package_SO:SOIC-16_3.9x9.9mm_P1.27mm | http://www.ti.com/lit/ds/symlink/lm13700.pdf | https://www.digikey.com/short/p4dfdn | LM13700MX/NOPBCT-ND | 1.20
Collated Components:
Item | Qty | Reference(s) | Value | LibPart | Footprint | Datasheet | Digikey Link | Digikey PN | Unit Price
1 | 2 | C1, C2 | 0.22uF | Device:C | Synth:C_1206 | ~ | https://www.digikey.com/short/p4d2tf | 445-2283-1-ND | 0.28
2 | 3 | C3, C4, C5 | 10pF | Device:C | Synth:C_1206 | ~ | https://www.digikey.com/short/p4nrfm | 311-1150-1-ND | 0.23
3 | 6 | C6, C7, C8, C9, C10, C11 | 0.1uF | Device:C | Synth:C_1206 | ~ | https://www.digikey.com/short/p4nr3m | 720-1540-1-ND | 0.237
4 | 4 | CN1, CN2, CN3, CN4 | M3_Screw | Synth:M3_Screw | Synth:M3_Screw_Hole |  | N/A | N/A | 0.00
5 | 6 | J1, J2, J3, J4, J5, J7 | Schurter_4832_Jack | Synth:Schurter_4832_Jack | Synth:Schurter_4832_Jack | https://us.schurter.com/bundles/snceschurter/epim/_ProdPool_/newDS/en/typ_4832.2211.pdf | https://www.digikey.com/short/p4drjq | 486-3418-ND | 1.50
6 | 1 | J6 | Power | Connector_Generic:Conn_02x05_Odd_Even | Synth:PinHeader_2x05_P2.54mm_Vertical_Zigzag | ~ | https://www.digikey.com/short/p4nr5h | 609-3243-ND | 0.27
7 | 2 | Q1, Q2 | MMBT3906 | Transistor_BJT:MMBT3906 | TO_SOT_Packages_SMD:SOT-23_Handsoldering | https://www.fairchildsemi.com/datasheets/2N/2N3906.pdf | https://www.digikey.com/short/p4d2t1 | MMBT3906LT1GOSCT-ND | 0.15
8 | 2 | R1, R9 | 270k | Device:R | Synth:R_1206 | ~ | https://www.digikey.com/short/p4d23b | A129839CT-ND | 0.10
9 | 12 | R2, R4, R5, R6, R7, R10, R11, R12, R13, R15, R16, R23 | 100k | Device:R | Synth:R_1206 | ~ | https://www.digikey.com/short/p4nr28 | A129834CT-ND | 0.07
10 | 1 | R3 | 330k | Device:R | Synth:R_1206 | ~ | https://www.digikey.com/short/p4d23d | P330KBCCT-ND | 0.66
11 | 1 | R8 | 4.7k | Device:R | Synth:R_1206 | ~ | https://www.digikey.com/short/p4nr81 | A130181CT-ND | 0.10
12 | 2 | R14, R19 | 10k | Device:R | Synth:R_1206 | ~ | https://www.digikey.com/short/p4nrn3 | RMCF1206JT10K0CT-ND | 0.1
13 | 4 | R17, R18, R20, R21 | 220 | Device:R | Synth:R_1206 | ~ | https://www.digikey.com/short/p4nrjp | 311-220FRCT-ND | 0.1
14 | 1 | R22 | 22k | Device:R | Synth:R_1206 | ~ | https://www.digikey.com/short/p4nr22 | A130554CT-ND | 0.33
15 | 1 | R24 | 1k | Device:R | Synth:R_1206 | ~ | https://www.digikey.com/short/p4nrdz | 311-1.0KERCT-ND | 0.10
16 | 7 | RV1, RV2, RV3, RV4, RV5, RV6, RV7 | 100k | Device:R_POT | Synth:Potentiometer_Bourns_PTV09A-1_Single_Vertical | ~ | https://www.digikey.com/short/p4d2q4 | PTV09A-4020F-B104-ND | 0.83
17 | 2 | RV8, RV9 | 100k | Device:R_POT | Synth:Trimpot_Bourns_3306F | ~ | https://www.digikey.com/short/p4dnq9 | 3306F-104-ND | 0.43
18 | 1 | U1 | TL074 | Amplifier_Operational:TL074 | Package_SO:SOIC-14_3.9x8.7mm_P1.27mm | http://www.ti.com/lit/ds/symlink/tl071.pdf | https://www.digikey.com/short/p4nrh2 | 296-1283-1-ND | 0.60
19 | 1 | U2 | TL072 | Amplifier_Operational:TL072 | Package_SO:SOIC-8_3.9x4.9mm_P1.27mm | http://www.ti.com/lit/ds/symlink/tl071.pdf | https://www.digikey.com/short/p4nf7q | 296-1282-1-ND | 0.62
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

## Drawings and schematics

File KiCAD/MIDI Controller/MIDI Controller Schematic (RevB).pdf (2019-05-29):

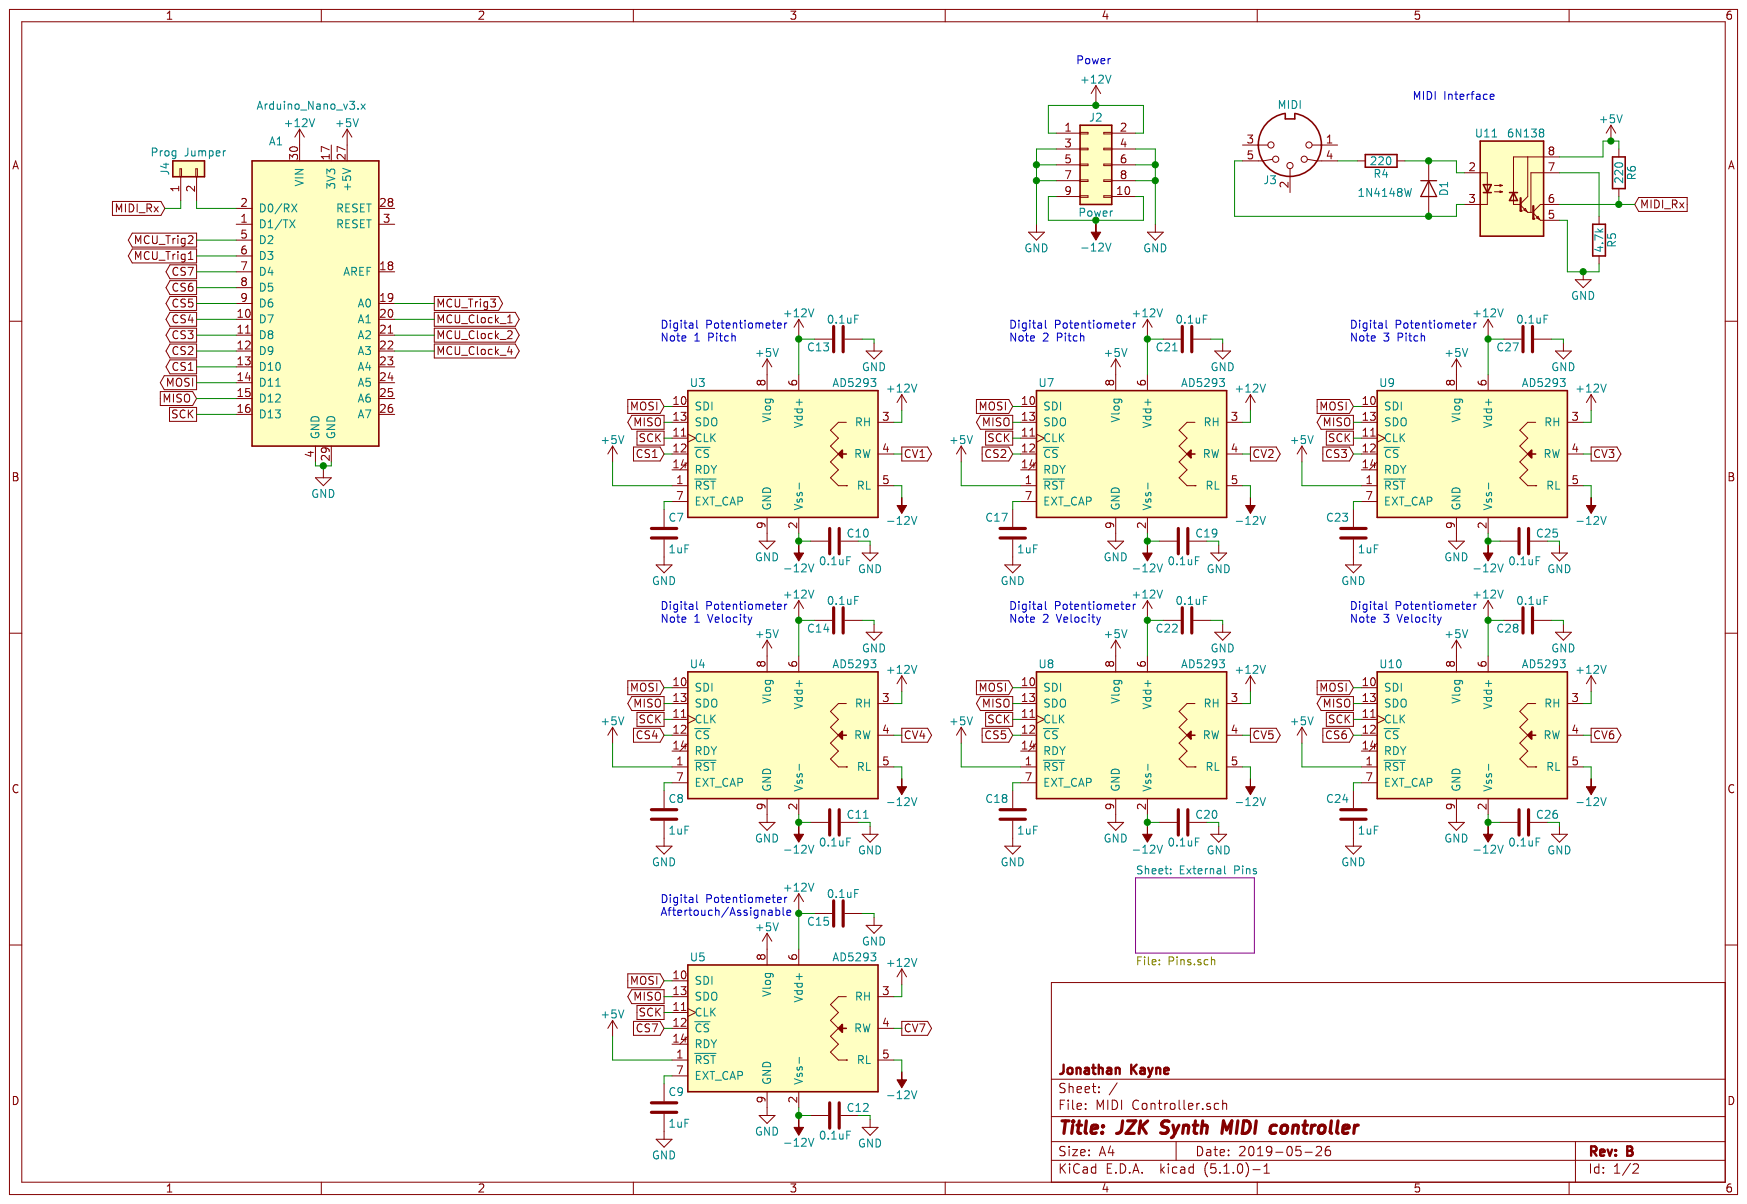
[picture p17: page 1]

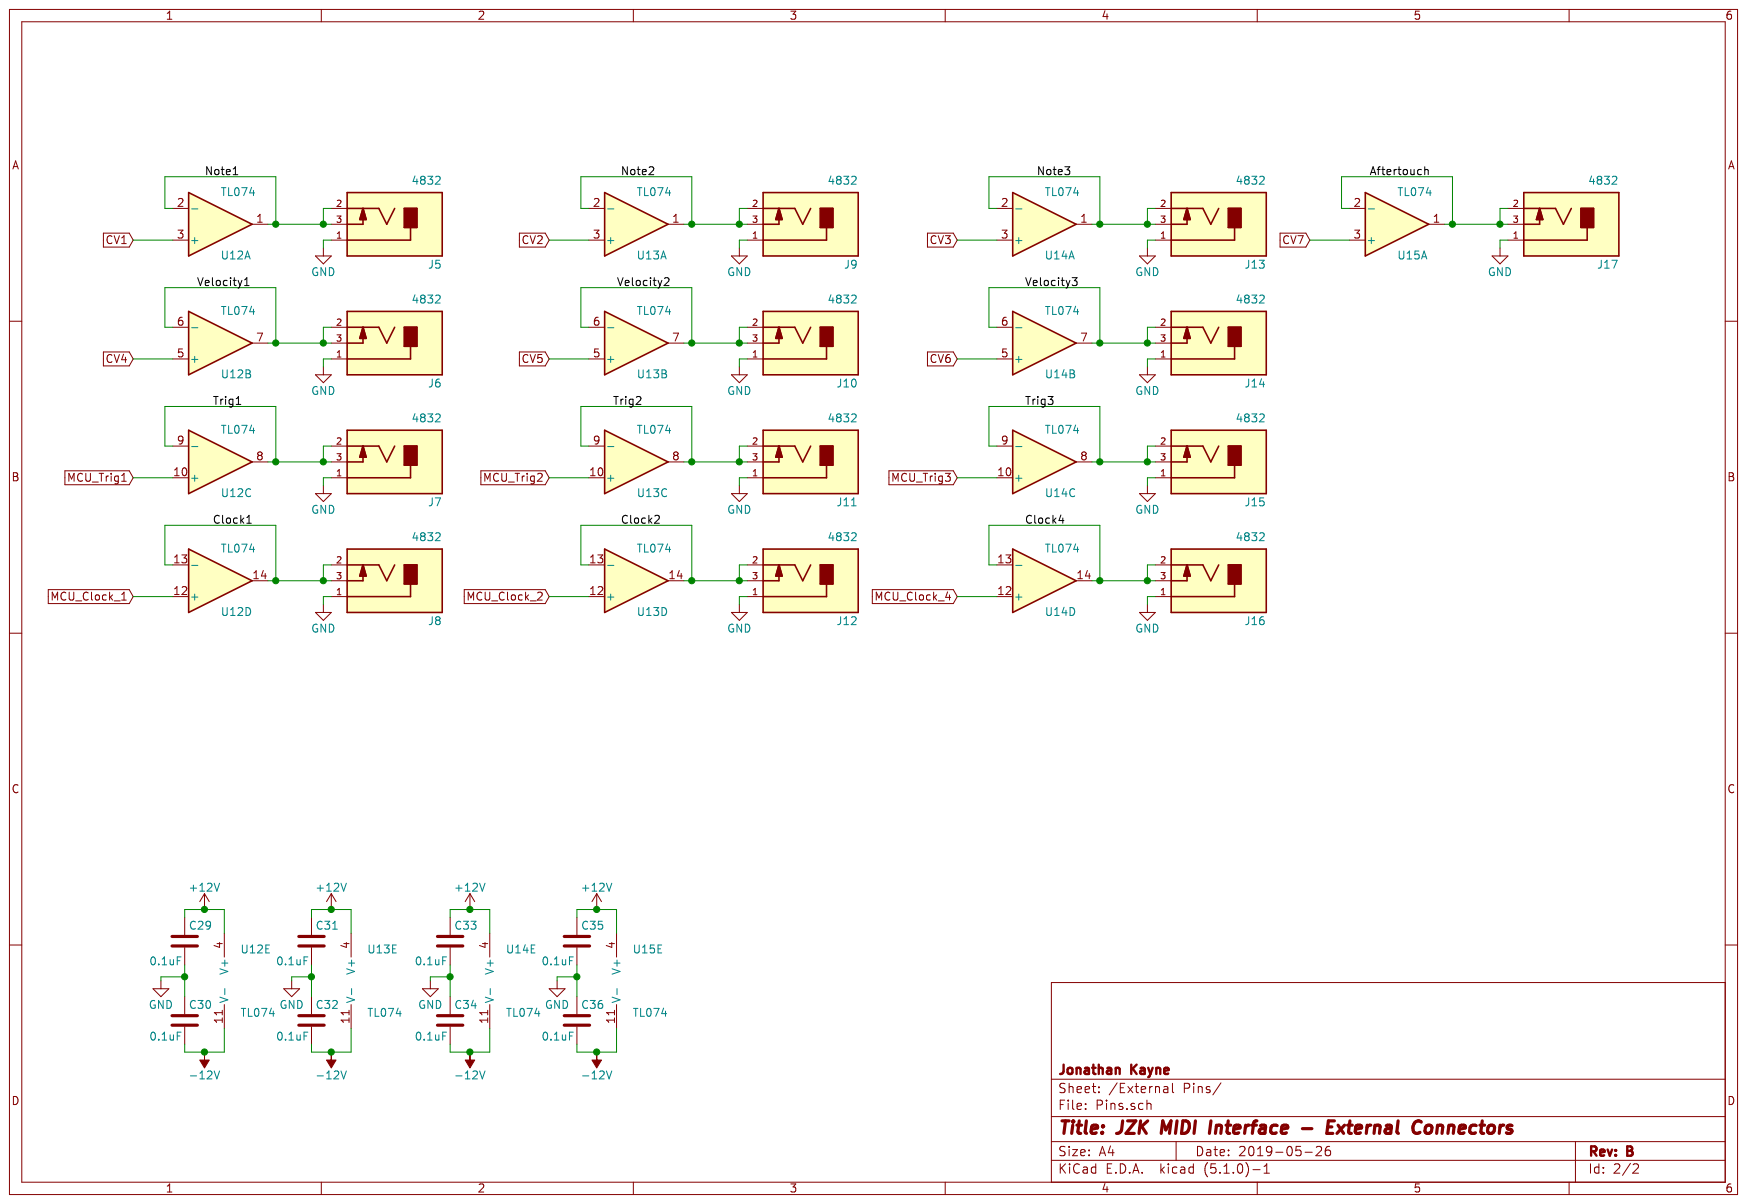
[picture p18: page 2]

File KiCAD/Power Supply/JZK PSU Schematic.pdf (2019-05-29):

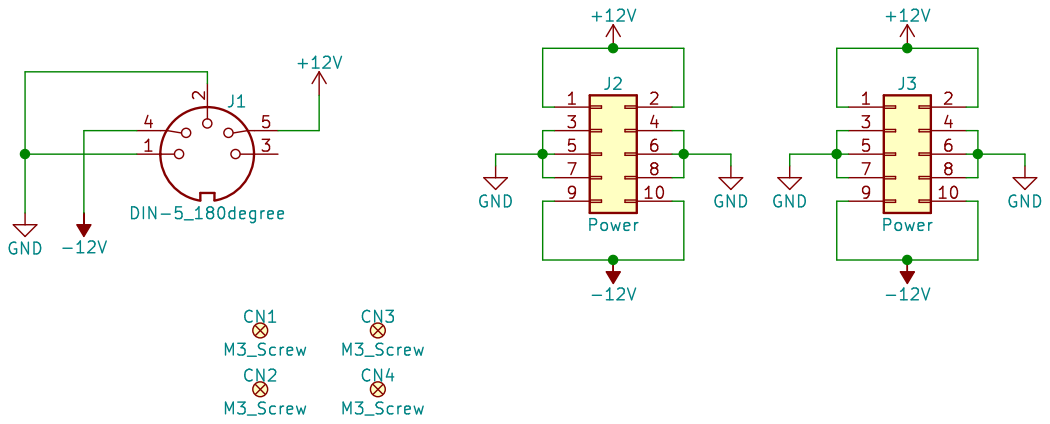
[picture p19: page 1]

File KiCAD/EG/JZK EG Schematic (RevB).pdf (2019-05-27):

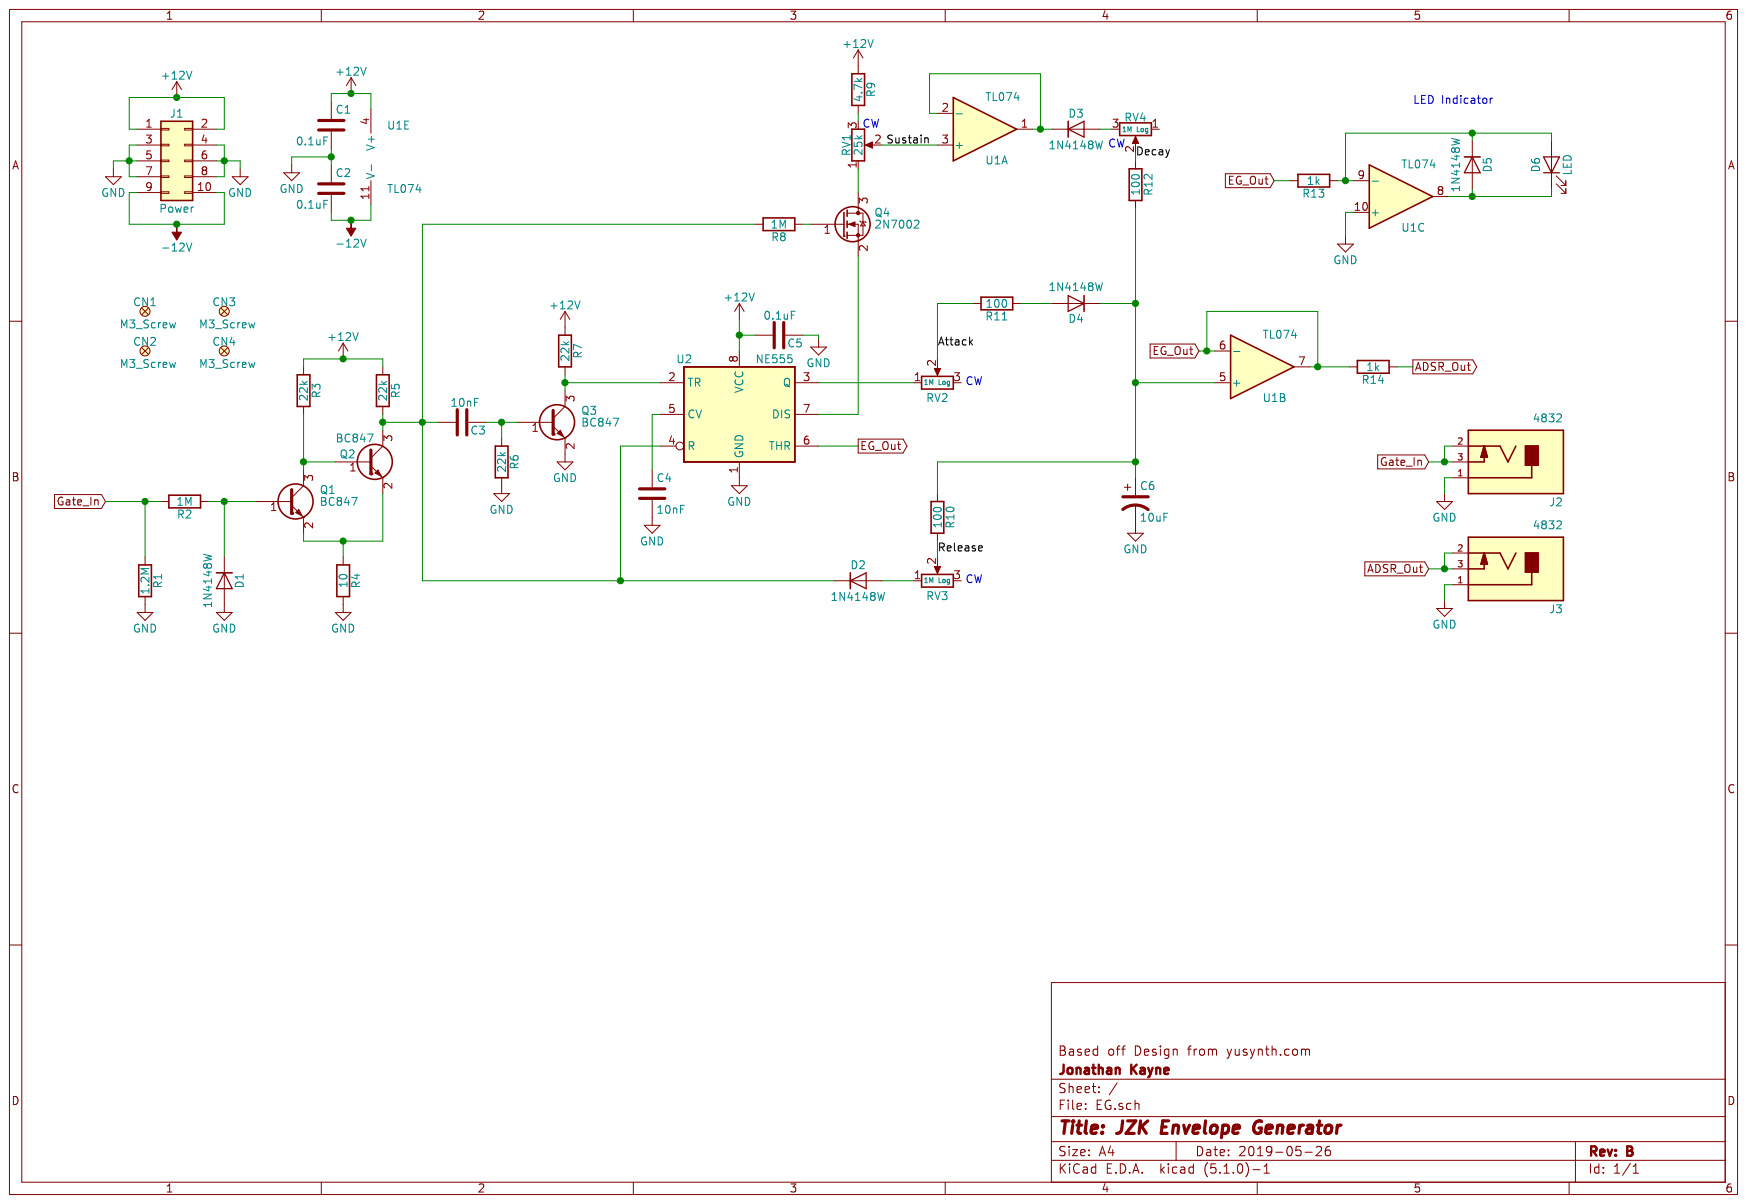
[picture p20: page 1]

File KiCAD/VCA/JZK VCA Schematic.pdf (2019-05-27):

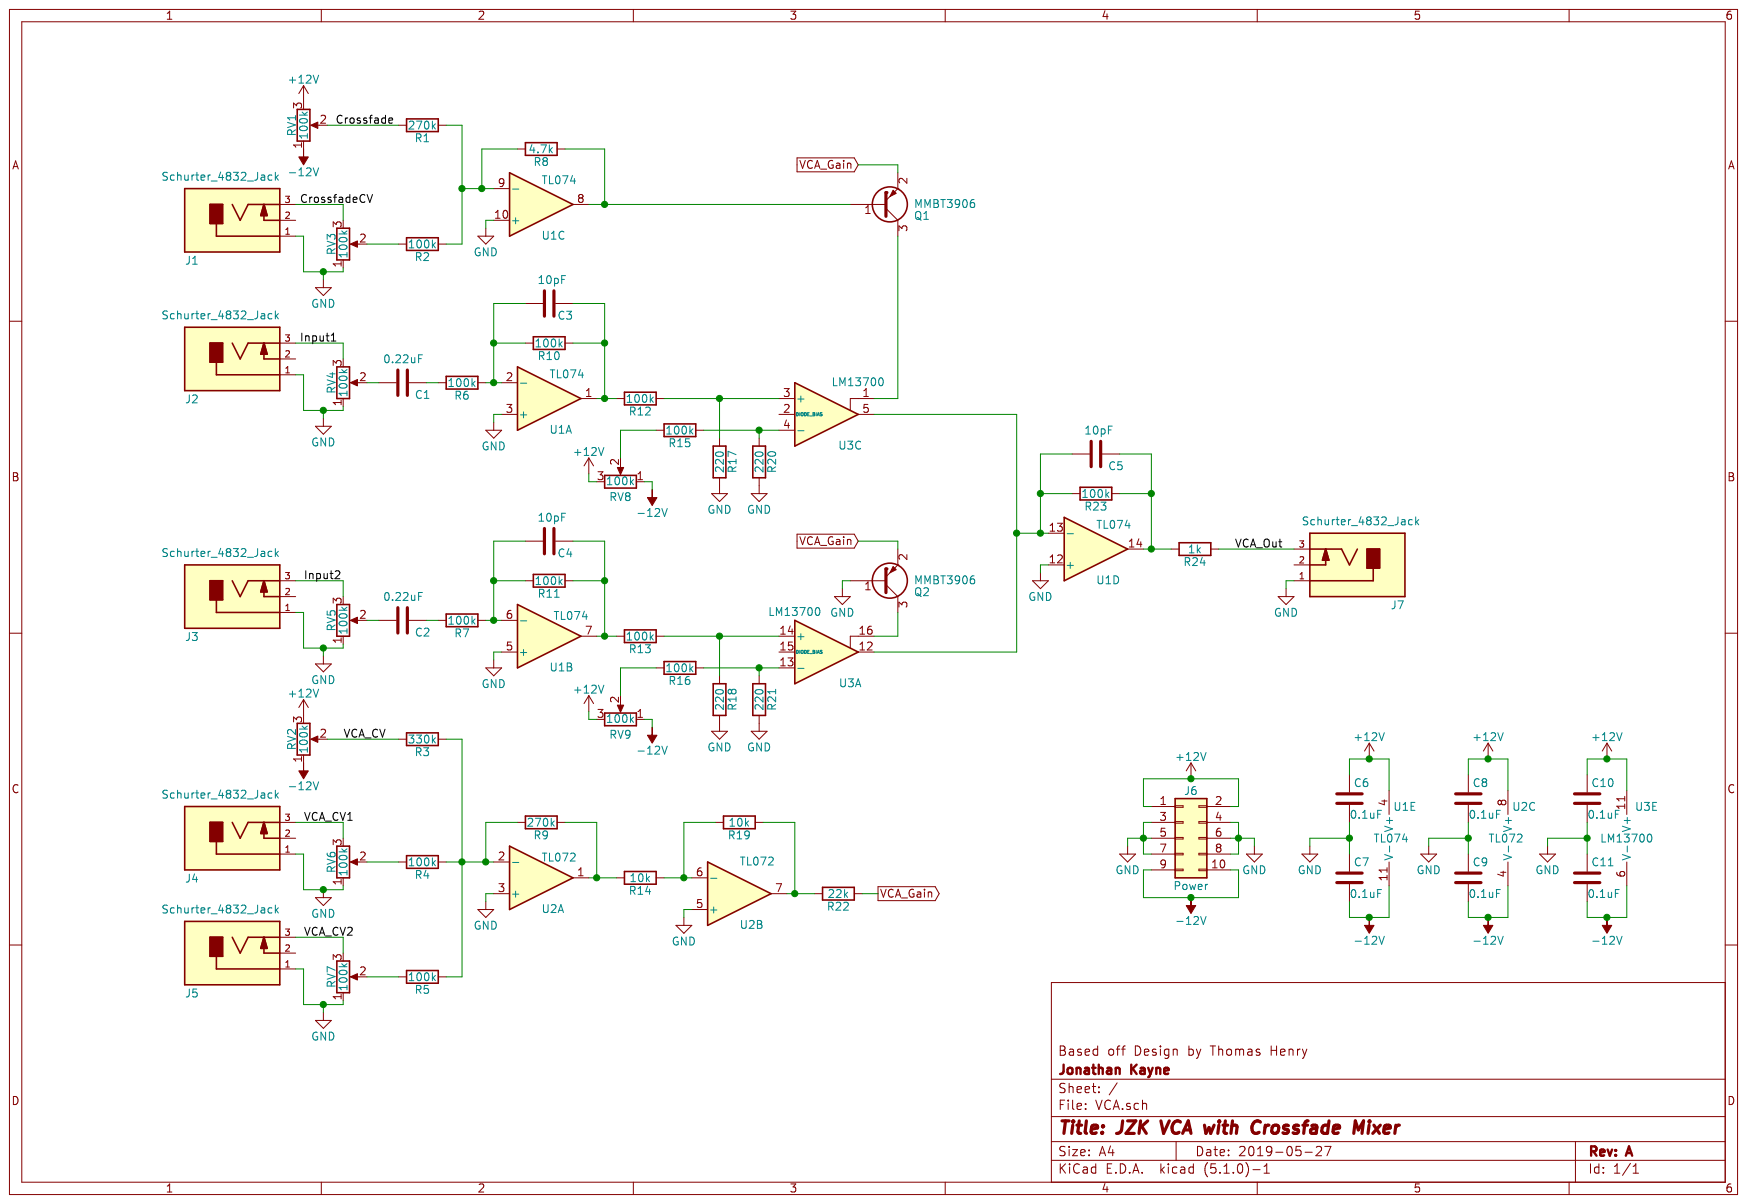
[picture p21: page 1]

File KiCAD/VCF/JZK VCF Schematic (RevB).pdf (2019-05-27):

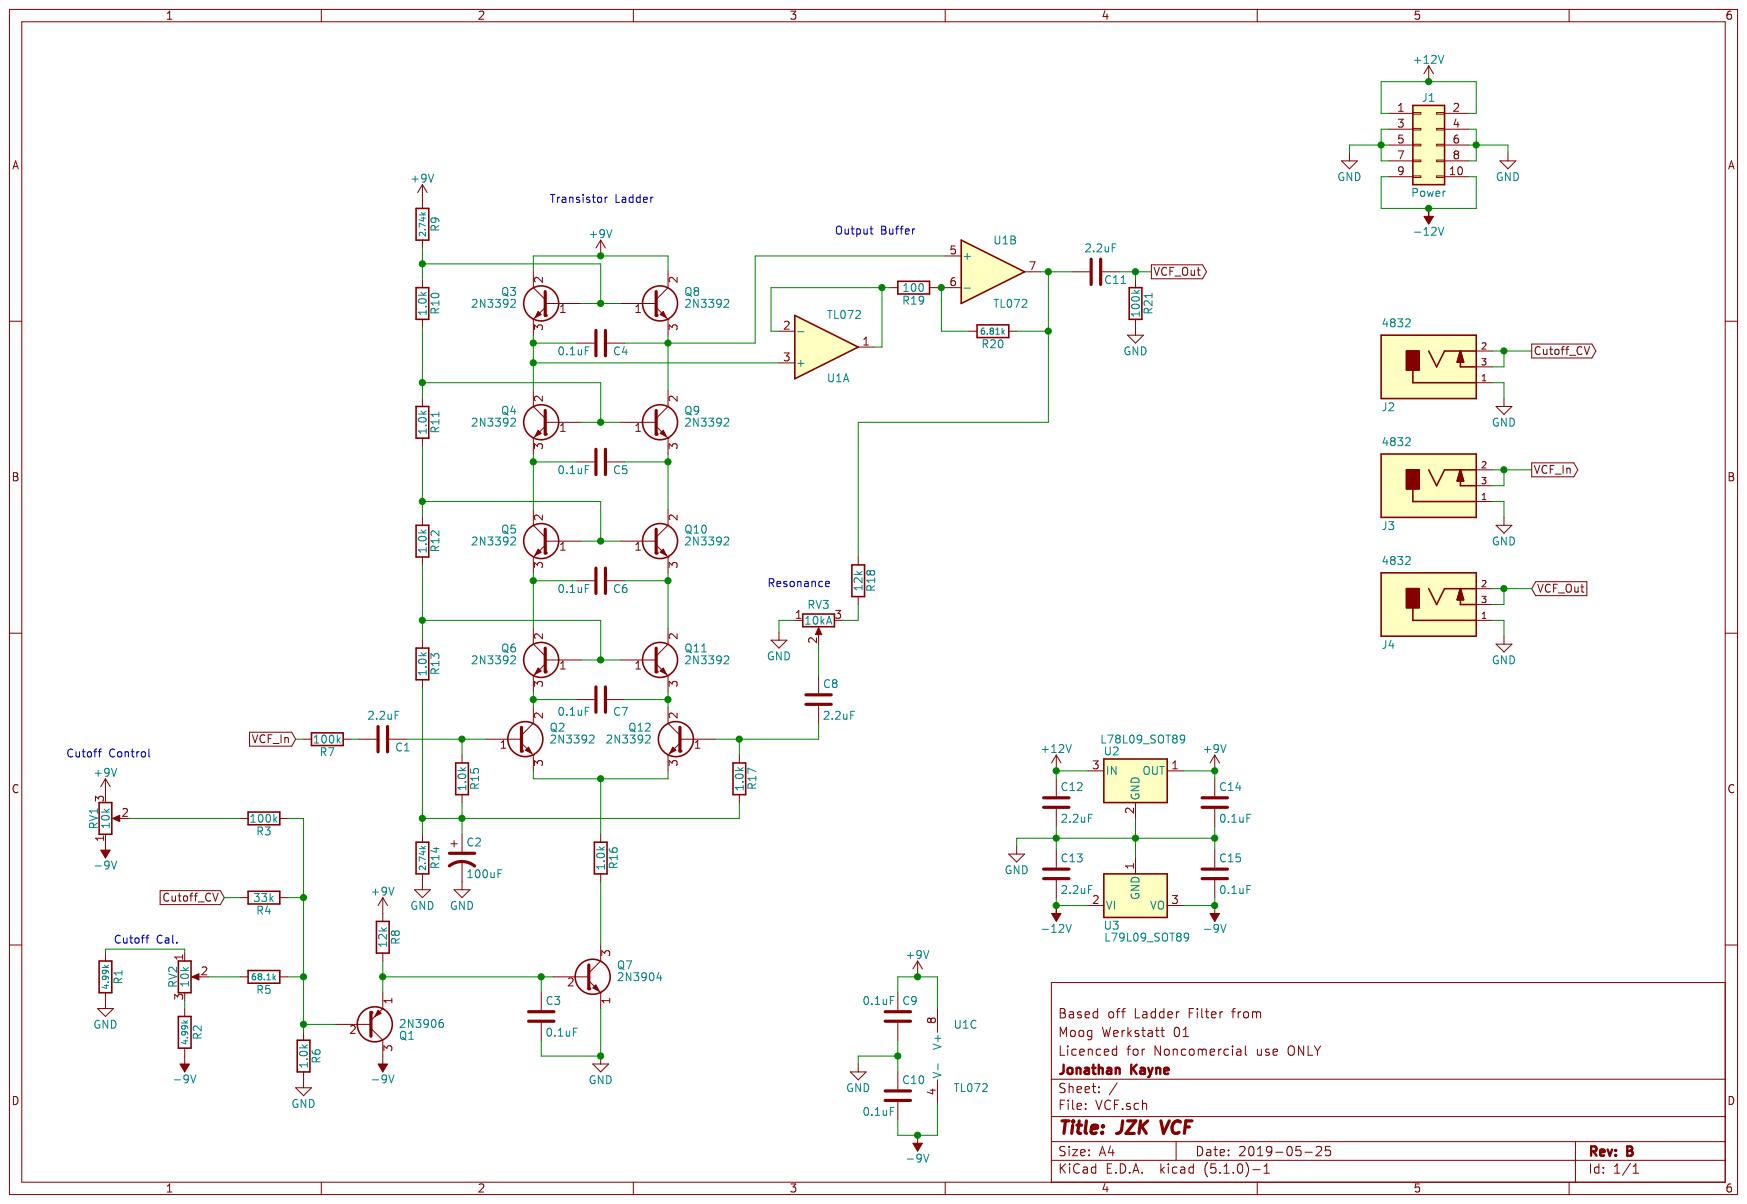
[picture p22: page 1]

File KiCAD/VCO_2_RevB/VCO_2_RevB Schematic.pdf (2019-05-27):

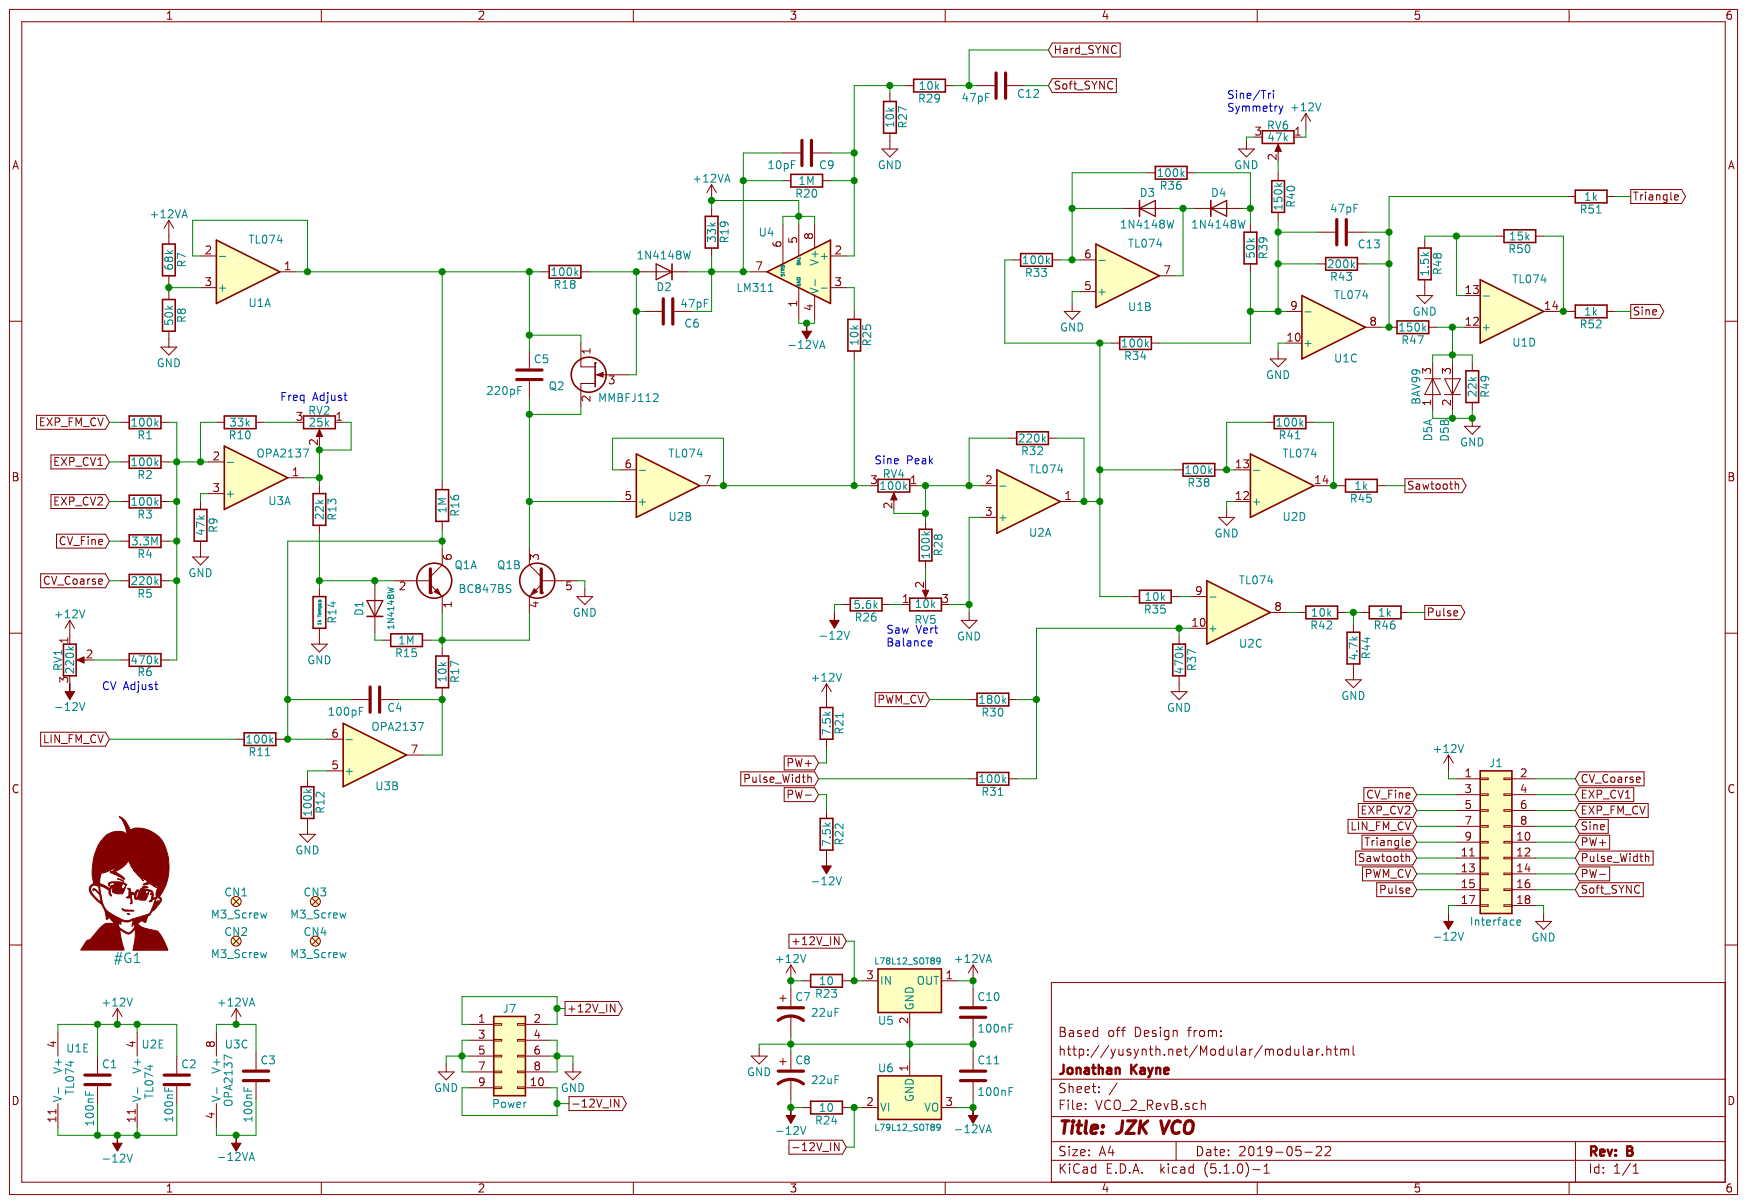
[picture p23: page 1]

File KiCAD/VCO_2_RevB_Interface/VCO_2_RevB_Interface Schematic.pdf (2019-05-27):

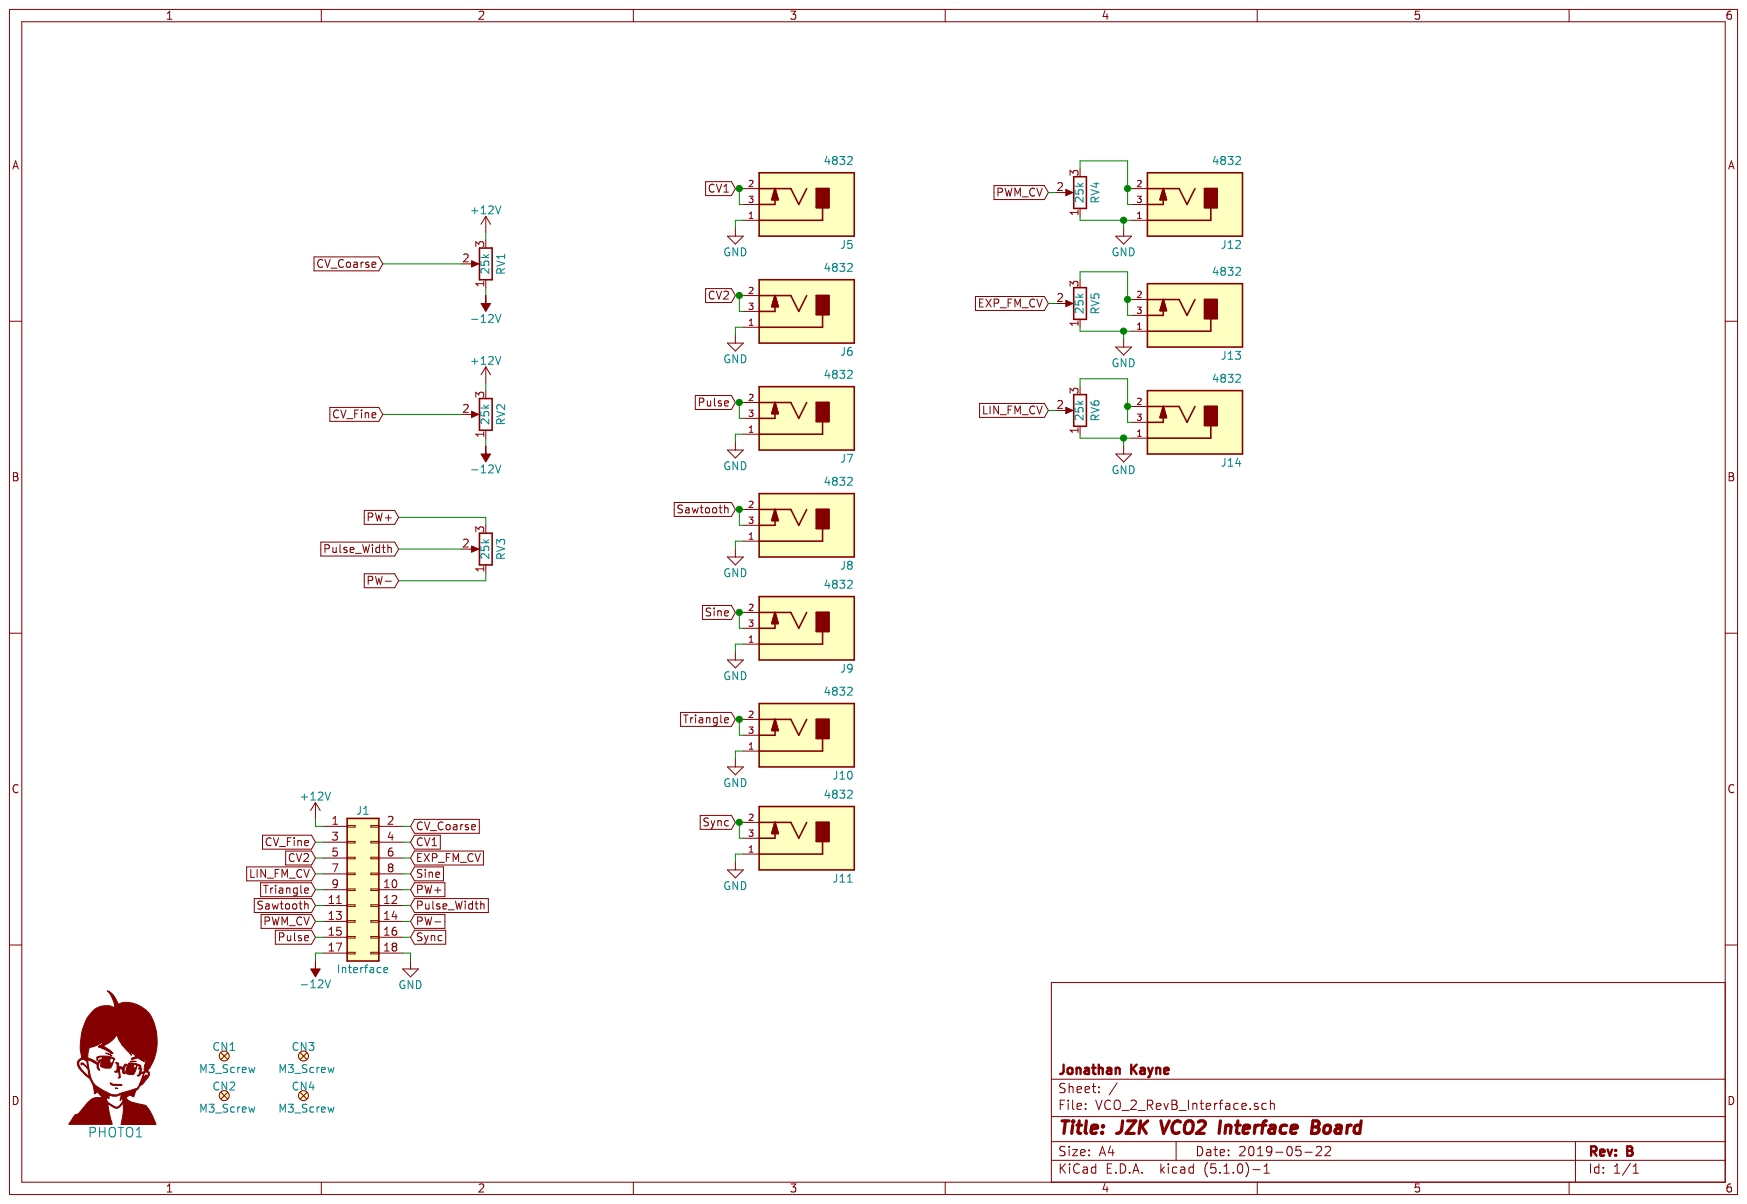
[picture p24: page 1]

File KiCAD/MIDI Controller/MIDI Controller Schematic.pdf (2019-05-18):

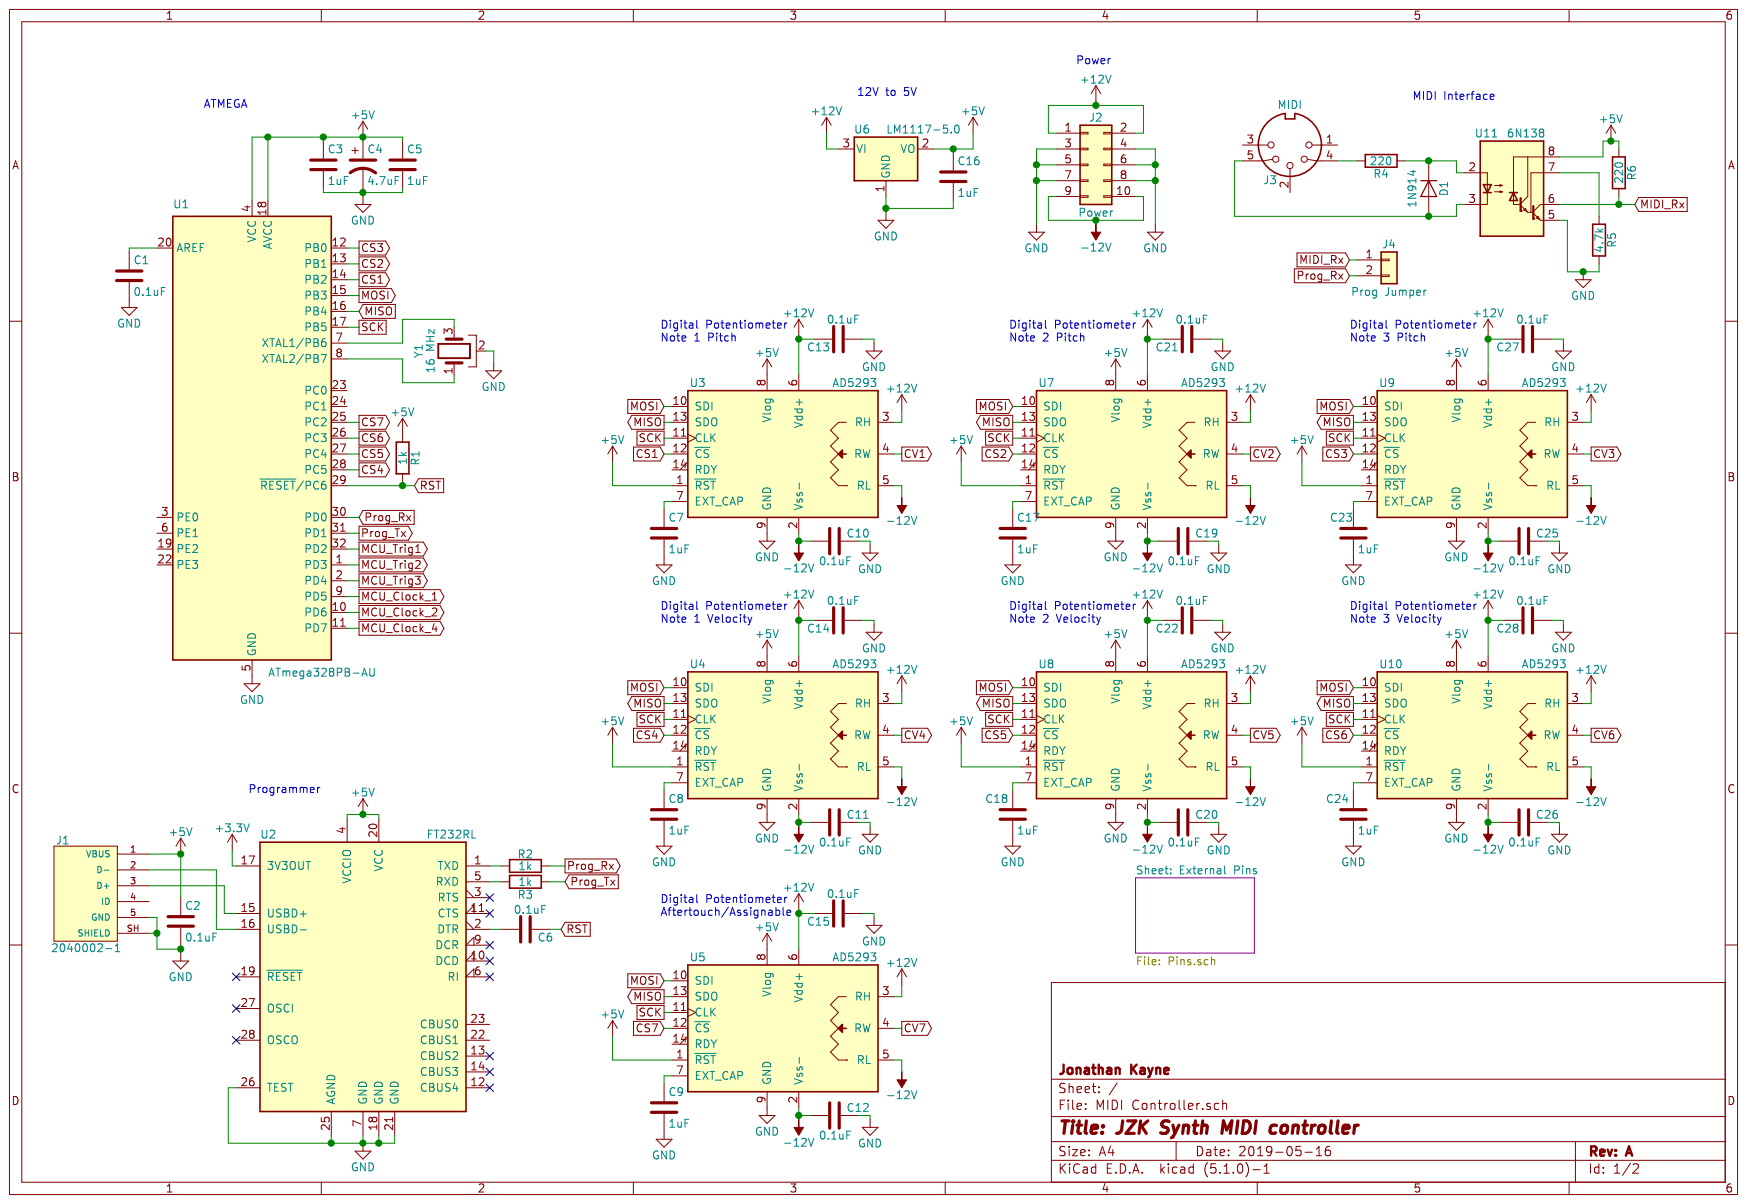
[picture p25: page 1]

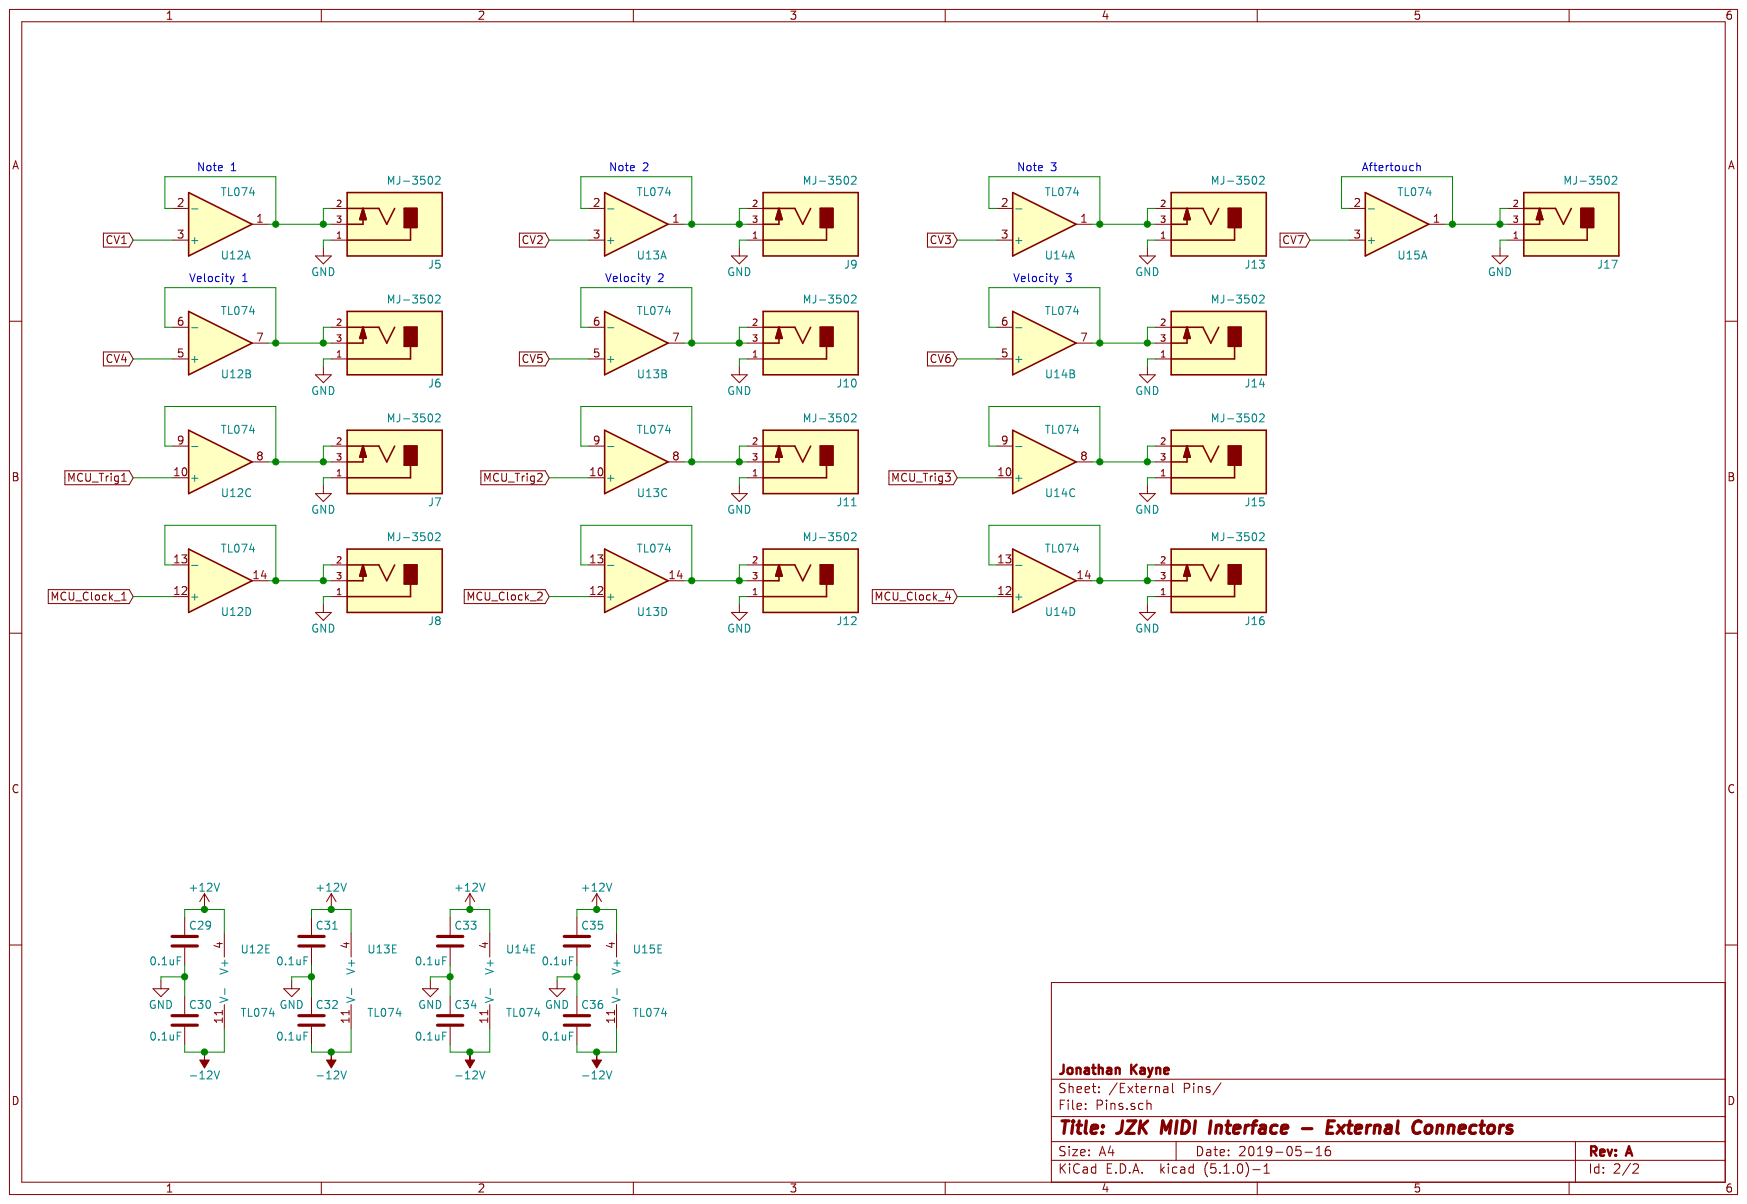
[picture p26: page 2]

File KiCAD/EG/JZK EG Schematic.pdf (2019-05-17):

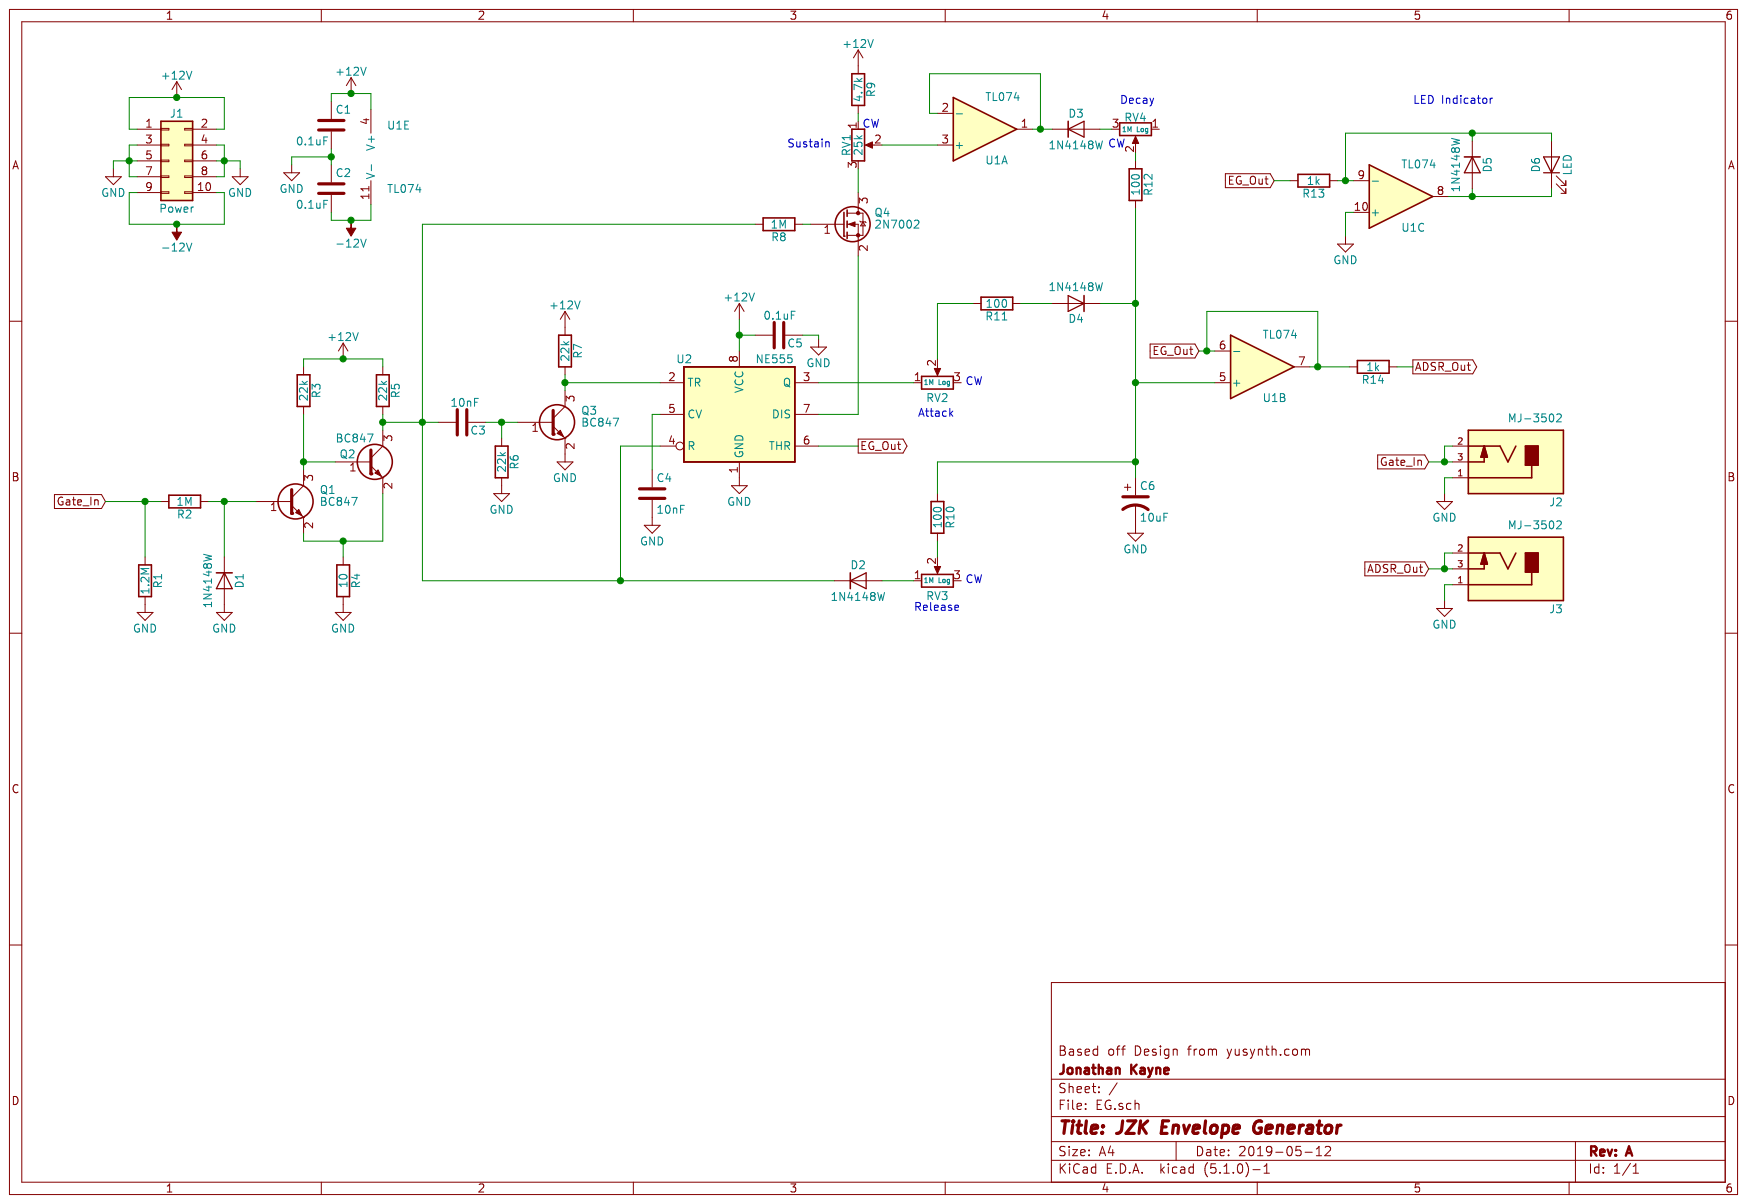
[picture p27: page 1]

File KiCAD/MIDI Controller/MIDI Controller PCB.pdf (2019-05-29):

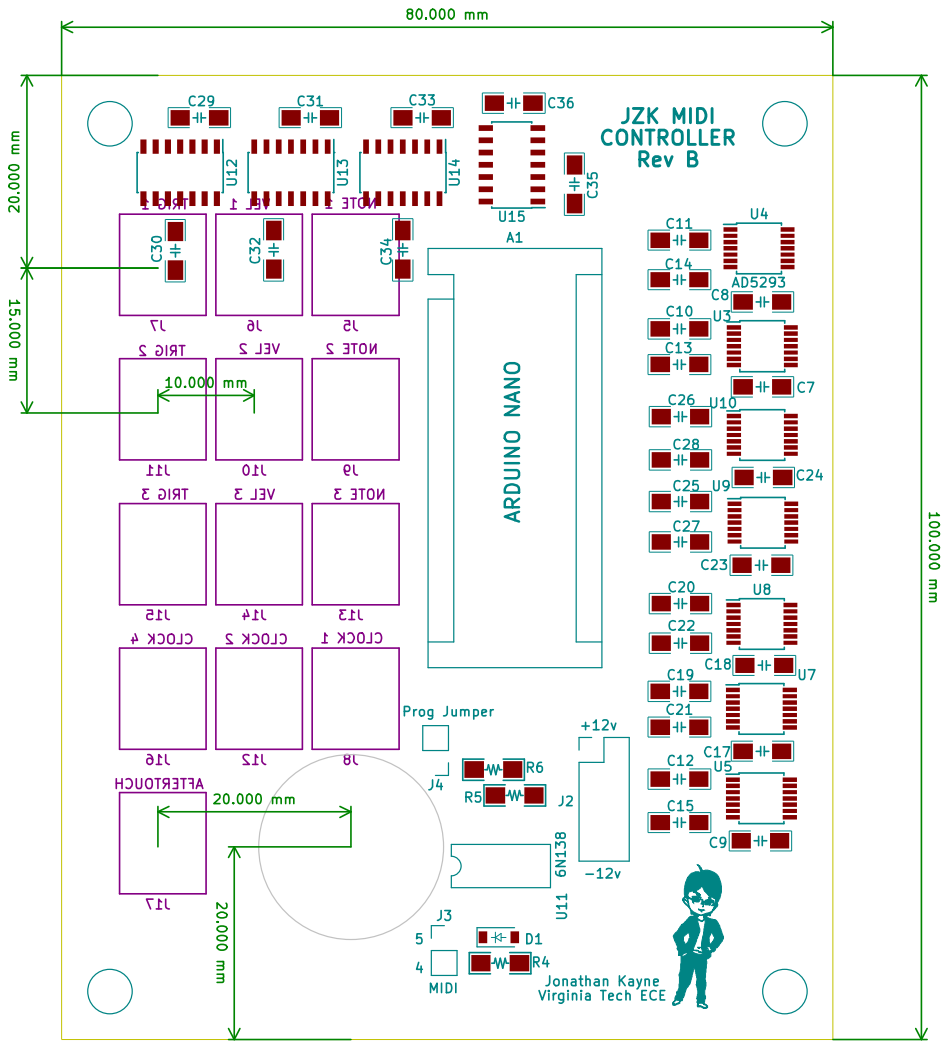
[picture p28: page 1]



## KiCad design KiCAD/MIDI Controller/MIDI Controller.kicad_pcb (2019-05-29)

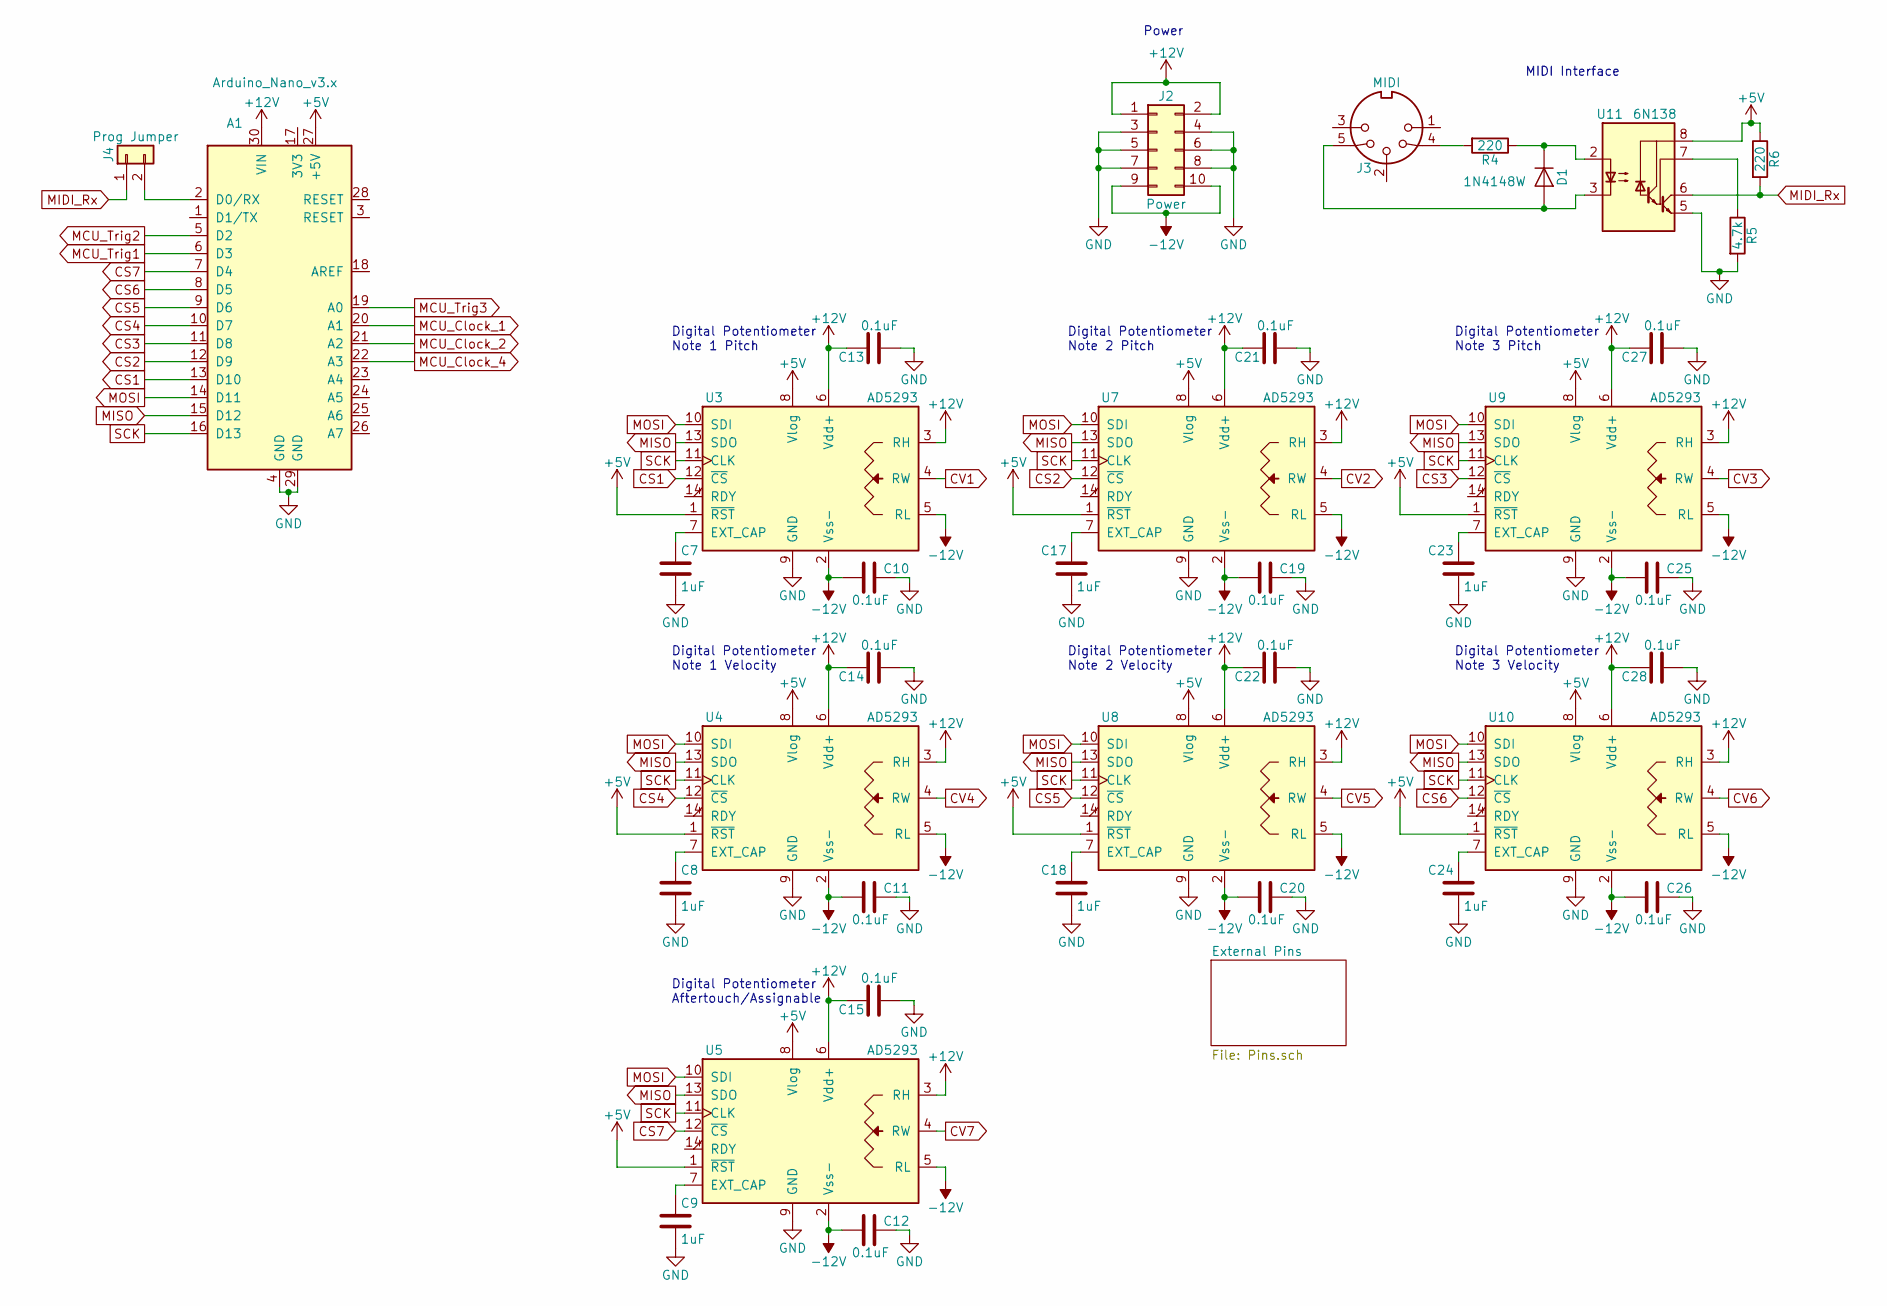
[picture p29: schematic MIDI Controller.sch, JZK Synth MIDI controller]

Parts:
A1: Arduino_Nano_v3.x; Arduino_Nano; Digikey PN B00NLAMS9C
C7, C8, C9, C17, C18, C23, C24: 1uF; C_1206; Digikey PN 399-1254-1-ND
C10, C11, C12, C13, C14, C15, C19, C20, C21, C22, C25, C26, C27, C28: 0.1uF; C_1206; Digikey PN 720-1540-1-ND
D1: 1N4148W; D_SOD-123; Digikey PN 1N4148WTPMSCT-ND
J2: Power; PinHeader_2x05_P2.54mm_Vertical_Zigzag; Digikey PN 609-3243-ND
J3: MIDI; PinHeader_1x02_P2.54mm_Vertical; Digikey PN CP-1250-ND
J4: Prog Jumper; PinHeader_1x02_P2.54mm_Vertical; Digikey PN 732-5315-ND
R4, R6: 220; R_1206; Digikey PN 311-220FRCT-ND
R5: 4.7k; R_1206; Digikey PN A130181CT-ND
U3, U4, U5, U7, U8, U9, U10: AD5293; TSSOP-14_4.4x5mm_P0.65mm; Digikey PN AD5293BRUZ-100-RL7CT-ND
U11: 6N138; DIP-8_W7.62mm_LongPads; Digikey PN 160-1795-ND

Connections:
+5V: A1.27 (+5V), R6.1, U3.1 (~RST~), U3.8 (Vlog), U4.1 (~RST~), U4.8 (Vlog), U5.1 (~RST~), U5.8 (Vlog), U7.1 (~RST~), U7.8 (Vlog), U8.1 (~RST~), U8.8 (Vlog), U9.1 (~RST~), U9.8 (Vlog), U10.1 (~RST~), U10.8 (Vlog), U11.8 (VCC)
+12V: A1.30 (VIN), C13.2, C14.2, C15.2, C21.2, C22.2, C27.2, C28.2, J2.1, J2.2, U3.3 (RH), U3.6 (Vdd+), U4.3 (RH), U4.6 (Vdd+), U5.3 (RH), U5.6 (Vdd+), U7.3 (RH), U7.6 (Vdd+), U8.3 (RH), U8.6 (Vdd+), U9.3 (RH), U9.6 (Vdd+), U10.3 (RH), U10.6 (Vdd+); also elsewhere on the board
-12V: C10.2, C11.2, C12.2, C19.2, C20.2, C25.2, C26.2, J2.9, J2.10, U3.2 (Vss-), U3.5 (RL), U4.2 (Vss-), U4.5 (RL), U5.2 (Vss-), U5.5 (RL), U7.2 (Vss-), U7.5 (RL), U8.2 (Vss-), U8.5 (RL), U9.2 (Vss-), U9.5 (RL), U10.2 (Vss-), U10.5 (RL); also elsewhere on the board
CS1: A1.13 (D10), U3.12 (~CS~)
CS2: A1.12 (D9), U7.12 (~CS~)
CS3: A1.11 (D8), U9.12 (~CS~)
CS4: A1.10 (D7), U4.12 (~CS~)
CS5: A1.9 (D6), U8.12 (~CS~)
CS6: A1.8 (D5), U10.12 (~CS~)
CS7: A1.7 (D4), U5.12 (~CS~)
CV1: U3.4 (RW); also elsewhere on the board
CV2: U7.4 (RW); also elsewhere on the board
CV3: U9.4 (RW); also elsewhere on the board
CV4: U4.4 (RW); also elsewhere on the board
CV5: U8.4 (RW); also elsewhere on the board
CV6: U10.4 (RW); also elsewhere on the board
CV7: U5.4 (RW); also elsewhere on the board
GND: A1.4 (GND), A1.29 (GND), C7.2, C8.2, C9.2, C10.1, C11.1, C12.1, C13.1, C14.1, C15.1, C17.2, C18.2, C19.1, C20.1, C21.1, C22.1, C23.2, C24.2, C25.1, C26.1, C27.1, C28.1, J2.3, J2.4, J2.5, J2.6, J2.7, J2.8, R5.2, U3.9 (GND), U4.9 (GND), U5.9 (GND), U7.9 (GND), U8.9 (GND), U9.9 (GND), U10.9 (GND), U11.5 (GND); also elsewhere on the board
MCU_Clock_1: A1.20 (A1); also elsewhere on the board
MCU_Clock_2: A1.21 (A2); also elsewhere on the board
MCU_Clock_4: A1.22 (A3); also elsewhere on the board
MCU_Trig1: A1.6 (D3); also elsewhere on the board
MCU_Trig2: A1.5 (D2); also elsewhere on the board
MCU_Trig3: A1.19 (A0); also elsewhere on the board
MIDI_Rx: J4.1, R6.2, U11.6 (VO2)
MISO: A1.15 (D12), U3.13 (SDO), U4.13 (SDO), U5.13 (SDO), U7.13 (SDO), U8.13 (SDO), U9.13 (SDO), U10.13 (SDO)
MOSI: A1.14 (D11), U3.10 (SDI), U4.10 (SDI), U5.10 (SDI), U7.10 (SDI), U8.10 (SDI), U9.10 (SDI), U10.10 (SDI)
unnamed: A1.2 (D0/RX), J4.2
unnamed: C7.1, U3.7 (EXT_CAP)
unnamed: C8.1, U4.7 (EXT_CAP)
unnamed: C9.1, U5.7 (EXT_CAP)
unnamed: C17.1, U7.7 (EXT_CAP)
unnamed: C18.1, U8.7 (EXT_CAP)
unnamed: C23.1, U9.7 (EXT_CAP)
unnamed: C24.1, U10.7 (EXT_CAP)
unnamed: D1.1 (K), R4.1, U11.2 (C1)
unnamed: D1.2 (A), J3.5, U11.3 (C2)
unnamed: J3.4, R4.2
unnamed: R5.1, U11.7 (VO1)
SCK: A1.16 (D13), U3.11 (CLK), U4.11 (CLK), U5.11 (CLK), U7.11 (CLK), U8.11 (CLK), U9.11 (CLK), U10.11 (CLK)

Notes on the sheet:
Power
MIDI Interface
Digital Potentiometer Note 1 Pitch
Digital Potentiometer Note 2 Pitch
Digital Potentiometer Note 3 Pitch
Digital Potentiometer Note 1 Velocity
Digital Potentiometer Note 2 Velocity
Digital Potentiometer Note 3 Velocity
Digital Potentiometer Aftertouch/Assignable

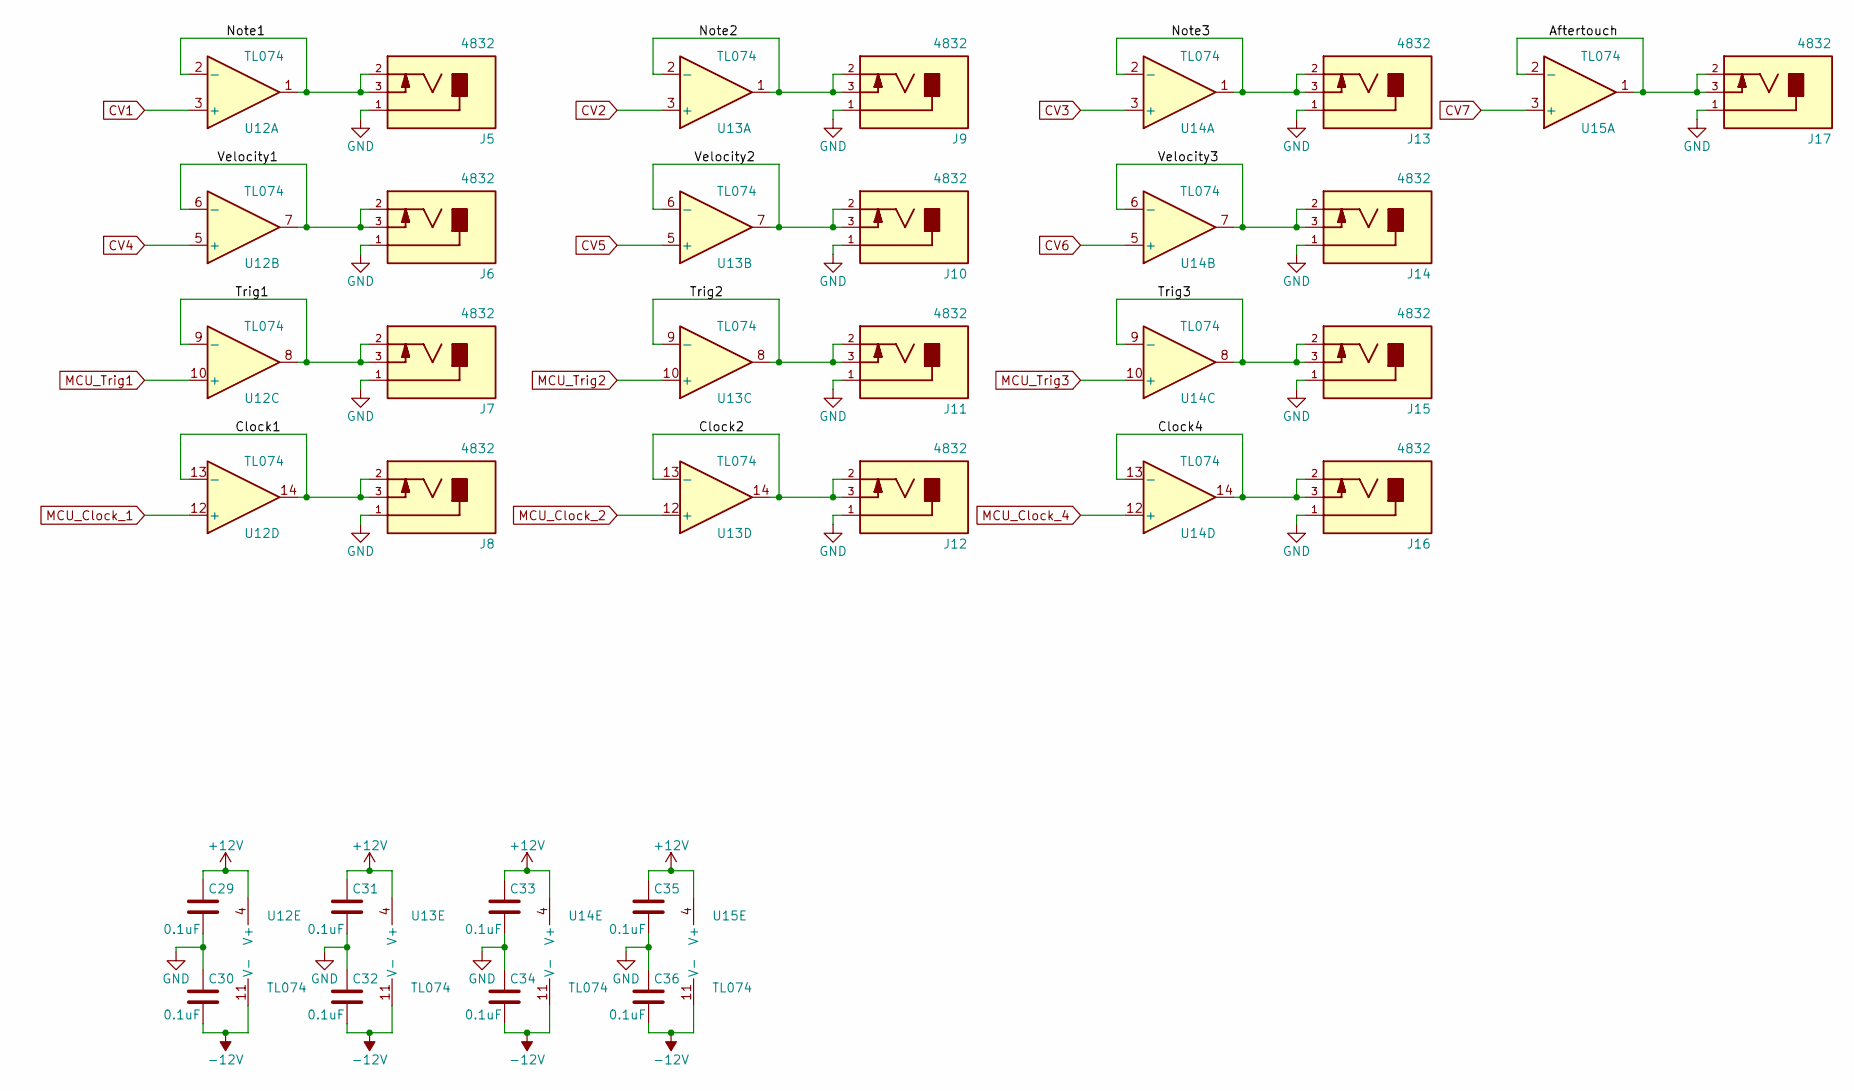
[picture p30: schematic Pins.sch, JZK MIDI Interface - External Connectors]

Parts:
C29, C30, C31, C32, C33, C34, C35, C36: 0.1uF; C_1206; Digikey PN 720-1540-1-ND
J5, J6, J7, J8, J9, J10, J11, J12, J13, J14, J15, J16, J17: 4832; Schurter_4832_Jack; Digikey PN 486-3418-ND
U12, U13, U14, U15: TL074; SOIC-14_3.9x8.7mm_P1.27mm; Digikey PN 296-1283-1-ND

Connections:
+12V: C29.1, C31.1, C33.1, C35.1, U12.4 (V+), U13.4 (V+), U14.4 (V+), U15.4 (V+); also elsewhere on the board
-12V: C30.2, C32.2, C34.2, C36.2, U12.11 (V-), U13.11 (V-), U14.11 (V-), U15.11 (V-); also elsewhere on the board
/External Pins/Aftertouch: J17.2, J17.3, U15.1, U15.2 (-)
/External Pins/Clock1: J8.2, J8.3, U12.13 (-), U12.14
/External Pins/Clock2: J12.2, J12.3, U13.13 (-), U13.14
/External Pins/Clock4: J16.2, J16.3, U14.13 (-), U14.14
/External Pins/Note1: J5.2, J5.3, U12.1, U12.2 (-)
/External Pins/Note2: J9.2, J9.3, U13.1, U13.2 (-)
/External Pins/Note3: J13.2, J13.3, U14.1, U14.2 (-)
/External Pins/Trig1: J7.2, J7.3, U12.8, U12.9 (-)
/External Pins/Trig2: J11.2, J11.3, U13.8, U13.9 (-)
/External Pins/Trig3: J15.2, J15.3, U14.8, U14.9 (-)
/External Pins/Velocity1: J6.2, J6.3, U12.6 (-), U12.7
/External Pins/Velocity2: J10.2, J10.3, U13.6 (-), U13.7
/External Pins/Velocity3: J14.2, J14.3, U14.6 (-), U14.7
CV1: U12.3 (+); also elsewhere on the board
CV2: U13.3 (+); also elsewhere on the board
CV3: U14.3 (+); also elsewhere on the board
CV4: U12.5 (+); also elsewhere on the board
CV5: U13.5 (+); also elsewhere on the board
CV6: U14.5 (+); also elsewhere on the board
CV7: U15.3 (+); also elsewhere on the board
GND: C29.2, C30.1, C31.2, C32.1, C33.2, C34.1, C35.2, C36.1, J5.1, J6.1, J7.1, J8.1, J9.1, J10.1, J11.1, J12.1, J13.1, J14.1, J15.1, J16.1, J17.1; also elsewhere on the board
MCU_Clock_1: U12.12 (+); also elsewhere on the board
MCU_Clock_2: U13.12 (+); also elsewhere on the board
MCU_Clock_4: U14.12 (+); also elsewhere on the board
MCU_Trig1: U12.10 (+); also elsewhere on the board
MCU_Trig2: U13.10 (+); also elsewhere on the board
MCU_Trig3: U14.10 (+); also elsewhere on the board

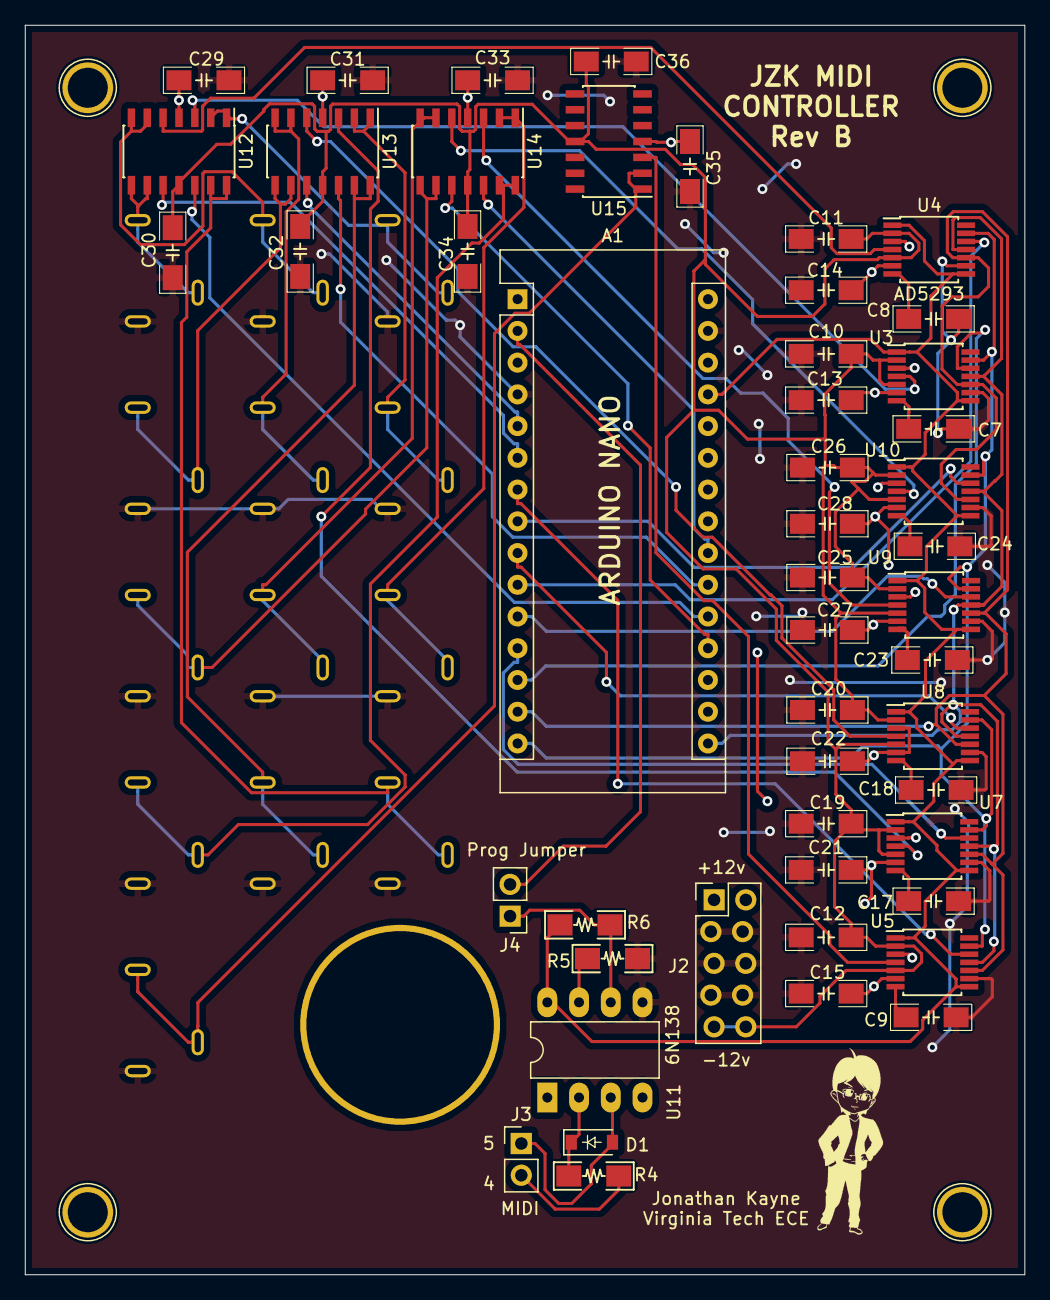
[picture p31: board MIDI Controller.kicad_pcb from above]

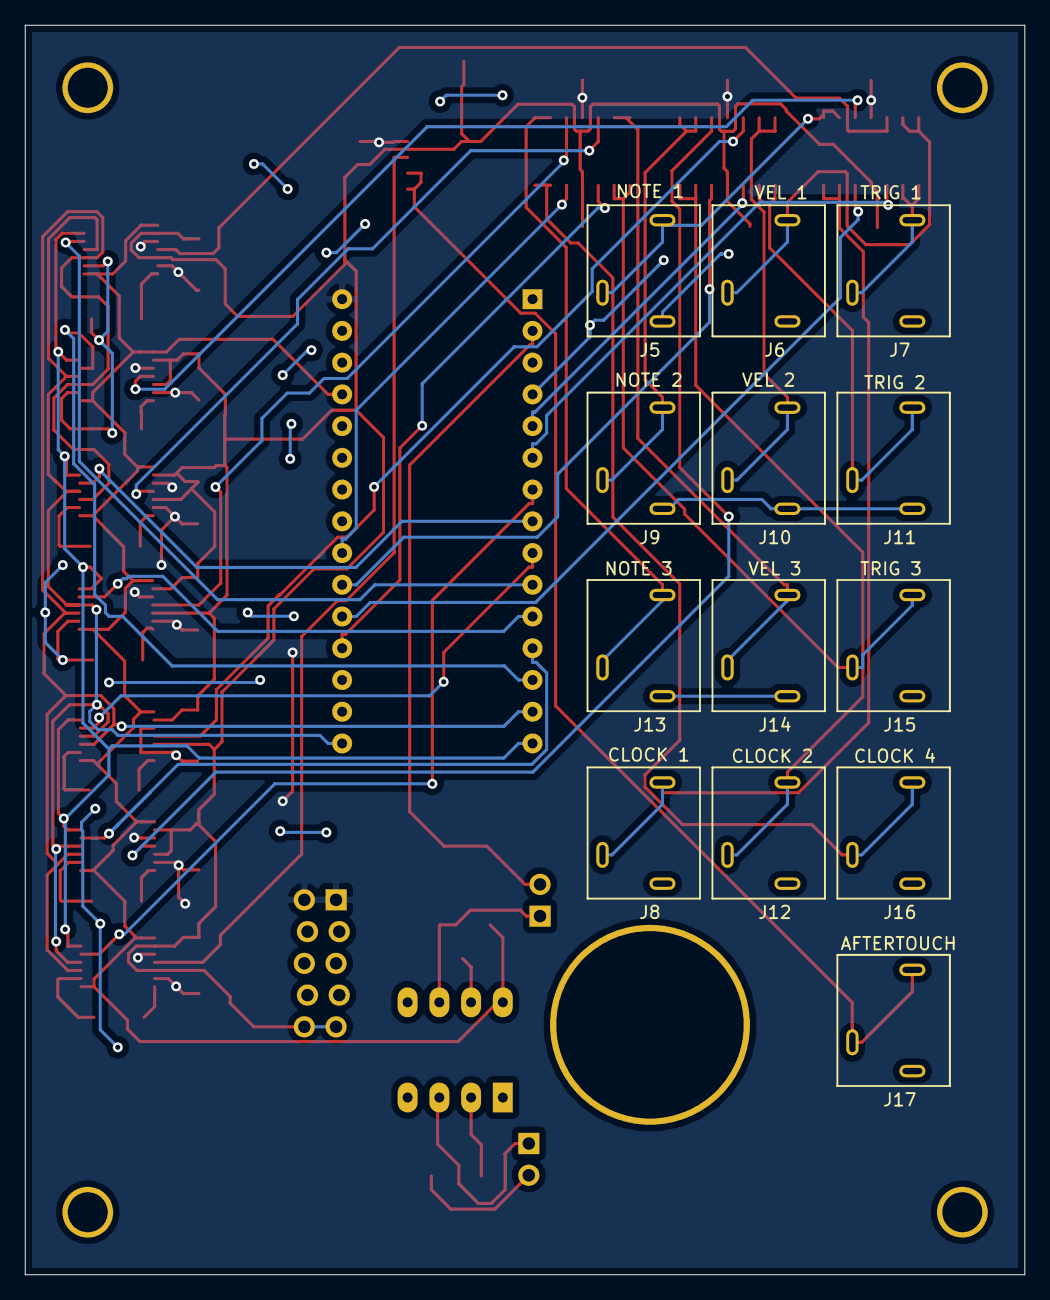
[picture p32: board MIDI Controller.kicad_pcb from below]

Board: 2 copper layers, 80.0 x 100.0 mm, 66 parts (13 on the bottom side), 53 nets.

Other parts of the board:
SC1, SC2, SC3, SC4: M3_Screw_Hole

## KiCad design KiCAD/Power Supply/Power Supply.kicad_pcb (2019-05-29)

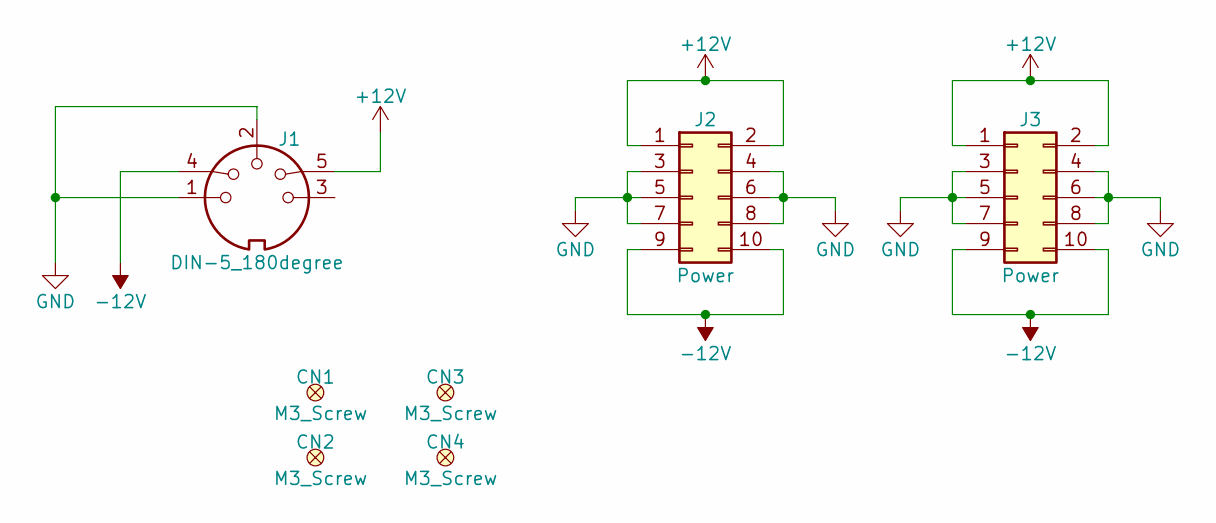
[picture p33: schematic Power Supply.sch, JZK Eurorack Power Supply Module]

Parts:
CN1, CN2, CN3, CN4: M3_Screw; M3_Screw_Hole; Digikey PN N/A
J1: DIN-5_180degree; PinHeader_1x05_P2.54mm_Vertical
J2, J3: Power; PinHeader_2x05_P2.54mm_Vertical_Zigzag

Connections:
+12V: J1.5, J2.1, J2.2, J3.1, J3.2
-12V: J1.4, J2.9, J2.10, J3.9, J3.10
GND: J1.1, J1.2, J2.3, J2.4, J2.5, J2.6, J2.7, J2.8, J3.3, J3.4, J3.5, J3.6, J3.7, J3.8

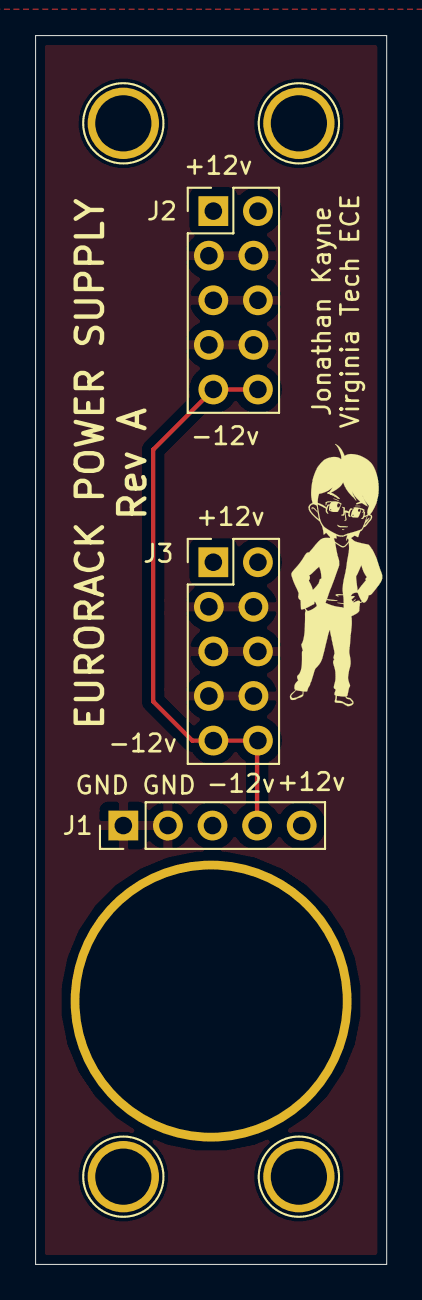
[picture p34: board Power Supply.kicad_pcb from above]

Board: 2 copper layers, 20.0 x 70.0 mm, 7 parts (0 on the bottom side), 3 nets.

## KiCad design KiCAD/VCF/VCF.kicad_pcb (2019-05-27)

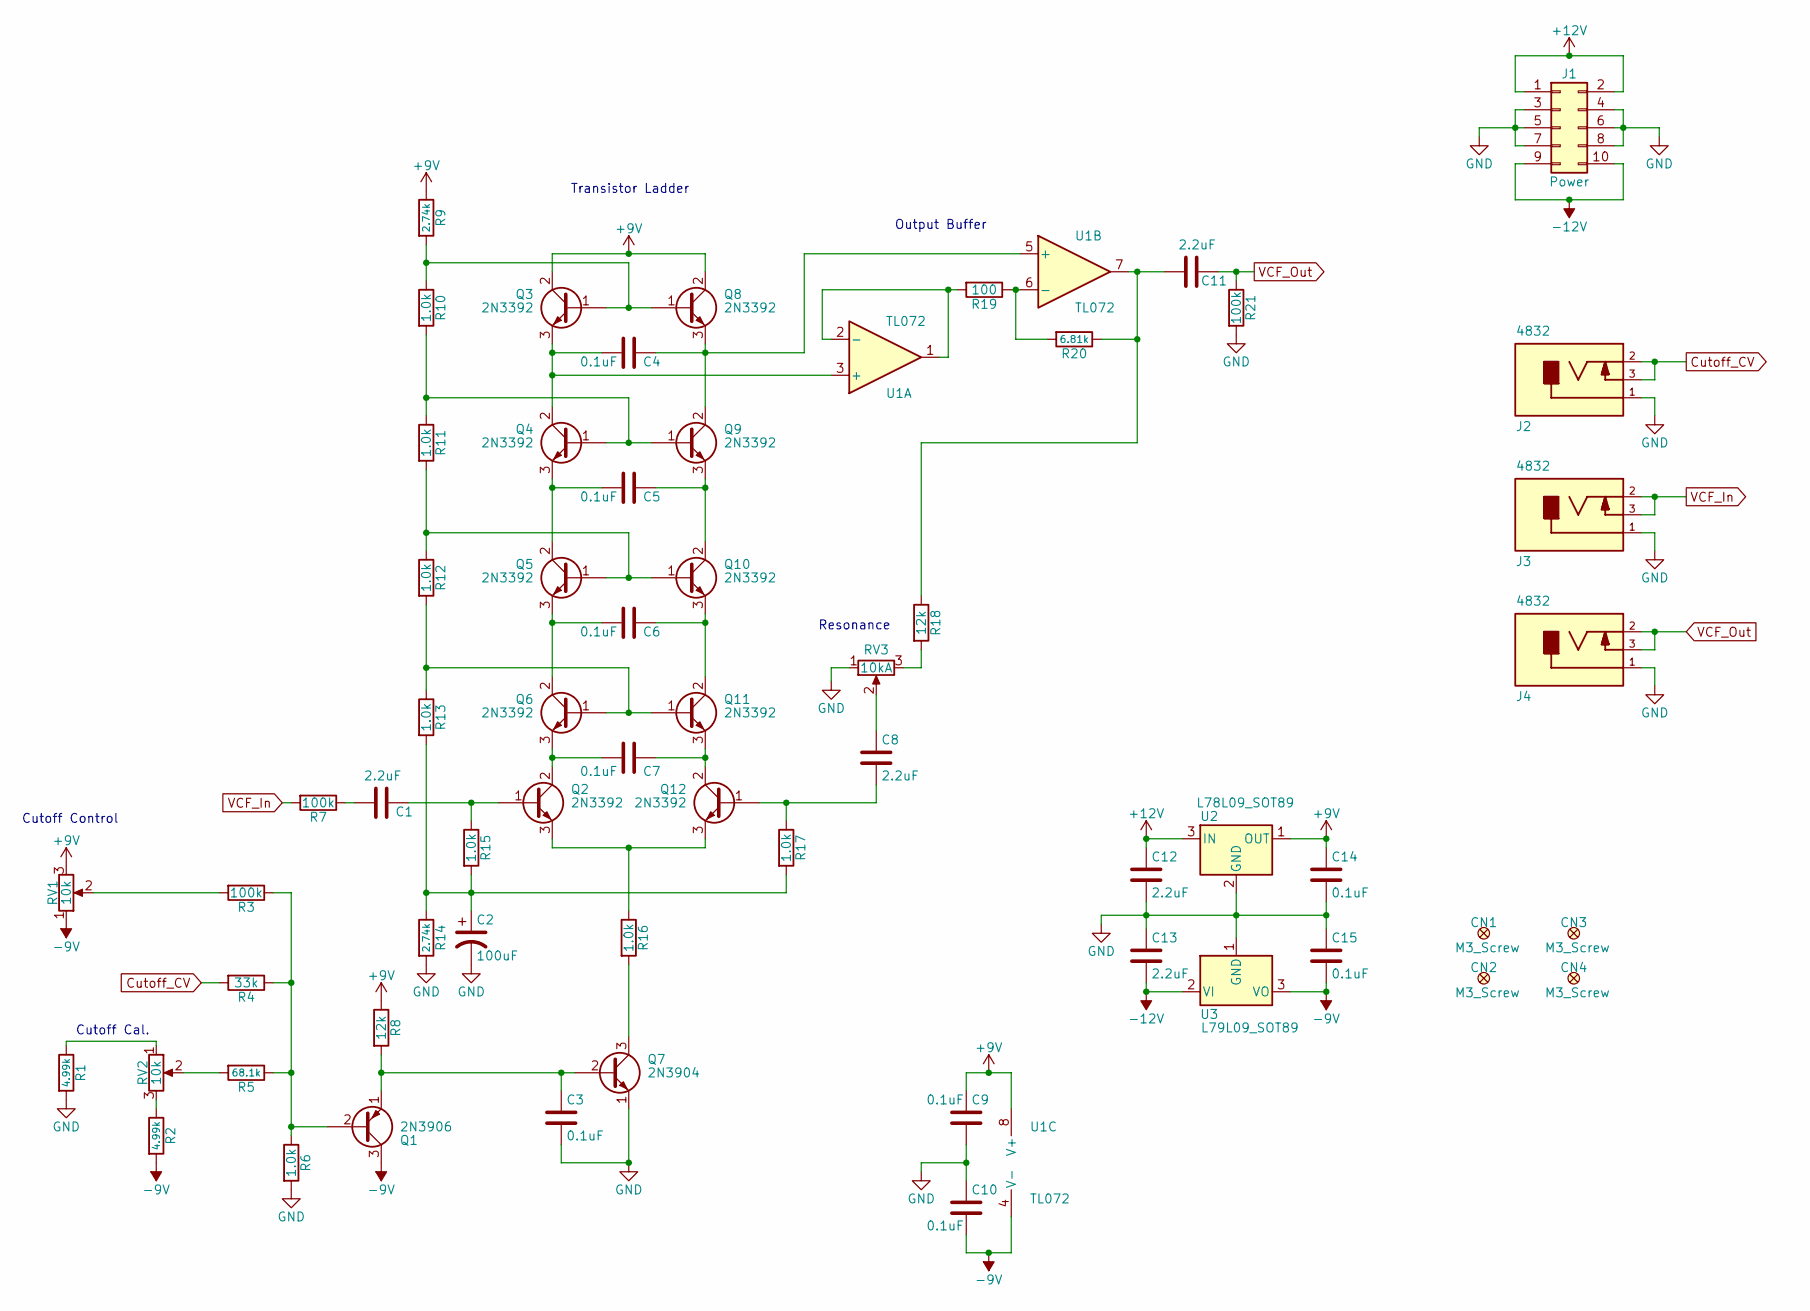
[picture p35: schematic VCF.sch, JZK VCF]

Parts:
C1, C8, C11, C12, C13: 2.2uF; C_1206; Digikey PN 1276-1072-1-ND
C2: 100uF; CP_Tantalum_7343; Digikey PN 399-9749-1-ND
C3, C4, C5, C6, C7, C9, C10, C14, C15: 0.1uF; C_1206; Digikey PN 720-1540-1-ND
CN1, CN2, CN3, CN4: M3_Screw; M3_Screw_Hole; Digikey Link N/A
J1: Power; PinHeader_2x05_P2.54mm_Vertical_Zigzag; Digikey PN 609-3243-ND
J2, J3, J4: 4832; Schurter_4832_Jack; Digikey PN 486-3418-ND
Q1: 2N3906; TO-92_HandSolder; Digikey PN 2N3906TARFSCT-ND
Q2, Q3, Q4, Q5, Q6, Q8, Q9, Q10, Q11, Q12: 2N3392; TO-92_HandSolder; Digikey PN 2N3392CS-ND
Q7: 2N3904; TO-92_HandSolder; Digikey PN 2N3904FS-ND
R1, R2: 4.99k; R_1206; Digikey PN RNCP1206FTD4K99CT-ND
R3, R7, R21: 100k; R_1206; Digikey PN A129834CT-ND
R4: 33k; R_1206; Digikey PN RMCF1206JT33K0CT-ND
R5: 68.1k; R_1206; Digikey PN RNCP1206FTD68K1CT-ND
R6, R10, R11, R12, R13, R15, R16, R17: 1.0k; R_1206; Digikey PN 311-1.0KERCT-ND
R8, R18: 12k; R_1206; Digikey PN A129823CT-ND
R9, R14: 2.74k; R_1206; Digikey PN 311-2.74KFRCT-ND
R19: 100; R_1206; Digikey PN RNCP1206FTD100RCT-ND
R20: 6.81k; R_1206; Digikey PN RNCP1206FTD6K81CT-ND
RV1: 10k; Potentiometer_Bourns_PTV09A-1_Single_Vertical; Digikey PN PTV09A-4020F-B103-ND
RV2: 10k; Potentiometer_Piher_PT-10-V10_Vertical; Digikey PN 1993-1104-ND
RV3: 10kA; Potentiometer_Bourns_PTV09A-1_Single_Vertical; Digikey PN PTV09A-4020F-A103-ND
U1: TL072; SOIC-8_3.9x4.9mm_P1.27mm; Digikey PN 296-1282-1-ND
U2: L78L09_SOT89; SOT-89-3; Digikey PN 497-1192-1-ND
U3: L79L09_SOT89; SOT-89-3; Digikey PN NJM79L09UA-TE1CT-ND

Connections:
+9V: C9.1, C14.1, Q3.2 (C), Q8.2 (C), R8.1, R9.1, RV1.3, U1.8 (V+), U2.1 (OUT)
+12V: C12.1, J1.1, J1.2, U2.3 (IN)
-9V: C10.2, C15.2, Q1.3 (C), R2.2, RV1.1, U1.4 (V-), U3.3 (VO)
-12V: C13.2, J1.9, J1.10, U3.2 (VI)
Cutoff_CV: J2.2, J2.3, R4.2
GND: C2.2, C3.2, C9.2, C10.1, C12.2, C13.1, C14.2, C15.1, J1.3, J1.4, J1.5, J1.6, J1.7, J1.8, J2.1, J3.1, J4.1, Q7.1 (E), R1.2, R6.2, R14.2, R21.2, RV3.1, U2.2 (GND), U3.1 (GND)
unnamed: C1.1, Q2.1 (B), R15.1
unnamed: C1.2, R7.1
unnamed: C2.1, R13.2, R14.1, R15.2, R17.2
unnamed: C3.1, Q1.1 (E), Q7.2 (B), R8.2
unnamed: C4.1, Q8.3 (E), Q9.2 (C), U1.5 (+)
unnamed: C4.2, Q3.3 (E), Q4.2 (C), U1.3 (+)
unnamed: C5.1, Q9.3 (E), Q10.2 (C)
unnamed: C5.2, Q4.3 (E), Q5.2 (C)
unnamed: C6.1, Q10.3 (E), Q11.2 (C)
unnamed: C6.2, Q5.3 (E), Q6.2 (C)
unnamed: C7.1, Q11.3 (E), Q12.2 (C)
unnamed: C7.2, Q2.2 (C), Q6.3 (E)
unnamed: C8.1, RV3.2
unnamed: C8.2, Q12.1 (B), R17.1
unnamed: C11.2, R18.1, R20.1, U1.7
unnamed: Q1.2 (B), R3.1, R4.1, R5.1, R6.1
unnamed: Q3.1 (B), Q8.1 (B), R9.2, R10.1
unnamed: Q4.1 (B), Q9.1 (B), R10.2, R11.1
unnamed: Q7.3 (C), R16.2
unnamed: Q5.1 (B), Q10.1 (B), R11.2, R12.1
unnamed: Q6.1 (B), Q11.1 (B), R12.2, R13.1
unnamed: Q2.3 (E), Q12.3 (E), R16.1
unnamed: R1.1, RV2.1
unnamed: R2.1, RV2.3
unnamed: R3.2, RV1.2
unnamed: R5.2, RV2.2
unnamed: R18.2, RV3.3
unnamed: R19.1, R20.2, U1.6 (-)
unnamed: R19.2, U1.1, U1.2 (-)
VCF_In: J3.2, J3.3, R7.2
VCF_Out: C11.1, J4.2, J4.3, R21.1

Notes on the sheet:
Cutoff Control
Cutoff Cal.
Transistor Ladder
Output Buffer
Resonance

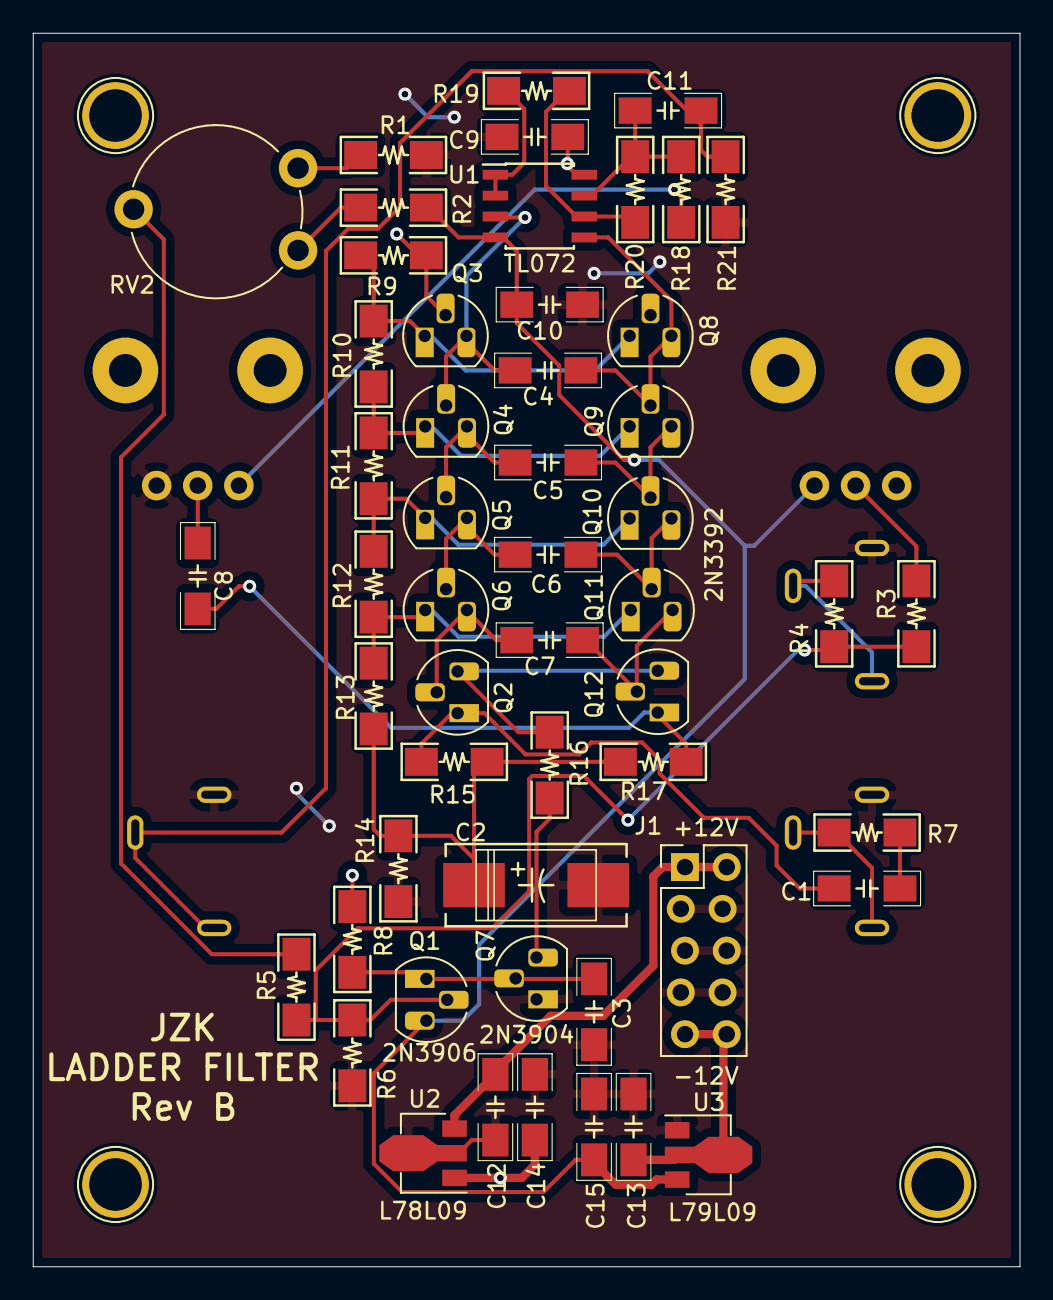
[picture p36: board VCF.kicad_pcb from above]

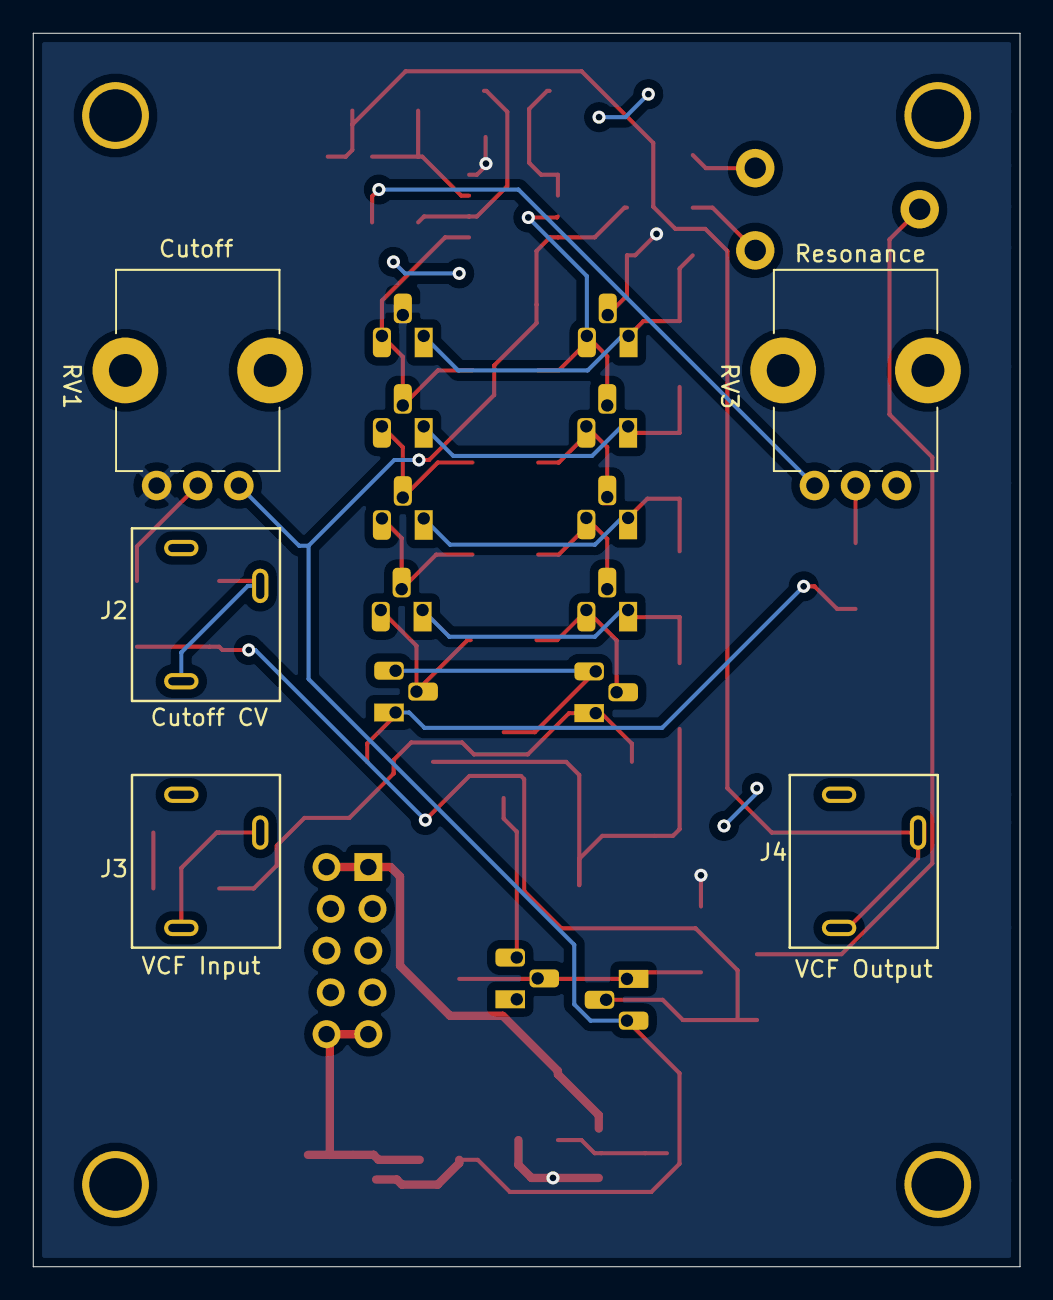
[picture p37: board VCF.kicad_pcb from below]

Board: 2 copper layers, 60.0 x 75.0 mm, 62 parts (5 on the bottom side), 37 nets.

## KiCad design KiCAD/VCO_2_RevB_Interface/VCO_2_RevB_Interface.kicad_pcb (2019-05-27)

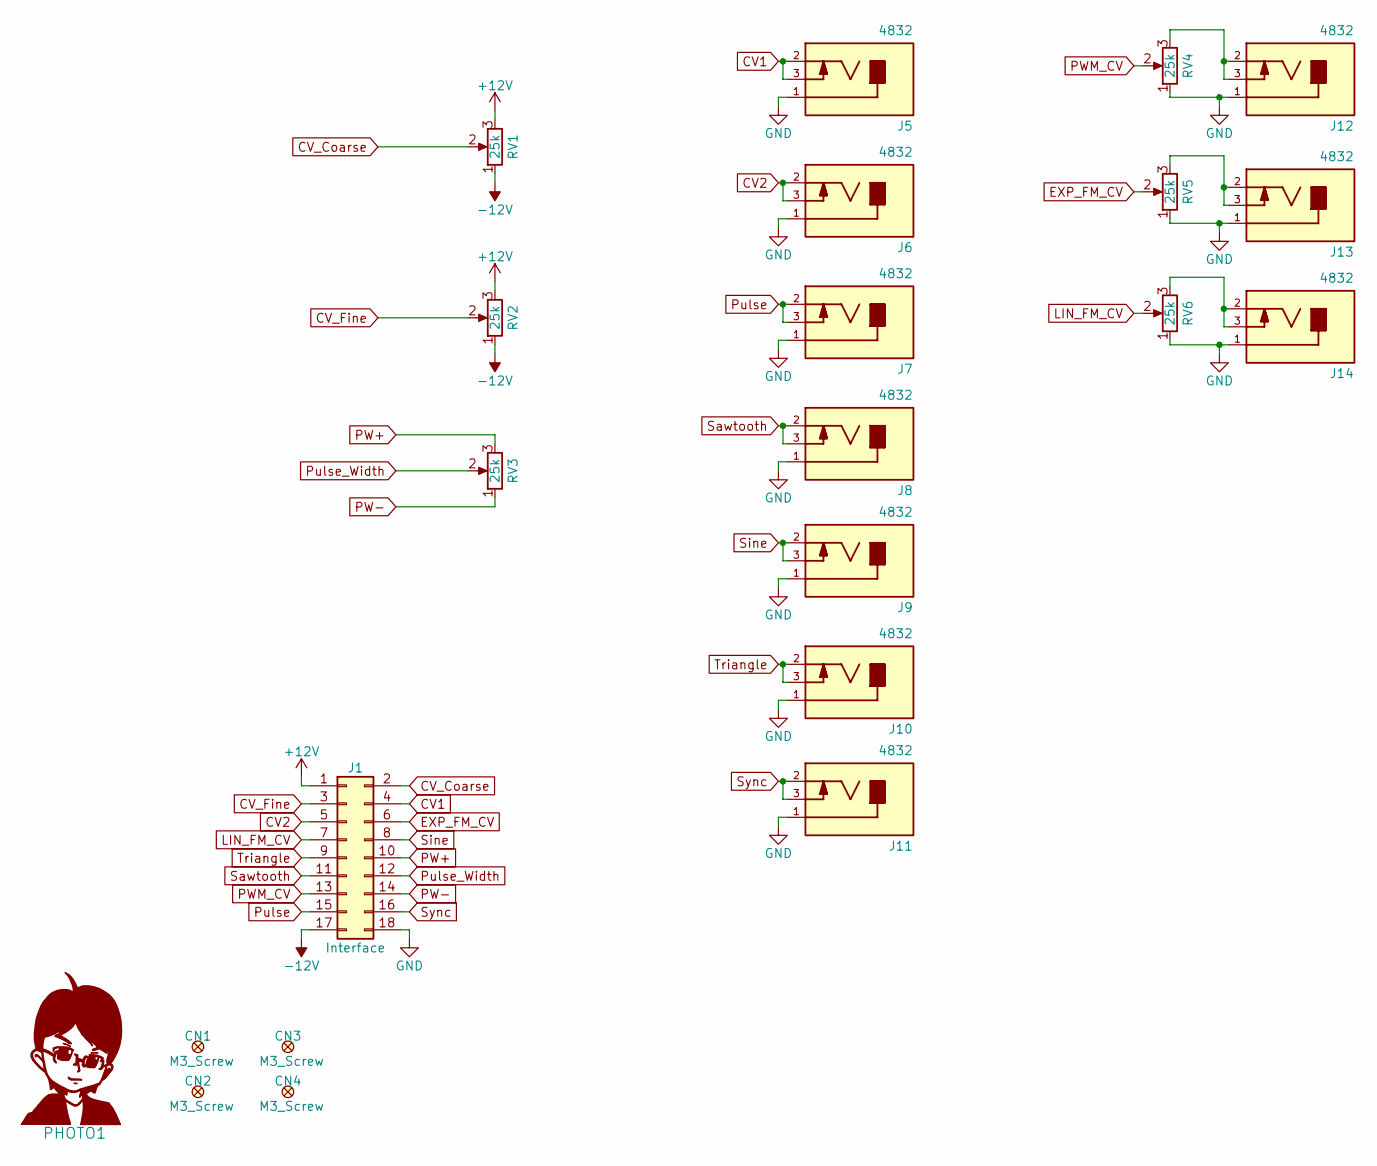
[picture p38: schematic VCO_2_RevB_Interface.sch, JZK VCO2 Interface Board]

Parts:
CN1, CN2, CN3, CN4: M3_Screw; M3_Screw_Hole; Digikey Link N/A
J1: Interface; PinHeader_2x09_P2.54mm_Vertical_Zigzag; Digikey Link N/A
J5, J6, J7, J8, J9, J10, J11, J12, J13, J14: 4832; Schurter_4832_Jack; Digikey PN 486-3418-ND
PHOTO1: ChibiHead; Digikey Link N/A
RV1, RV2, RV3, RV4, RV5, RV6: 25k; Potentiometer_Bourns_PTV09A-1_Single_Vertical; Digikey PN PTV09A-4020F-B203-ND

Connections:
+12V: J1.1, RV1.3, RV2.3
-12V: J1.17, RV1.1, RV2.1
CV1: J1.4, J5.2, J5.3
CV2: J1.5, J6.2, J6.3
CV_Coarse: J1.2, RV1.2
CV_Fine: J1.3, RV2.2
EXP_FM_CV: J1.6, RV5.2
GND: J1.18, J5.1, J6.1, J7.1, J8.1, J9.1, J10.1, J11.1, J12.1, J13.1, J14.1, RV4.1, RV5.1, RV6.1
LIN_FM_CV: J1.7, RV6.2
unnamed: J12.2, J12.3, RV4.3
unnamed: J13.2, J13.3, RV5.3
unnamed: J14.2, J14.3, RV6.3
PW+: J1.10, RV3.3
PW-: J1.14, RV3.1
PWM_CV: J1.13, RV4.2
Pulse: J1.15, J7.2, J7.3
Pulse_Width: J1.12, RV3.2
Sawtooth: J1.11, J8.2, J8.3
Sine: J1.8, J9.2, J9.3
Sync: J1.16, J11.2, J11.3
Triangle: J1.9, J10.2, J10.3

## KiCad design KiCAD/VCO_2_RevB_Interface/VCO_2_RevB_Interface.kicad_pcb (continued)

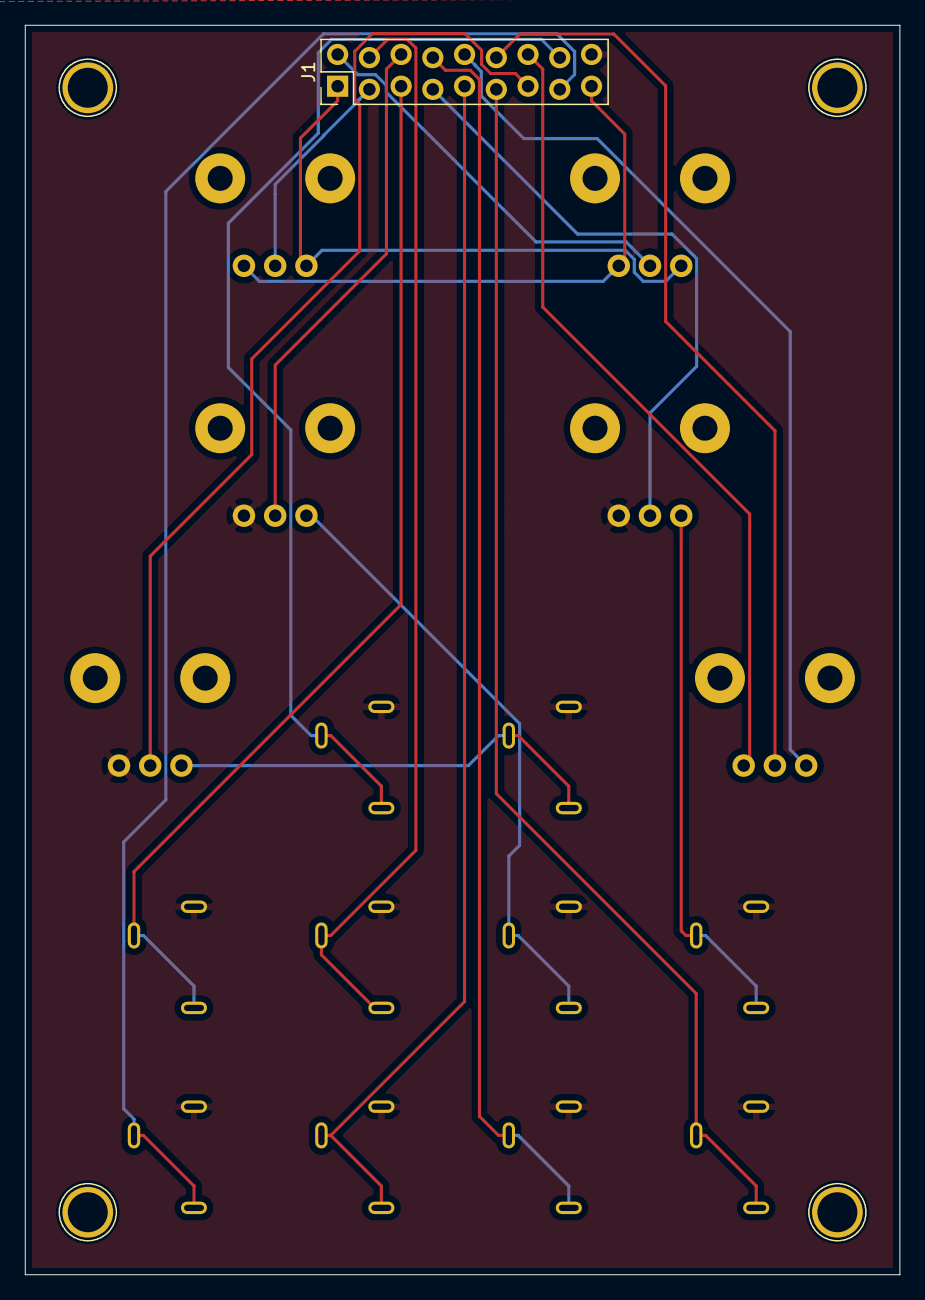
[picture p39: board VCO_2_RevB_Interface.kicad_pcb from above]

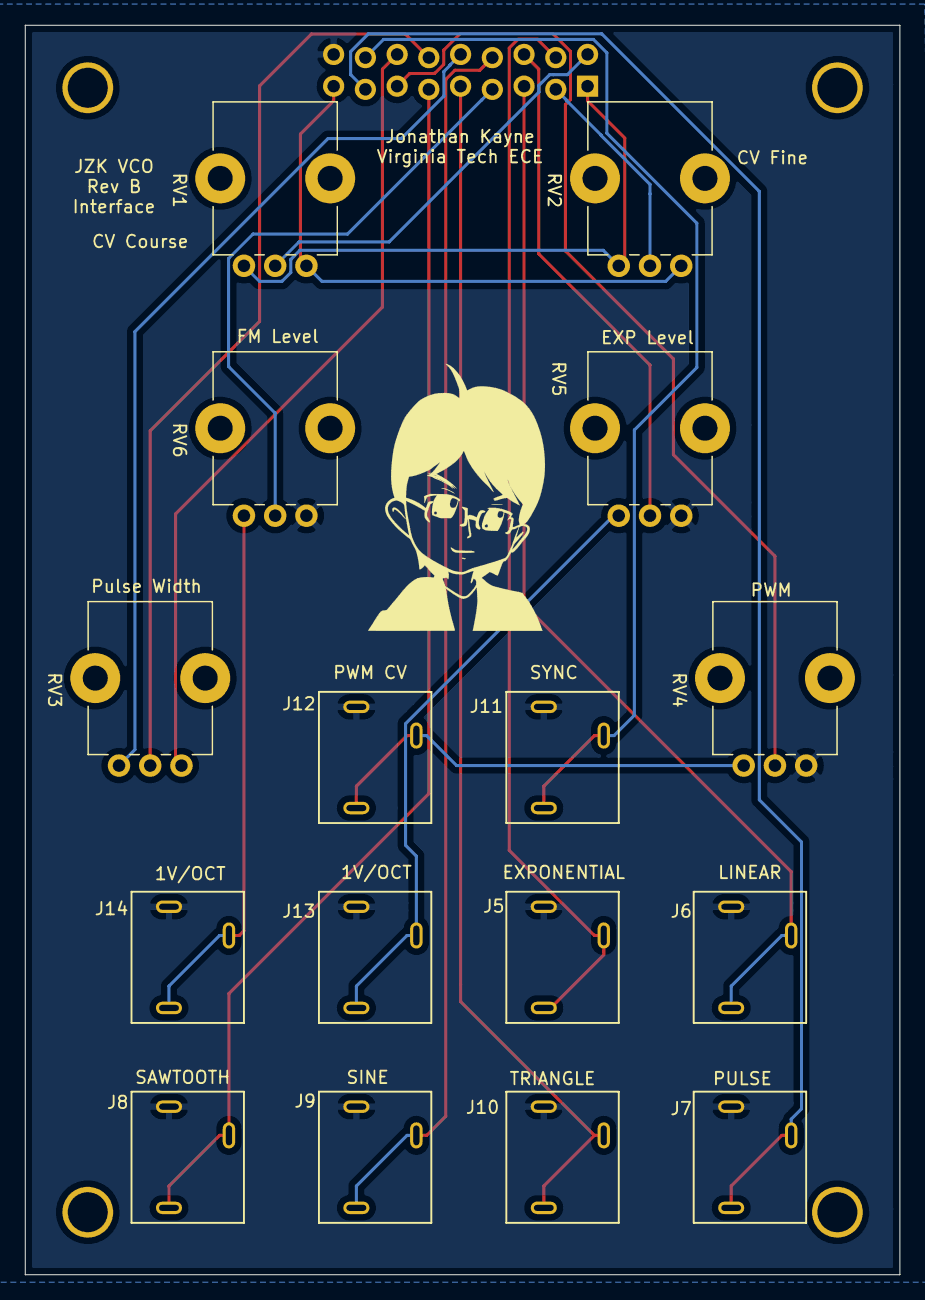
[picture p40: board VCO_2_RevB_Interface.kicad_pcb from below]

Board: 2 copper layers, 70.0 x 100.0 mm, 22 parts (17 on the bottom side), 21 nets.

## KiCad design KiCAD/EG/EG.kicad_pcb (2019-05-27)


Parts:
C1, C2, C5: 0.1uF; C_1206; Digikey PN 720-1540-1-ND
C3, C4: 10nF; C_1206; Digikey PN 311-1174-1-ND
C6: 10uF; CP_Tantalum_7343; Digikey PN 718-1046-1-ND
CN1, CN2, CN3, CN4: M3_Screw; M3_Screw_Hole; Digikey Link N/A
D1, D2, D3, D4, D5: 1N4148W; D_SOD-123; Digikey PN 1N4148WTPMSCT-ND
D6: LED; LED_D3.0mm_Clear; Digikey Link N/A
J1: Power; PinHeader_2x05_P2.54mm_Vertical_Zigzag; Digikey PN 609-3243-ND
J2, J3: 4832; Schurter_4832_Jack; Digikey PN 486-3418-ND
Q1, Q2, Q3: BC847; SOT-23_Handsoldering; Digikey PN BC847CLT1GOSCT-ND
Q4: 2N7002; SOT-23_Handsoldering; Digikey PN 2N7002NCT-ND
R1: 1.2M; R_1206; Digikey PN 311-1.20MFRCT-ND
R2, R8: 1M; R_1206; Digikey PN RMCF1206JT1M00CT-ND
R3, R5, R6, R7: 22k; R_1206; Digikey PN A130554CT-ND
R4: 10; R_1206; Digikey PN P10ALCT-ND
R9: 4.7k; R_1206; Digikey PN A130181CT-ND
R10, R11, R12: 100; R_1206; Digikey PN RNCP1206FTD100RCT-ND
R13, R14: 1k; R_1206; Digikey PN 311-1.0KERCT-ND
RV1: 25k; Potentiometer_Bourns_PTV09A-1_Single_Vertical; Digikey PN PTV09A-4020F-B203-ND
RV2, RV3, RV4: 1M Log; Potentiometer_Bourns_PTV09A-1_Single_Vertical; Digikey PN PTV09A-4020F-A504-ND
U1: TL074; SOIC-14_3.9x8.7mm_P1.27mm; Digikey PN 296-1283-1-ND
U2: NE555; SOIC-8_3.9x4.9mm_P1.27mm; Digikey PN 296-6501-1-ND

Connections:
+12V: C1.1, C5.2, J1.1, J1.2, R3.1, R5.1, R7.1, R9.1, U1.4 (V+), U2.8 (VCC)
-12V: C2.2, J1.9, J1.10, U1.11 (V-)
/Attack: R11.2, RV2.2
/Decay: R12.1, RV4.2
/Release: R10.2, RV3.2
/Sustain: RV1.2, U1.3 (+)
ADSR_Out: J3.2, J3.3, R14.1
EG_Out: R13.2, R14.2, U1.6 (-), U1.7, U2.6 (THR)
GND: C1.2, C2.1, C4.2, C5.1, C6.2, D1.2 (A), J1.3, J1.4, J1.5, J1.6, J1.7, J1.8, J2.1, J3.1, Q3.2 (E), R1.2, R4.2, R6.2, U1.10 (+), U2.1 (GND)
Gate_In: J2.2, J2.3, R1.1, R2.2
unnamed: C3.1, Q3.1 (B), R6.1
unnamed: C3.2, D2.1 (K), Q2.3 (C), R5.2, R8.2, U2.4 (R)
unnamed: C4.1, U2.5 (CV)
unnamed: C6.1, D4.1 (K), R10.1, R12.2, U1.5 (+)
unnamed: D1.1 (K), Q1.1 (B), R2.1
unnamed: D2.2 (A), RV3.1
unnamed: D3.1 (K), U1.1, U1.2 (-)
unnamed: D3.2 (A), RV4.3
unnamed: D4.2 (A), R11.1
unnamed: D5.1 (K), D6.2 (A), R13.1, U1.9 (-)
unnamed: D5.2 (A), D6.1 (K), U1.8
unnamed: Q1.2 (E), Q2.2 (E), R4.1
unnamed: Q1.3 (C), Q2.1 (B), R3.2
unnamed: Q3.3 (C), R7.2, U2.2 (TR)
unnamed: Q4.1 (G), R8.1
unnamed: Q4.2 (S), U2.7 (DIS)
unnamed: Q4.3 (D), RV1.1
unnamed: R9.2, RV1.3
unnamed: RV2.1, U2.3 (Q)

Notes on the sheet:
LED Indicator



Board: 2 copper layers, 40.0 x 100.0 mm, 43 parts (7 on the bottom side), 29 nets.

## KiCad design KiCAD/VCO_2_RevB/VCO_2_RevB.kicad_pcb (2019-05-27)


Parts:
C1, C2, C3, C10, C11: 100nF; C_1206; Digikey PN 720-1540-1-ND
C4: 100pF; C_1206; Digikey PN 445-2336-1-ND
C5: 220pF; C_1206; Digikey PN 445-2338-1-ND
C6, C12, C13: 47pF; C_1206; Digikey PN 1276-3270-1-ND
C7, C8: 22uF; CP_Tantalum_7343; Digikey PN 478-3923-1-ND
C9: 10pF; C_1206; Digikey PN 311-1150-1-ND
CN1, CN2, CN3, CN4: M3_Screw; M3_Screw_Hole; Digikey Link N/A
D1, D2, D3, D4: 1N4148W; D_SOD-123; Digikey PN 1N4148WTPMSCT-ND
D5: BAV99; SOT-23; Digikey PN BAV99LT1GOSCT-ND
J1: Interface; PinHeader_2x09_P2.54mm_Vertical_Zigzag; Digikey Link N/A
J7: Power; PinHeader_2x05_P2.54mm_Vertical_Zigzag; Digikey PN 609-3243-ND
PHOTO1: ChibiHead; Digikey Link N/A
Q1: BC847BS; SOT-363_SC-70-6; Digikey PN BC847BS-7FDICT-ND
Q2: MMBFJ112; SOT-23; Digikey PN MMBFJ112CT-ND
R1, R2, R3, R11, R12, R18, R28, R31, R33, R34, R36, R38, R41: 100k; R_1206; Digikey PN A129834CT-ND
R4: 3.3M; R_1206; Digikey PN P3.3MECT-ND
R5, R32: 220k; R_1206; Digikey PN A129838CT-ND
R6, R37: 470k; R_1206; Digikey PN RMCF1206JT470KCT-ND
R7: 68k; R_1206; Digikey PN 311-68KERCT-ND
R8, R39: 50k; R_1206; Digikey PN 311-49.9KFRCT-ND
R9: 47k; R_1206; Digikey PN RMCF1206JT47K0CT-ND
R10, R19: 33k; R_1206; Digikey PN RMCF1206JT33K0CT-ND
R13, R49: 22k; R_1206; Digikey PN A130554CT-ND
R14: 1k Tempco; Tempco_Resistor_SOT363; Digikey PN 615-1103-ND
R15, R16, R20: 1M; R_1206; Digikey PN RMCF1206JT1M00CT-ND
R17, R25, R27, R29, R35, R42: 10k; R_1206; Digikey PN RMCF1206JT10K0CT-ND
R21, R22: 7.5k; R_1206; Digikey PN 311-7.5KERCT-ND
R23, R24: 10; R_1206; Digikey PN P10ALCT-ND
R26: 5.6k; R_1206; Digikey PN 311-5.6KERCT-ND
R30: 180k; R_1206; Digikey PN 311-180KERCT-ND
R40, R47: 150k; R_1206; Digikey PN 311-150KERCT-ND
R43: 200k; R_1206; Digikey PN CR1206-FX-2003ELFCT-ND
R44: 4.7k; R_1206; Digikey PN A130181CT-ND
R45, R46, R51, R52: 1k; R_1206; Digikey PN 311-1.0KERCT-ND
R48: 1.5k; R_1206; Digikey PN RMCF1206JT1K50CT-ND
R50: 15k; R_1206; Digikey PN RMCF1206JT15K0CT-ND
RV1: 220k; Potentiometer_Piher_PT-10-V10_Vertical; Digikey PN 1993-1067-ND
RV2: 25k; Potentiometer_Piher_PT-10-V10_Vertical; Digikey PN 1993-1086-ND
RV4: 100k; Potentiometer_Piher_PT-10-V10_Vertical; Digikey PN 1993-1082-ND
RV5: 10k; Potentiometer_Piher_PT-10-V10_Vertical; Digikey PN 1993-1104-ND
RV6: 47k; Potentiometer_Piher_PT-10-V10_Vertical; Digikey PN 1993-1089-ND
U1, U2: TL074; SOIC-14_3.9x8.7mm_P1.27mm; Digikey PN 296-1283-1-ND
U3: OPA2137; SOIC-8_3.9x4.9mm_P1.27mm; Digikey PN OPA2137UA-ND
U4: LM311; SOIC-8_3.9x4.9mm_P1.27mm; Digikey PN LM311MNS/NOPB-ND
U5: L78L12_SOT89; SOT-89-3; Digikey PN 497-1195-1-ND
U6: L79L12_SOT89; SOT-89-3; Digikey PN 497-7301-1-ND

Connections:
+12V: C1.1, C2.1, C7.1, J1.1, R21.1, R23.2, RV1.1, RV6.1, U1.4 (V+), U2.4 (V+)
+12VA: C3.1, C10.1, R7.1, R19.1, U3.8 (V+), U4.5 (BAL), U4.6 (STRB), U4.8 (V+), U5.1 (OUT)
+12V_IN: J7.1, J7.2, R23.1, U5.3 (IN)
-12V: C1.2, C2.2, C8.2, J1.17, R22.2, R24.2, R26.2, RV1.3, U1.11 (V-), U2.11 (V-)
-12VA: C3.2, C11.2, U3.4 (V-), U4.1 (GND), U4.4 (V-), U6.3 (VO)
-12V_IN: J7.9, J7.10, R24.1, U6.2 (VI)
CV_Coarse: J1.2, R5.2
CV_Fine: J1.3, R4.2
EXP_CV1: J1.4, R2.2
EXP_CV2: J1.5, R3.2
EXP_FM_CV: J1.6, R1.2
GND: C7.2, C8.1, C10.2, C11.1, D5.1 (A), D5.2 (K), J1.18, J7.3, J7.4, J7.5, J7.6, J7.7, J7.8, Q1.5 (B2), R8.2, R9.2, R12.2, R14.2, R27.2, R37.2, R44.2, R48.2, R49.2, RV5.3, RV6.3, U1.5 (+), U1.10 (+), U2.3 (+), U2.12 (+), U5.2 (GND), U6.1 (GND)
Hard_SYNC: C12.2, R29.1
LIN_FM_CV: J1.7, R11.2
unnamed: C4.1, R17.2, U3.7
unnamed: C4.2, Q1.6 (C1), R11.1, R16.2, U3.6 (-)
unnamed: C5.1, Q2.1 (S), R16.1, R18.2, U1.1, U1.2 (-)
unnamed: C5.2, Q1.3 (C2), Q2.2 (D), U2.5 (+)
unnamed: C6.1, C9.2, D2.1 (K), R19.2, R20.2, U4.7
unnamed: C6.2, D2.2 (A), Q2.3 (G), R18.1
unnamed: C9.1, R20.1, R27.1, R29.2, U4.2 (+)
unnamed: C13.1, R43.1, R47.2, R51.2, U1.8
unnamed: C13.2, R34.1, R39.2, R40.2, R43.2, U1.9 (-)
unnamed: D1.1 (K), R15.2
unnamed: D1.2 (A), Q1.2 (B1), R13.2, R14.1
unnamed: D3.1 (K), R33.1, R36.2, U1.6 (-)
unnamed: D3.2 (A), D4.1 (K), U1.7
unnamed: D4.2 (A), R36.1, R39.1
unnamed: D5.3 (K), R47.1, R49.1, U1.12 (+)
unnamed: Q1.1 (E1), Q1.4 (E2), R15.1, R17.1
unnamed: R1.1, R2.1, R3.1, R4.1, R5.1, R6.1, R10.2, U3.2 (-)
unnamed: R6.2, RV1.2
unnamed: R7.2, R8.1, U1.3 (+)
unnamed: R9.1, U3.3 (+)
unnamed: R10.1, RV2.3
unnamed: R12.1, U3.5 (+)
unnamed: R13.1, RV2.1, RV2.2, U3.1
unnamed: R25.1, U4.3 (-)
unnamed: R25.2, RV4.3, U2.6 (-), U2.7
unnamed: R26.1, RV5.1
unnamed: R28.1, R32.2, RV4.1, RV4.2, U2.2 (-)
unnamed: R28.2, RV5.2
unnamed: R30.1, R31.1, R37.1, U2.10 (+)
unnamed: R32.1, R33.2, R34.2, R35.2, R38.2, U2.1
unnamed: R35.1, U2.9 (-)
unnamed: R38.1, R41.2, U2.13 (-)
unnamed: R40.1, RV6.2
unnamed: R41.1, R45.2, U2.14
unnamed: R42.1, R44.1, R46.2
unnamed: R42.2, U2.8
unnamed: R48.1, R50.2, U1.13 (-)
unnamed: R50.1, R52.2, U1.14
PW+: J1.10, R21.2
PW-: J1.14, R22.1
PWM_CV: J1.13, R30.2
Pulse: J1.15, R46.1
Pulse_Width: J1.12, R31.2
Sawtooth: J1.11, R45.1
Sine: J1.8, R52.1
Soft_SYNC: C12.1, J1.16
Triangle: J1.9, R51.1

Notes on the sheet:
Saw Vert Balance
Sine Peak
Sine/Tri Symmetry
CV Adjust
Freq Adjust


Board: 2 copper layers, 70.0 x 100.0 mm, 90 parts (0 on the bottom side), 61 nets.

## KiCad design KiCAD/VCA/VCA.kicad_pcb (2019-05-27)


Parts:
C1, C2: 0.22uF; C_1206; Digikey PN 445-2283-1-ND
C3, C4, C5: 10pF; C_1206; Digikey PN 311-1150-1-ND
C6, C7, C8, C9, C10, C11: 0.1uF; C_1206; Digikey PN 720-1540-1-ND
CN1, CN2, CN3, CN4: M3_Screw; M3_Screw_Hole; Digikey Link N/A
J1, J2, J3, J4, J5, J7: Schurter_4832_Jack; Digikey PN 486-3418-ND
J6: Power; PinHeader_2x05_P2.54mm_Vertical_Zigzag; Digikey PN 609-3243-ND
Q1, Q2: MMBT3906; SOT-23_Handsoldering; Digikey PN MMBT3906LT1GOSCT-ND
R1, R9: 270k; R_1206; Digikey PN A129839CT-ND
R2, R4, R5, R6, R7, R10, R11, R12, R13, R15, R16, R23: 100k; R_1206; Digikey PN A129834CT-ND
R3: 330k; R_1206; Digikey PN P330KBCCT-ND
R8: 4.7k; R_1206; Digikey PN A130181CT-ND
R14, R19: 10k; R_1206; Digikey PN RMCF1206JT10K0CT-ND
R17, R18, R20, R21: 220; R_1206; Digikey PN 311-220FRCT-ND
R22: 22k; R_1206; Digikey PN A130554CT-ND
R24: 1k; R_1206; Digikey PN 311-1.0KERCT-ND
RV1, RV2, RV3, RV4, RV5, RV6, RV7: 100k; Potentiometer_Bourns_PTV09A-1_Single_Vertical; Digikey PN PTV09A-4020F-B104-ND
RV8, RV9: 100k; Trimpot_Bourns_3306F; Digikey PN 3306F-104-ND
U1: TL074; SOIC-14_3.9x8.7mm_P1.27mm; Digikey PN 296-1283-1-ND
U2: TL072; SOIC-8_3.9x4.9mm_P1.27mm; Digikey PN 296-1282-1-ND
U3: LM13700; SOIC-16_3.9x9.9mm_P1.27mm; Digikey PN LM13700MX/NOPBCT-ND

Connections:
+12V: C6.1, C8.1, C10.1, J6.1, J6.2, RV1.3, RV2.3, RV8.3, RV9.3, U1.4 (V+), U2.8 (V+), U3.11 (V+)
-12V: C7.2, C9.2, C11.2, J6.9, J6.10, RV1.1, RV2.1, RV8.1, RV9.1, U1.11 (V-), U2.4 (V-), U3.6 (V-)
/Crossfade: R1.2, RV1.2
/CrossfadeCV: J1.3, RV3.3
/Input1: J2.3, RV4.3
/Input2: J3.3, RV5.3
/VCA_CV: R3.2, RV2.2
/VCA_CV1: J4.3, RV6.3
/VCA_CV2: J5.3, RV7.3
/VCA_Out: J7.3, R24.1
GND: C6.2, C7.1, C8.2, C9.1, C10.2, C11.1, J1.1, J2.1, J3.1, J4.1, J5.1, J6.3, J6.4, J6.5, J6.6, J6.7, J6.8, J7.1, Q2.1 (B), R17.2, R18.2, R20.2, R21.2, RV3.1, RV4.1, RV5.1, RV6.1, RV7.1, U1.3 (+), U1.5 (+), U1.10 (+), U1.12 (+), U2.3 (+), U2.5 (+)
unnamed: C1.1, R6.2
unnamed: C1.2, RV4.2
unnamed: C2.1, R7.2
unnamed: C2.2, RV5.2
unnamed: C3.1, R10.1, R12.2, U1.1
unnamed: C3.2, R6.1, R10.2, U1.2 (-)
unnamed: C4.1, R11.1, R13.2, U1.7
unnamed: C4.2, R7.1, R11.2, U1.6 (-)
unnamed: C5.1, R23.1, R24.2, U1.14
unnamed: C5.2, R23.2, U1.13 (-), U3.5, U3.12
unnamed: Q1.1 (B), R8.1, U1.8
unnamed: Q1.3 (C), U3.1
unnamed: Q2.3 (C), U3.16
unnamed: R1.1, R2.1, R8.2, U1.9 (-)
unnamed: R2.2, RV3.2
unnamed: R3.1, R4.1, R5.1, R9.2, U2.2 (-)
unnamed: R4.2, RV6.2
unnamed: R5.2, RV7.2
unnamed: R12.1, R17.1, U3.3 (+)
unnamed: R13.1, R18.1, U3.14 (+)
unnamed: R14.1, R19.2, U2.6 (-)
unnamed: R9.1, R14.2, U2.1
unnamed: R15.1, R20.1, U3.4 (-)
unnamed: R15.2, RV8.2
unnamed: R16.1, R21.1, U3.13 (-)
unnamed: R16.2, RV9.2
unnamed: R19.1, R22.2, U2.7
VCA_Gain: Q1.2 (E), Q2.2 (E), R22.1



Board: 2 copper layers, 50.0 x 100.0 mm, 60 parts (13 on the bottom side), 39 nets.

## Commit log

2019-05-06 Added VCO
    [Connectors.sch, VCO_2.csv, VCO_2.kicad_pcb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]
2019-05-07 updated VCO2
    [VCO_2-B_Cu.gbl, VCO_2-B_Mask.gbs, VCO_2-B_SilkS.gbo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]
2019-05-07 Update render
    [VCO_2.kicad_pcb]
2019-05-11 added VCF
    [VCF BOM.xlsx, VCF Bom - Digikey.csv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]
2019-05-12 added voltage regulator to VCF
    [VCF BOM.xlsx, VCF Digikey BOM.csv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]
2019-05-17 update EG
    [EG BOM Digikey.csv, EG BOM.xlsx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]
2019-05-18 added MIDI Controller
    [MIDI Controller BOM.xlsx, MIDI Controller Digikey BOM.csv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]
2019-05-27 Added RevB and VCA
    [Connectors.sch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]
2019-05-27 update pics
    [EG BOM Digikey.csv, EG BOM.xlsx, VCF BOM.xlsx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]
2019-05-29 Added MIDI controller and PSU
    [MIDI Controller-B_Cu.gbl, MIDI Controller-B_Mask.gbs, MIDI Controller-B_SilkS.gbo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]
